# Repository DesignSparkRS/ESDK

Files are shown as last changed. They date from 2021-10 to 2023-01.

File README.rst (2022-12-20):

Environmental Sensor Development Kit (ESDK)
===========================================

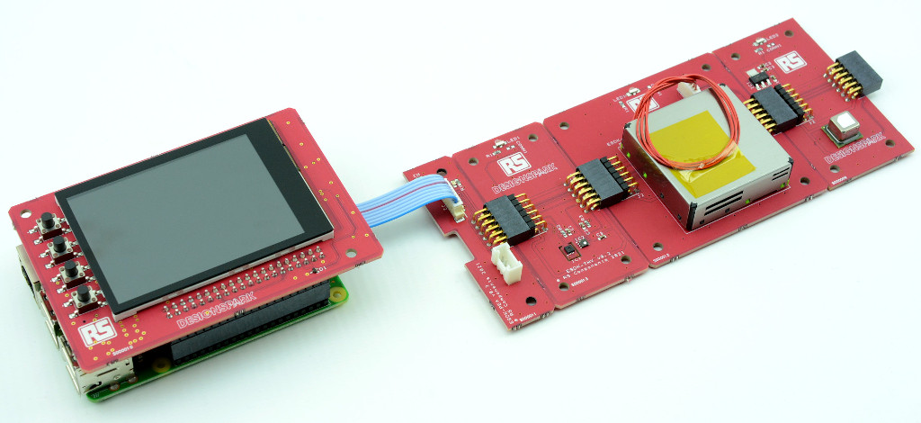
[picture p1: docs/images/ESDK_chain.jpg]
ESDK System


The Environmental Sensor Development Kit (ESDK) is an open source hardware
platform that is designed to make it as easy as possible to prototype custom
sensor solutions. It has been created to support the engineer activism Air
Quality project, but could easily be put to use in other sensing projects — and
for that matter, potentially a great many more IoT and wider applications that
have a need for a small Linux computer with integrated touchscreen and GPS etc.

Components
----------

The system is based upon a Raspberry Pi SBC fitted with the ESDK-Main board, which provides a touch screen, physical buttons, RTC, buzzer and sensor power supply. This is then connected to a sensor chain, with sensors interfaced via I2C and/or plain GPIO. 

Hardware Designs 
----------------

The ESDK hardware designs are entered using `DesignSpark PCB`_. 

The original design files and manufacturing outputs may be found in the GitHub repository:

https://github.com/DesignSparkRS/ESDK

Project Documentation
---------------------

Documentation is available on `docs.designspark.io`_.

Licensing
=========

Hardware
--------

Copyright 2021-2022 RS Components Ltd
SPDX-License-Identifier: Apache-2.0 WITH SHL-2.1

Licensed under the Solderpad Hardware License v 2.1 (the “License”); you may not
use this file except in compliance with the License, or, at your option, the
Apache License version 2.0. You may obtain a copy of the License at

https://solderpad.org/licenses/SHL-2.1/

Unless required by applicable law or agreed to in writing, any work distributed
under the License is distributed on an “AS IS” BASIS, WITHOUT WARRANTIES OR
CONDITIONS OF ANY KIND, either express or implied. See the License for the
specific language governing permissions and limitations under the License.

Software
--------

Copyright 2021 RS Components Ltd and provided under the MIT License.

Documentation
-------------

Copyright 2021-2022 RS Components Ltd and provide under the Creative Commons Attribution 4.0 International (CC BY 4.0) license.

.. _DesignSpark PCB: https://www.rs-online.com/designspark/pcb-software
.. _docs.designspark.io: https://docs.designspark.io/projects/esdk-hardware/en/latest/

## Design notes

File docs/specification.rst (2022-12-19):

ESDK Module Specification
=========================

The ESDK module specification is as follows.

Physical
--------

Two board sizes are currently in use within the ESDK ecosystem, comprising of a "1U" and "2U" variant. A 1U module is 35x70mm and a 2U module is double the width at 70x70mm.

Four corner mounting holes are to be provided, spaced 6mm from each edge. The hole should be 3.2mm diameter, which allows suitable clearance for M3 fastening hardware.

Each corner of the board should be chamfered at a 45° angle, such that the length parallel to the chamfer equates to 2.121mm.

A 3mm keep-out should be present around the edge of the board where no components should be placed — this allows room for the case to sandwich the PCBA. Tracks & vias can however be placed within this zone, being mindful of any PCB fabrication rules specified by a board house.

Connectors
----------

Each ESDK module typically features a male and female 12-pin header. Typically Samtec parts TSW-106-08-G-D-RA and SSW-106-02-G-D-RA are used which form a mating pair. These should be centred on the vertical edge of the PCB with the male header facing left and female facing right. The male header should be positioned such that the pins align with the board edge (but should not protrude over) and the mating face of the female header should protrude 5.53mm beyond the PCB edge.

Connector positioning is somewhat critical to ensure that a solid connection is made, but the parts do not bottom out completely within each other which would increase the risk of damage resulting from knocks and bumps

Power
-----

Two power rails are currently present on the ESDK ecosystem connector — 3.3Vdc and 5Vdc. The 3.3Vdc rail is provided by an LD1117S33 regulator located on ESDK-MAIN and is fused with a 200mA polyfuse. The 5Vdc rail is provided directly from the USB-C power input on ESDK-MAIN and is fused with a 750mA polyfuse. Each supply rail features a TVS diode for additional protection.

Current draw should be kept as low as possible on both 3.3V and 5V rails. Boards that require more current should utilise the 5V rail and add their own local regulation — an example of this is the ESDK-CO2 board that features another LD1117S33 regulator connected to the 5V supply.

A power indicator LED should be present and connected to the module primary supply rail through some form of removable link. Either a Kingbright KPA-3010CGCK right angle green SMD LED for the 3.3V rail, or a Kingbright KPA-3010YC right angle orange SMD LED for the 5V rail.

The power indicator should be positioned at the top of the board with a small gap from the 3mm component setback. The indicator should be horizontally centred on the board.

I/O
---

I/O is usually provided via the I2C bus present that connects to Raspberry Pi I2C1. This bus utilises the pull-ups located on the Raspberry Pi and features a small TVS diode for additional ESD protection.

Two GPIO lines are extended from the Raspberry Pi - GPIO 20 which becomes ESDK GPIO 1 and GPIO 21 which becomes ESDK GPIO 2. These lines are protected by another TVS diode but are otherwise unbuffered and completely at the mercy of software written by a user, so care should be taken when designing a module to provide an adequate interface.

An example of a board that can utilise one of the ESDK GPIO lines is the ESDK-NRD which features an event output connected via a 1K ohm resistor to GPIO 1. The resistor offers some level of protection should the Pi GPIO be configured as a current source and the module GPIO configured as a current sink.

Addressing
----------

All modules with I2C should use unique device addresses. See :doc:`modules/index` for details of those currently in use. If any modules are developed that have address conflicts consider the use of an I2C address translator such as the Analog Devices LTC4316.

.. note::
	I2C address translators have not been tested but should work. Test and verify before designing in!

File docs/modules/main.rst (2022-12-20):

Main Board (Main)
=================

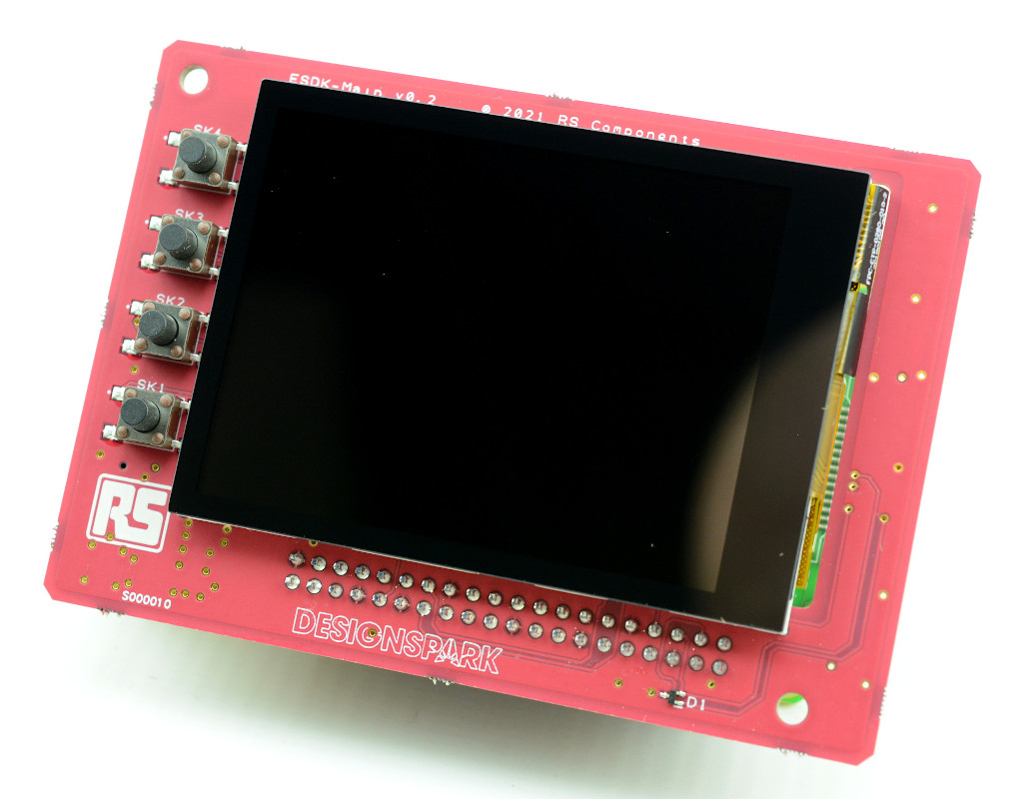
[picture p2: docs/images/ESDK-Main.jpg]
ESDK Main board


Introduction
------------

The Main board plugs into a Raspberry Pi SBC and provides:

* Touch screen
* Four physical buttons
* Battery backed real-time clock (RTC)
* Battery backed GPS
* Buzzer (from board v0.3 onwards)
* Sensor chain 3.3V and 5V power supply (from board v0.3 this is switched by MOSFETs under software control)
* Connector for cable to :doc:`pea`

Schematic diagram
-----------------

ESDK Main schematic diagram

Theory of operation
-------------------

The ESDK-MAIN board connects a number of peripherals to a Raspberry Pi P1 GPIO header including a 320x240 touchscreen over SPI and I2C, a battery-backed RTC connected over I2C, a GPS module connected over a UART (also supporting a 5V active antenna), four front panel buttons connected to GPIO lines, 3.3V and 5V sensor power rails switched by MOSFETs (from board v0.3 onwards), an on-board "HAT" EEPROM connected over I2C and USB-C for 5V power input.

The LCD, touchscreen, RTC and HAT EEPROM connect to I2C 0 on the Raspberry Pi, whereas the sensor string is connected to I2C 1 — this separation aims to avoid issues with the sensor string affecting operation of "system" devices. LCD backlight control is supported in software with further tweaks to the device tree overlay; GPIO 12 does support PWM to be able to adjust the brightness.

A 8-pin Molex PicoBlade connector is present for connection to the ESDK-PEA board that provides an external connector for the sensor modules.

For potential future use, a 5-pin Molex Pico-Lock connector can be used to enable battery expansion. This connector features the 5V rail inbound from the USB-C port, a 5V rail that heads out to the board plus a connection to I2C 0 for smart battery monitoring.

Board layout
------------

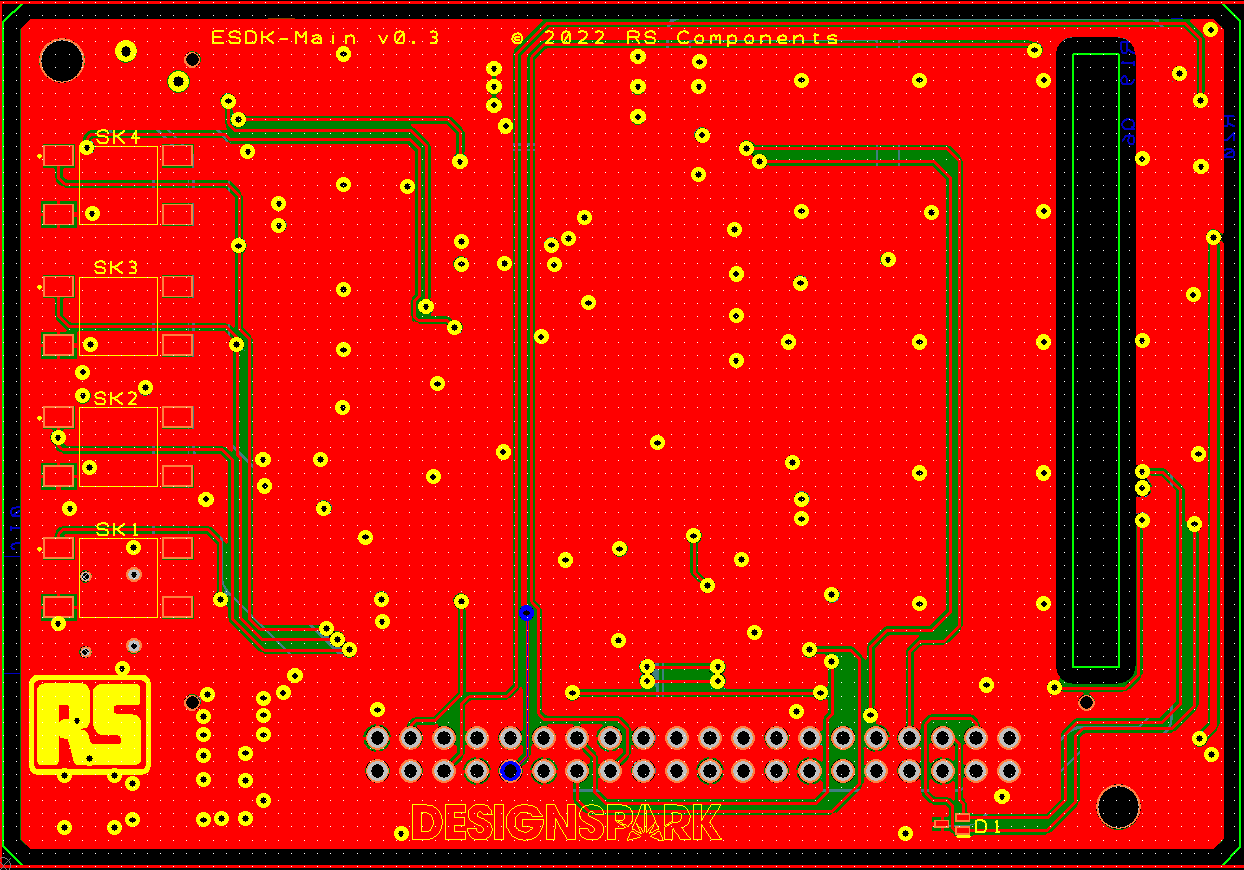
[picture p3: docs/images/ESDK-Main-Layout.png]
ESDK Main board layout


GPIO Assignments
----------------

+-------------------------------------------+-------------------+
| ESDK-MAIN Function                        | Raspberry Pi GPIO |
+===========================================+===================+
| TOUCH_RST                                 | 4                 |
+-------------------------------------------+-------------------+
| TOUCH_INT                                 | 17                |
+-------------------------------------------+-------------------+
| GPS_RESET                                 | 27                |
+-------------------------------------------+-------------------+
| GPS_STBY                                  | 22                |
+-------------------------------------------+-------------------+
| GPS_PPS                                   | 18                |
+-------------------------------------------+-------------------+
| BUTTON_1 (closest to board bottom)        | 5                 |
+-------------------------------------------+-------------------+
| BUTTON_2                                  | 6                 |
+-------------------------------------------+-------------------+
| BUTTON_3                                  | 13                |
+-------------------------------------------+-------------------+
| BUTTON_4 (closest to board top)           | 19                |
+-------------------------------------------+-------------------+
| LCD_RST                                   | 24                |
+-------------------------------------------+-------------------+
| LCD_DC                                    | 25                |
+-------------------------------------------+-------------------+
| LCD_BL                                    | 12                |
+-------------------------------------------+-------------------+
| GPIO_1                                    | 20                |
+-------------------------------------------+-------------------+
| GPIO_2                                    | 21                |
+-------------------------------------------+-------------------+
| SENSOR_3V3_EN (only used on later boards) | 7                 |
+-------------------------------------------+-------------------+
| SENSOR_5V_EN (only used on later boards)  | 16                |
+-------------------------------------------+-------------------+
| BUZZER (only used on later boards)        | 26                |
+-------------------------------------------+-------------------+

* The touchscreen I2C interface is connected to I2C 0
* The module I2C interface is connected to I2C 1
* The LCD is connected to SPI 0
* The GPS is connected to UART "serial0" which is the hardware UART on the Raspberry Pi

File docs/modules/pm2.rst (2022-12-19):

Particulate Matter Sensor (PM2)
===============================

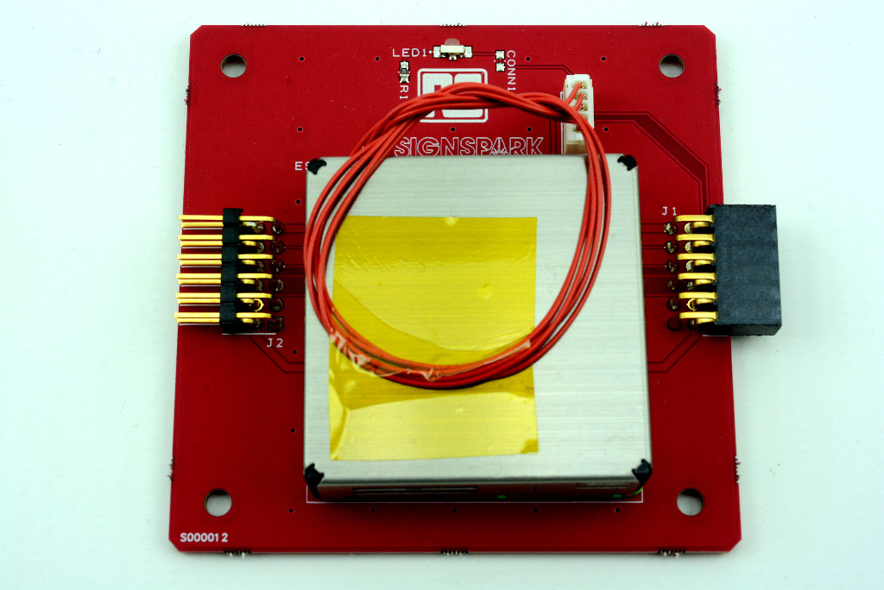
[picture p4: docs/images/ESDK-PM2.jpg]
ESDK PM2 board


Introduction
------------

The ESDK-PM2 features a Sensirion SPS30 particulate matter sensor that can count four different particulate sizes and reports these over an I2C interface.

Schematic diagram
-----------------

ESDK PM2 schematic diagram

Theory of operation
-------------------

The ESDK-PM2 board is primarily a passive board that only serves to convert the connector on the SPS30 sensor module into the ESDK ecosystem connector. The Sensirion SPS30 is capable of measuring PM1.0, PM2.5, PM4.0 and PM10 in densities ranging from 0-1000μg/m\ :sup:`3` with an accuracy up to ±10μg/m\ :sup:`3`.

This utilises a small fan to pull air and particulates through a measurement chamber that takes advantage of laser scattering to be able to count particles. The sensor can report both mass and number concentration, as well as the typical particle size over an I2C interface.

Board layout
------------

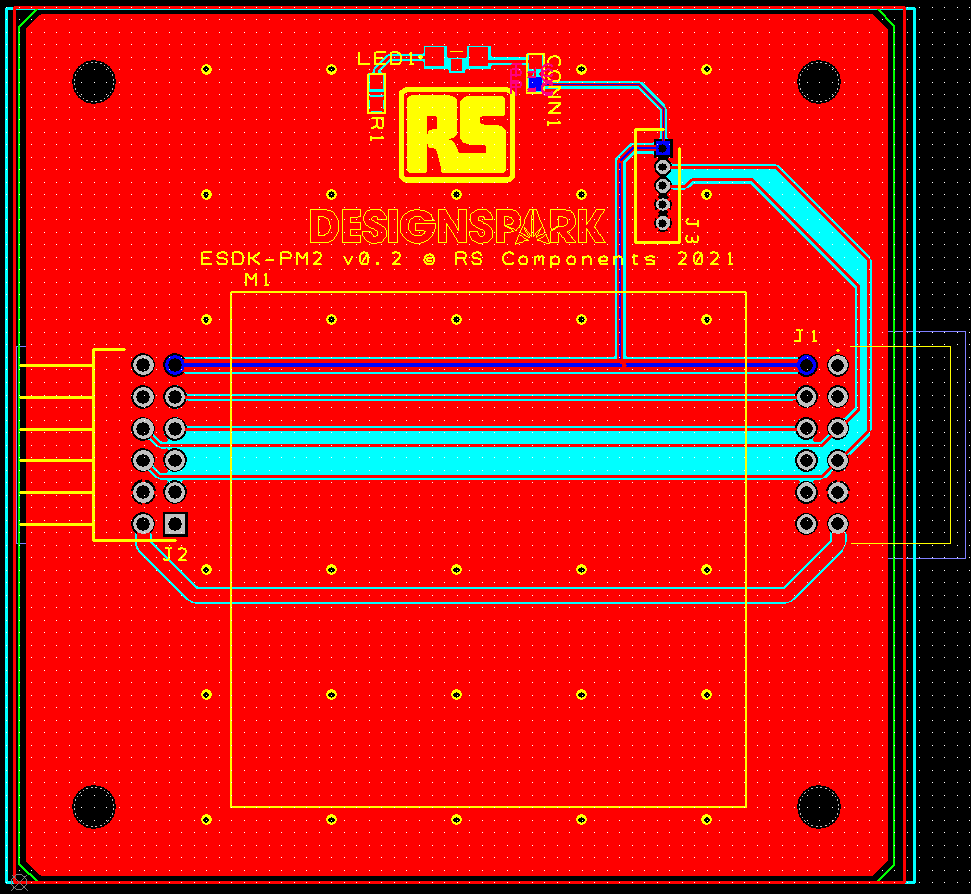
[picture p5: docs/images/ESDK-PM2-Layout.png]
ESDK PM2 board layout


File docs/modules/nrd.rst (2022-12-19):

Nuclear Radiation Detector (NRD)
================================

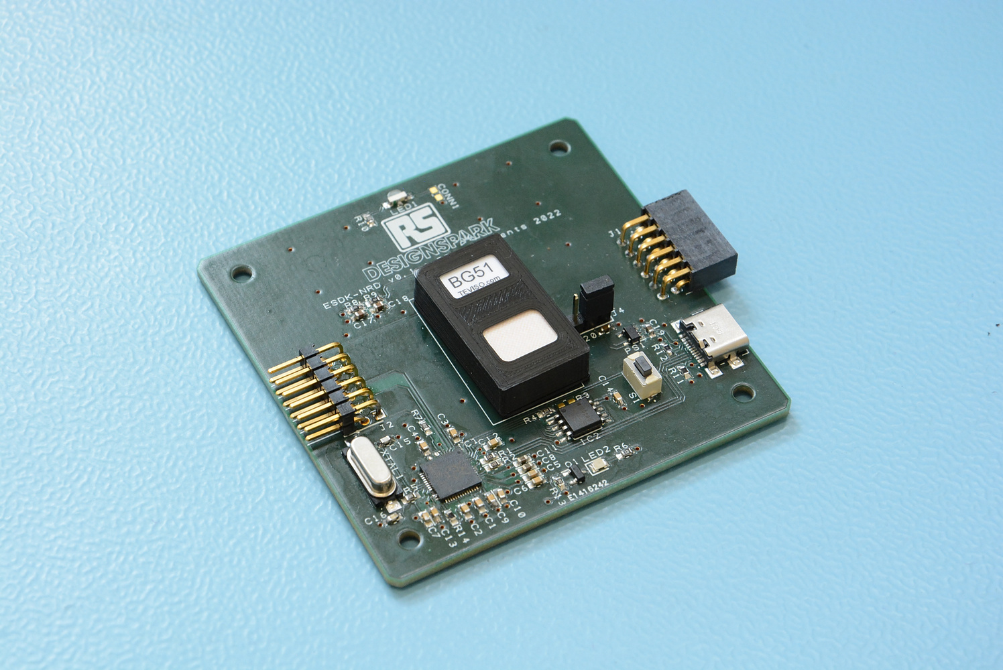
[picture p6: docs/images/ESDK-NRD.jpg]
ESDK NRD board


Introduction
------------

The ESDK-NRD board enables detection of nuclear radiation events, utilising a solid-state sensor that reduces the risk of using a sensing element that requires high voltage.

Schematic diagram
-----------------

ESDK NRD schematic diagram

Theory of operation
-------------------

The ESDK-NRD utilises a Teviso BG51 radiation sensor that is capable of detecting Beta and Gamma radiation. This sensor utilises an array of PIN photodiodes in a housing combined with circuitry to interface with the diodes to produce a TTL level pulse output. To bridge the gap between TTL pulse and I2C bus, a Raspberry Pi RP2040 microcontroller runs a MicroPython application that keeps track of accumulated pulses and exposes a number of registers containing counts per second, per minute and total counts.

A GPIO pin is connected from the RP2040 to an on-board LED that can be software enabled/disabled to provide an indication of a count event. An additional GPIO is connected through a 1K ohm resistor to the ESDK GPIO 1 line allowing for custom triggering to be set up should a user wish to modify the MicroPython application. A USB-C connector provides a USB connection to the RP2040 to allow for easy reprogramming, plus the ability to run the device standalone using a USB virtual com port. A four layer PCB is used to make routing easier and to achieve the required USB differential impedance of 90 ohms.

Board layout
------------

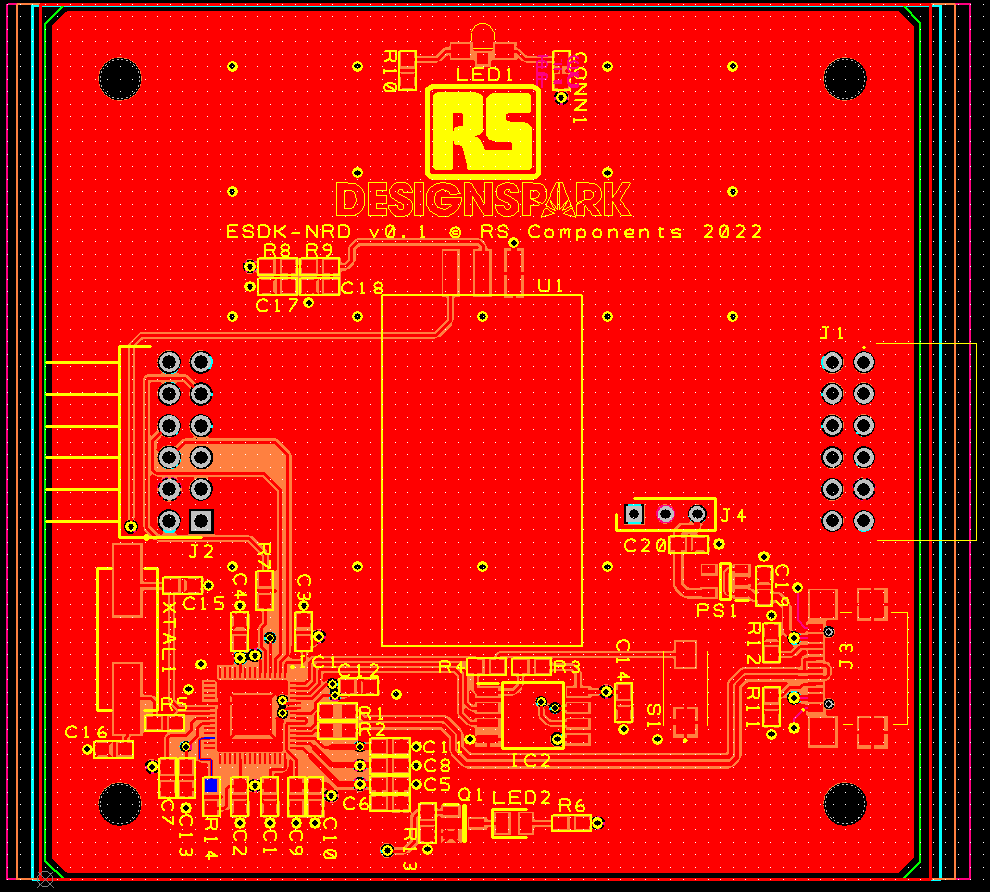
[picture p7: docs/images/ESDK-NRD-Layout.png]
ESDK NRD board layout


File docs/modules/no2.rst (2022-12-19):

Nitrogen Dioxide Sensor (NO2)
=============================

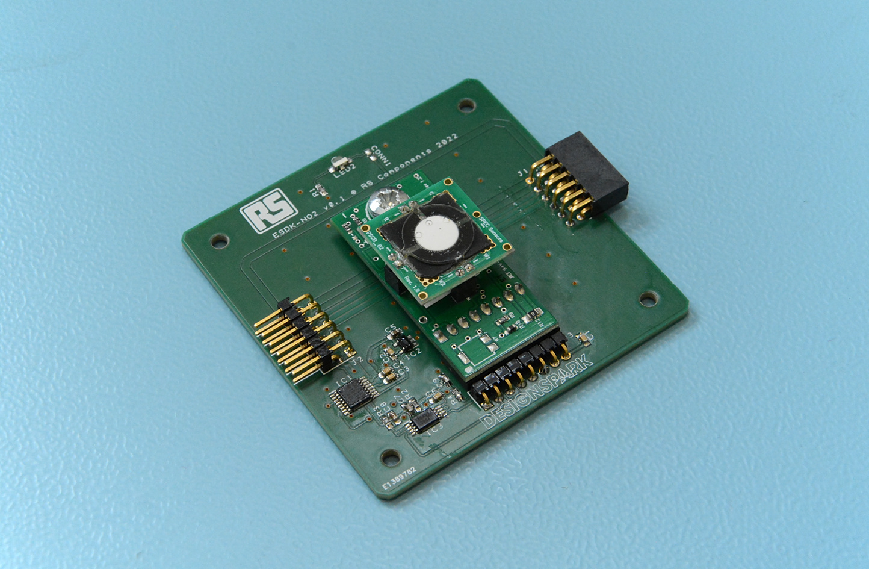
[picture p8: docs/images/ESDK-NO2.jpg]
ESDK NO2 board


Introduction
------------

The ESDK-NO2 board measures atmospheric nitrogen dioxide levels using an electrochemical cell that produces a current from a redox reaction.

Schematic diagram
-----------------

ESDK NO2 schematic diagram

Theory of operation
-------------------

A SPEC Sensors ULPSM-NO2 module provides an interface to the electrochemical cell that converts the current output into a linear voltage output. As this signal from the ULPSM module is high impedance, a unity-gain amplifier configuration buffers the signal before being fed into an ADS1119 16-bit, four channel ADC that is polled over the I2C bus.

Board layout
------------

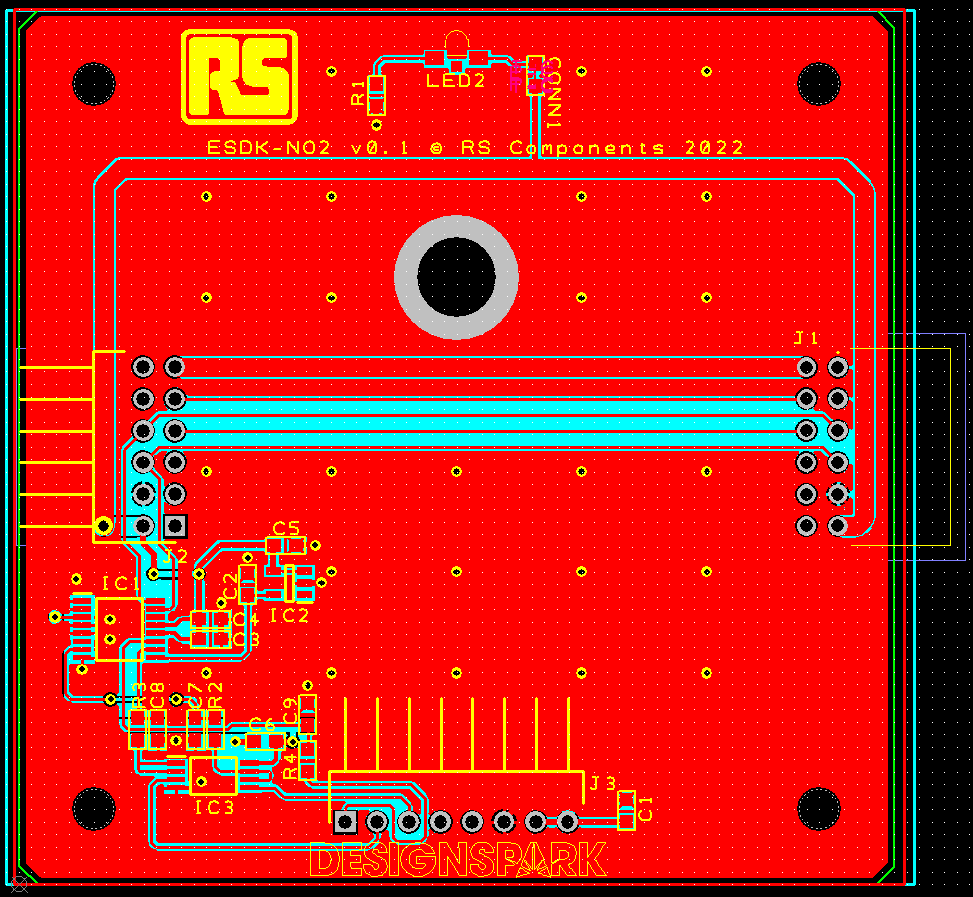
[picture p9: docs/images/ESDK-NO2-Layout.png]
ESDK NO2 board layout


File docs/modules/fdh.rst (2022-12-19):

Formaldehyde Sensor (FDH)
=========================

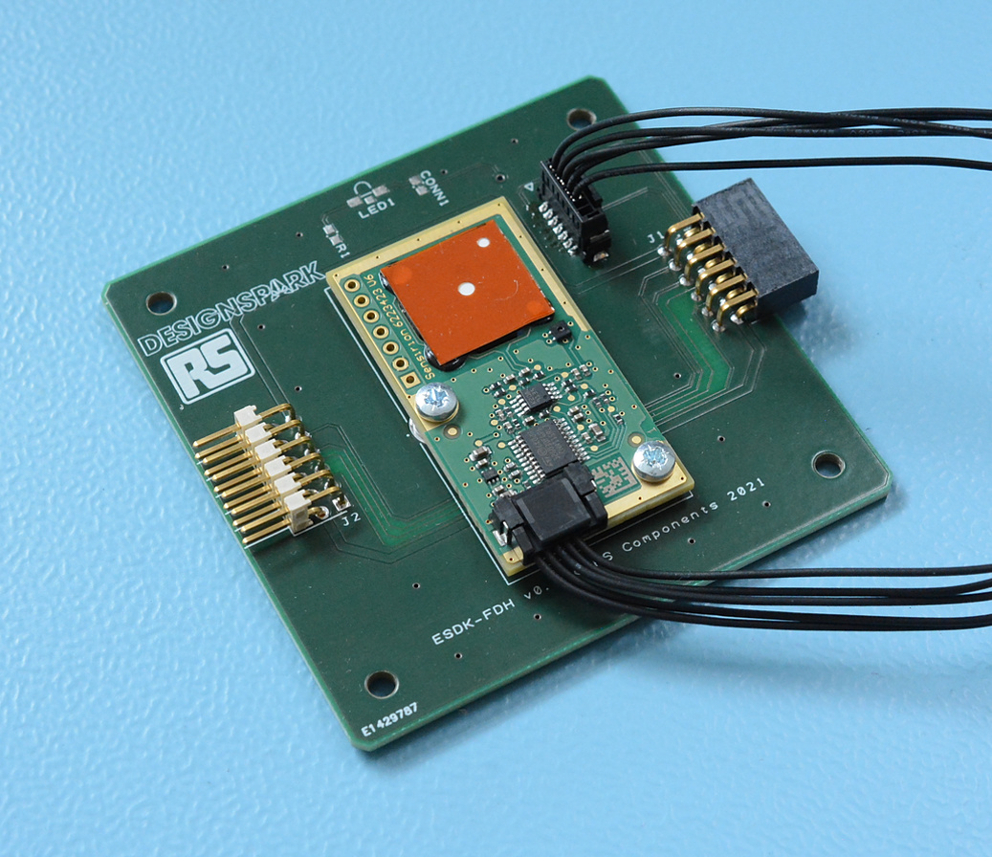
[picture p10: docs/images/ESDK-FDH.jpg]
ESDK FDH board


Introduction
------------

The ESDK-FDH board utilises a Sensirion SFA30 formaldehyde detection module that makes use of an electrochemical sensing cell.

Schematic diagram
-----------------

ESDK FDH schematic diagram

Theory of operation
-------------------

The ESDK-FDH board is primarily an interface board between the connector on the SFA30 module and the ESDK ecosystem connector. The Sensirion SFA30 module is capable of measuring formaldehyde concentrations from 0-1000ppb with a stated accuracy of ±20 ppb or ±20% m.v., whichever is larger. A temperature and relative humidity sensor is also provided on the module (mainly for use by the module microcontroller) but these are also exposed over the I2C bus.

The sensing element features a quoted lifespan of greater than six years provided the conditions are kept at standard conditions of 50 ±5% RH and 25 ±3°C.

Board layout
------------

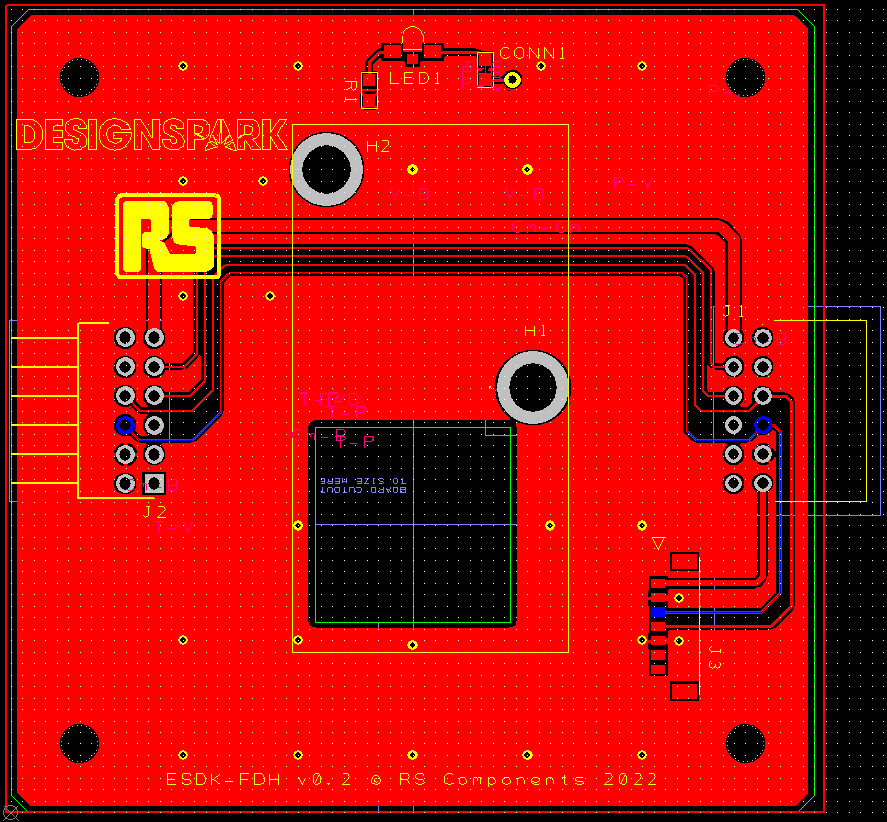
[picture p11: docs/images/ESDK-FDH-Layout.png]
ESDK FDH board layout


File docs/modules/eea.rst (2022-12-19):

ESDK Ecosystem Adapter (EEA)
============================

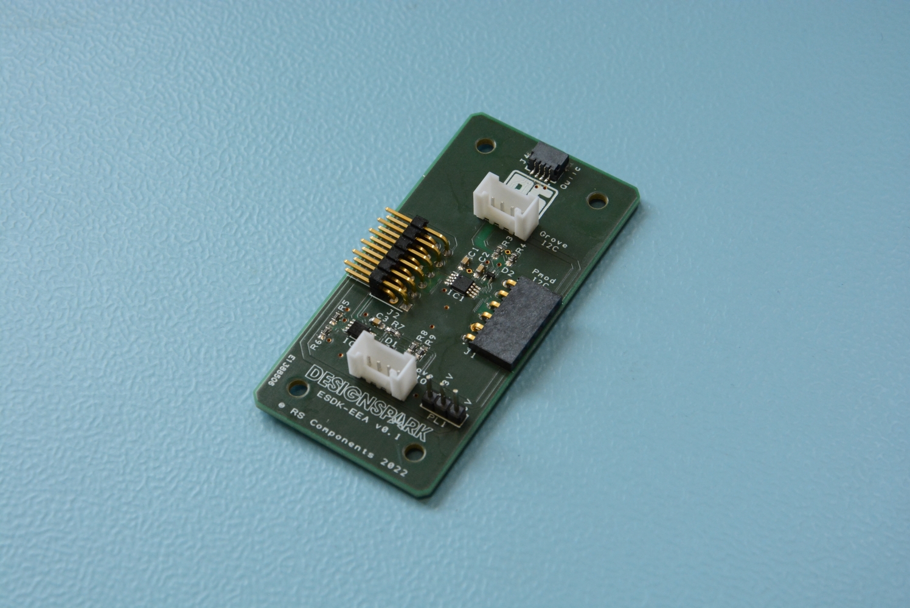
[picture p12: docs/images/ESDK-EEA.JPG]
ESDK EEA board


Introduction
------------

The ESDK-to-ecosystem adapter board is designed to be used at the end of a sensor chain and transitions from the ESDK system connector to:

* Pmod I2C
* Grove I2C
* Grove GPIO
* Qwiic (I2C)

As such it enables convenient interfacing of third party modules.

Schematic diagram
-----------------

ESDK EEA schematic diagram

Theory of operation
-------------------

The ESDK-EEA provides a buffered I2C interface that can support hot-plugging without corruption of the I2C bus. An NXP PCA9508DP is utilised to effect this, combined with a dual TVS diode for additional ESD protection. The two ESDK GPIO lines are also buffered by a bidirectional voltage translator that allows for both input and output with a selectable IO voltage of 3.3V or 5V. An additional TVS diode offers additional protection for the GPIO lines.

Board layout
------------

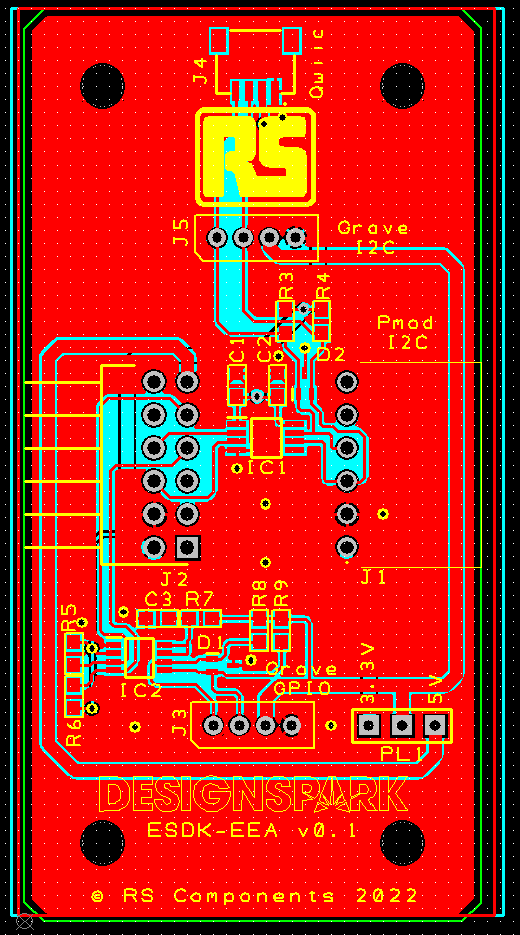
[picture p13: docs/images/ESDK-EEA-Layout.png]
ESDK EEA board layout


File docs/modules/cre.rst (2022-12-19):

Cabled Range Extender (CRE)
===========================

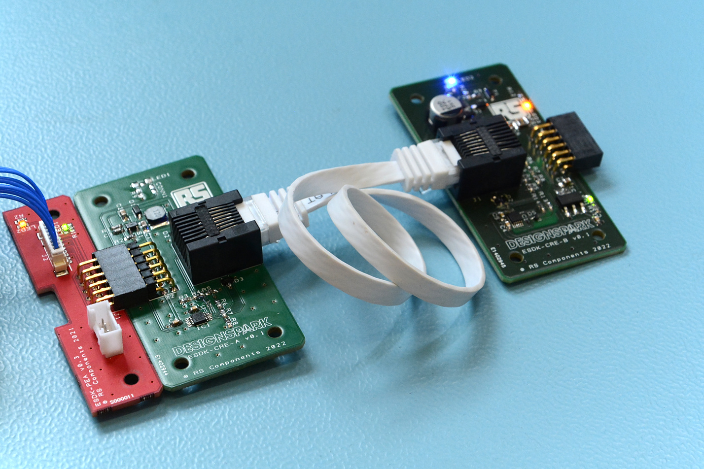
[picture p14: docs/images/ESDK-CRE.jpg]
ESDK CRE board set


Introduction
------------

The CRE board set is comprised of an *A* end plus a *B* end. The former is connected to the end of the local sensor chain and provides an RJ45 connector for extending the chain via twisted pair (CAT5/CAT6) cabling. 

The *B* board connects to the other end of the twisted pair cabling and enables sensor modules to be connected remotely.

The boards transition from single-ended I2C to differential signalling, and then back again. In addition to which the CRE-A boosts the power supply voltage so as to account for any cable losses, with the CRE-B board providing voltage regulation for the remotely connected sensors. 

.. warning:: 
   Sensors which use plain GPIO for interfacing may not be used at the remote end.

CRE-A schematic diagram
-----------------------

ESDK CRE-A schematic diagram

CRE-A theory of operation
-------------------------

The ESDK-CRE-A board converts the single-ended ESDK I2C bus into two differential signals for transmission down a CAT5e/CAT6 cable using an NXP PCA9615 driver plus bias network comprising of six resistors. TVS diodes are present on the differential side to help reduce the risk of ESD related damage. 

A DC-DC boost converter takes a 5V supply and produces 12V at up to 0.3A for transmission down the signal cable to help reduce losses. This utilises a Texas Instruments LMR62014 boost converter controller with integrated MOSFET switch, simplifying the design. A polyfuse is present on the 12V output to help reduce the risk should an inadvertent short circuit happen.

The right-hand facing female header is instead replaced with a standard RJ45 connector to enable the use of straight through network cables.

CRE-A board layout
------------------

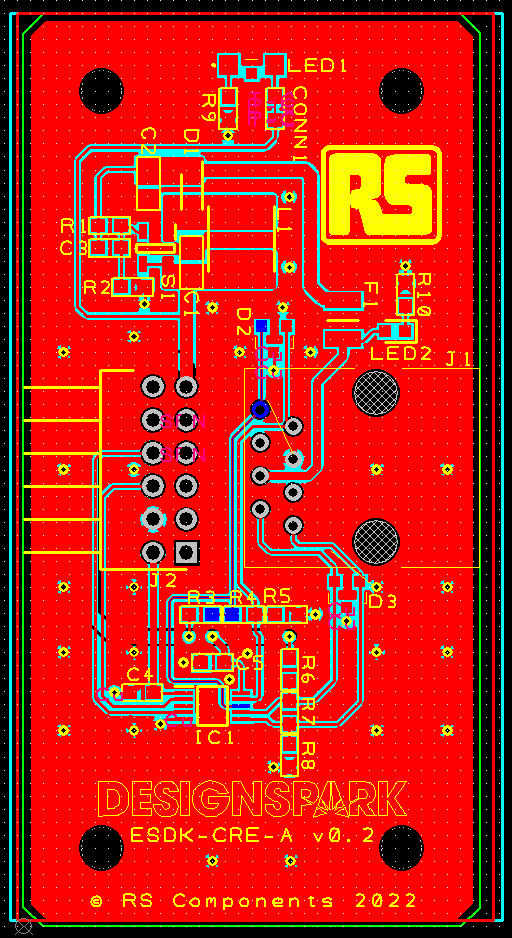
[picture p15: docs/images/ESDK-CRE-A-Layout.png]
ESDK CRE-A board layout


CRE-B schematic diagram
-----------------------

ESDK CRE-B schematic diagram

CRE-B theory of operation
-------------------------

The ESDK-CRE-B board performs the inverse function of the CRE-A board — it converts the incoming differential I2C bus back into a single ended bus whilst also producing 5V and 3.3V sensor power supply rails. A matching NXP PCA9615 driver plus bias netowrk is used to convert the bus, plus ESD diodes on both differential and single-ended sides of the bus to help reduce the risk of ESD damage. 

A Texas Instruments LMR12010 DC-DC buck converter with integrated switch first produces a steady 5V rail, which is then passed through a LD1117S33 linear regulator to produce 3.3V. A fuse is present on the 5V rail to reduce the risk of inadvertent short circuits.

CRE-B board layout
------------------

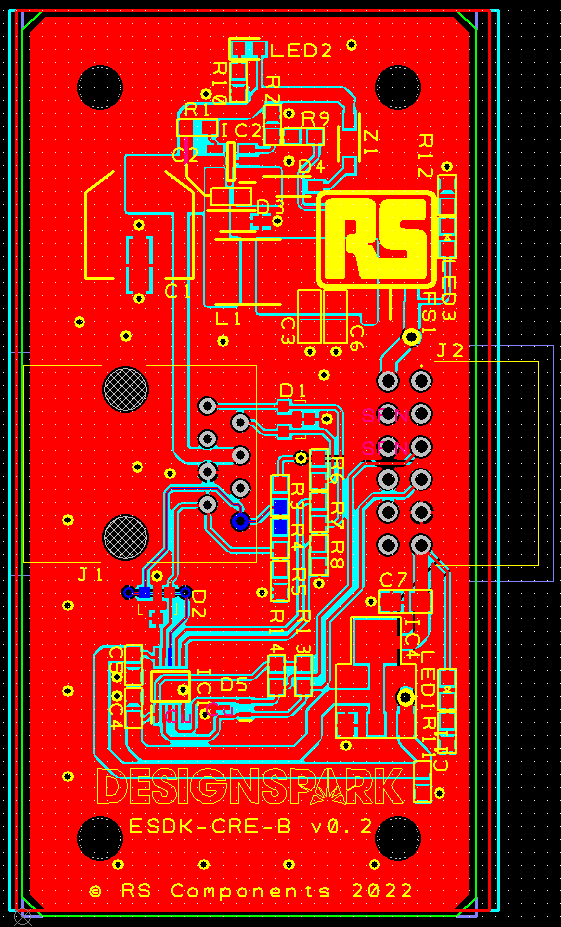
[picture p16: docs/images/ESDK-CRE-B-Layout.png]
ESDK CRE-B board layout


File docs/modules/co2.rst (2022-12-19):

Carbon Dioxide Sensor (CO2)
===========================

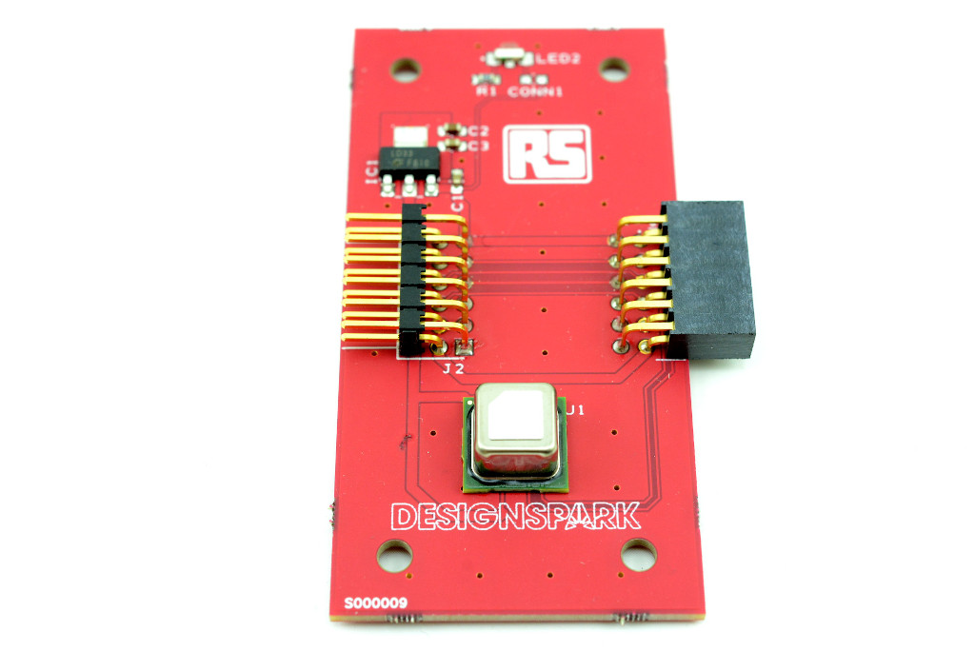
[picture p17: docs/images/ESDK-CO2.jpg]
ESDK CO2 board


Introduction
------------

The ESDK-CO2 board provides CO\ :sub:`2` measuring capability to the ESDK platform, utilising a Sensirion SCD41 sensor.

Schematic diagram
-----------------

ESDK CO2 schematic diagram

Theory of operation
-------------------

This board features a single sensor, the Sensirion SCD41, that utilises NDIR technology to measure atmospheric CO\ :sub:`2` levels with a specified range of 400-5000ppm and a quoted accuracy of ±40ppm + 5%. On the ESDK-CO2 board, an additional 3.3V regulator is present due to the high current peaks of up to 205mA that the sensor can require during measurements.

Board layout
------------

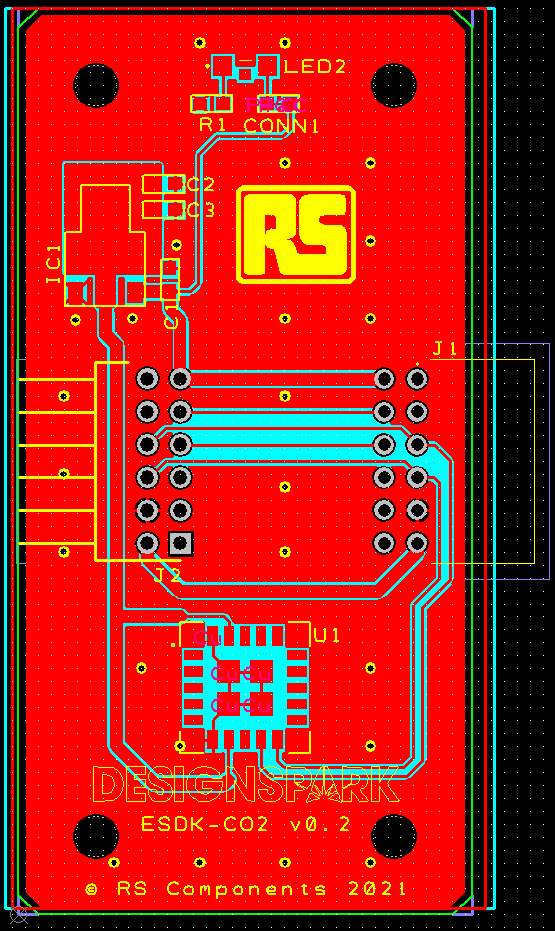
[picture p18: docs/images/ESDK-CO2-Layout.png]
ESDK CO2 board layout


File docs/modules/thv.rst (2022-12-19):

Temperature, humidity and VOCs Sensor (THV)
===========================================

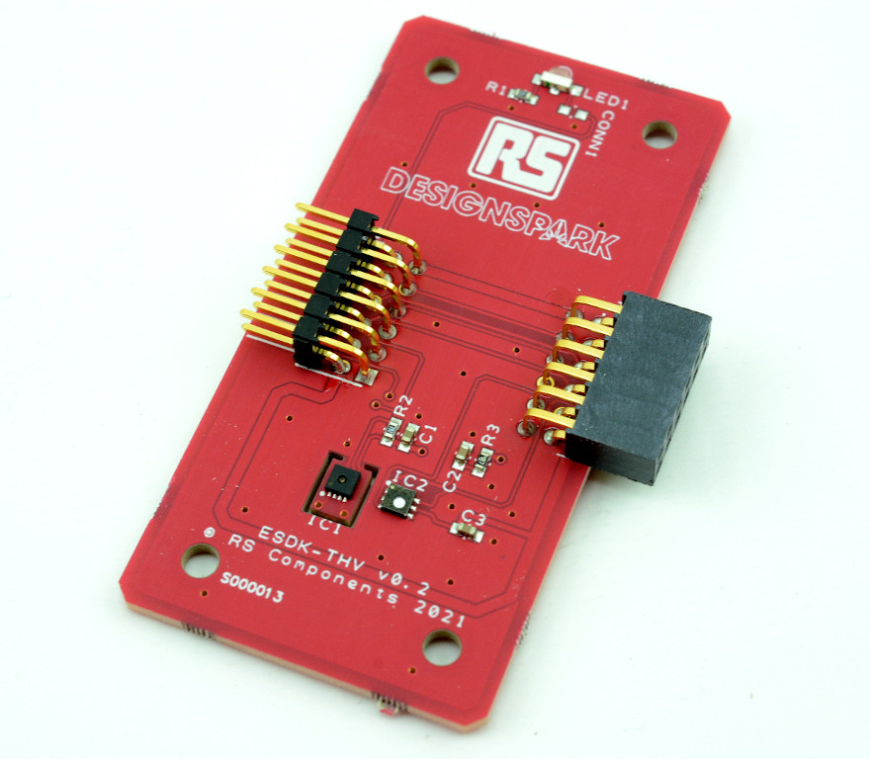
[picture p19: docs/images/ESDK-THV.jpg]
ESDK THV board


Introduction
------------

The ESDK-THV board provides two sensors that report a total of three metrics including

* Temperature
* Relative humidity
* Volatile Organic Compounds (VOCs)

Schematic diagram
-----------------

ESDK THV schematic diagram

Theory of operation
-------------------

The ESDK-THV utilises a Sensirion SHT31 to provide temperature and relative humidity measurements accurate to 2% RH and 0.2°C. A Sensirion SGP40 provides a processed sensor output with an "VOC Index" unit from 0-500, with an ethanol equivalent measuring range of 0-1000ppm. Further reading about the Sensirion "VOC Index" measurement can be found here_.

To help reduce thermal influence from the PCB, the SHT31 is mounted on a tab routed out of the board with only small traces connecting 3.3V/GND/I2C.

Both sensors appear on the I2C bus with separate addresses of 0x41 for the SHT31 and 0x59 for the SGP40.

Board layout
------------

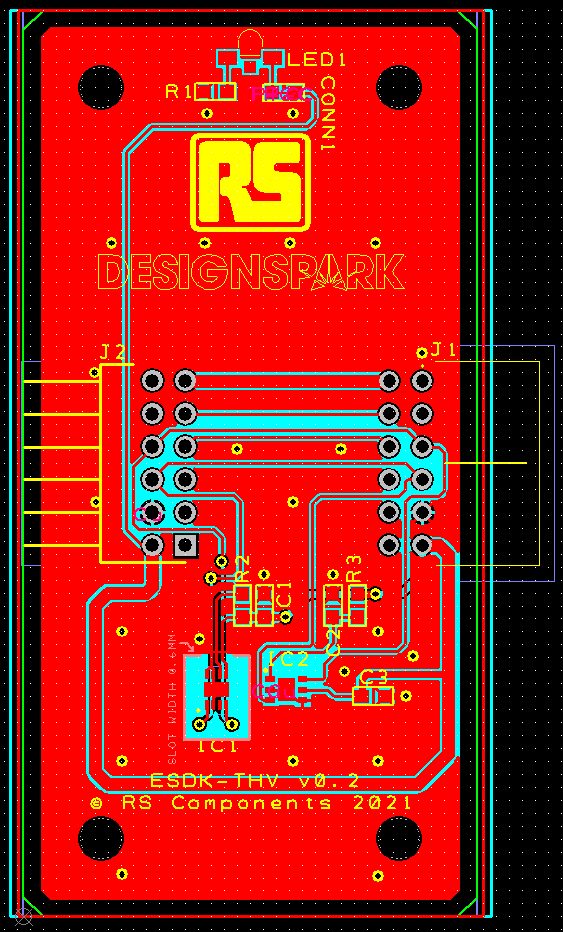
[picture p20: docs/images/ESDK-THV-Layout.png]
ESDK THV board layout


.. _here: https://sensirion.com/media/documents/02232963/6294E043/Info_Note_VOC_Index.pdf

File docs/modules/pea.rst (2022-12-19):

Sensor Chain Adapter (PEA)
==========================

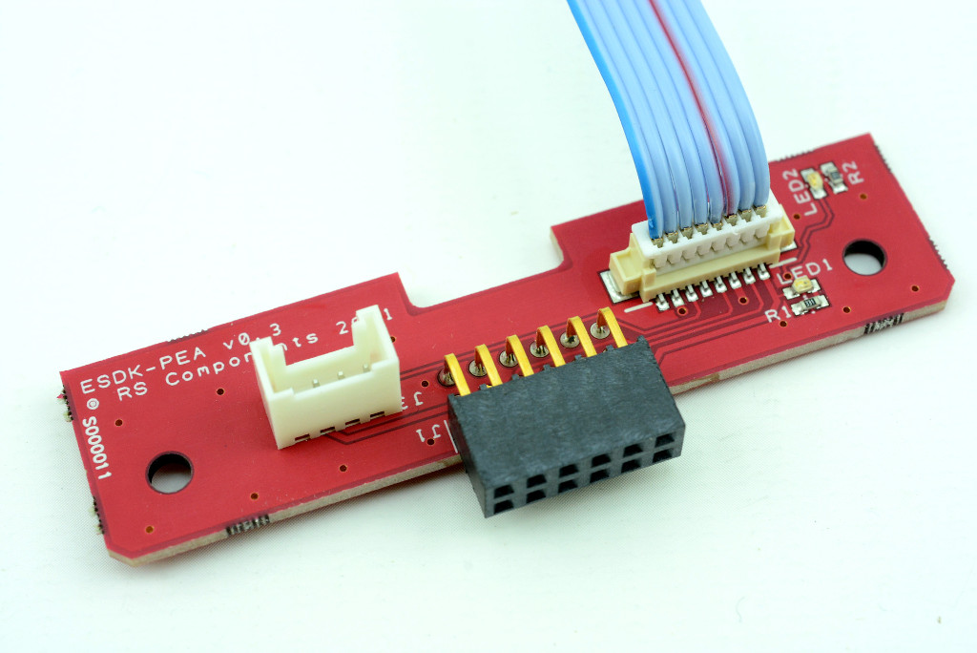
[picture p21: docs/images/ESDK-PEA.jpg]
ESDK PEA board


Introduction
------------

The PEA board is cabled to the :doc:`main` and provides the start of the sensor chain. It also features:

* LEDs for the 3.3V and 5V rails
* A Grove system GPIO connector 

Schematic diagram
-----------------

ESDK PEA schematic diagram

Theory of operation
-------------------

The ESDK-EEA acts as a simple pass-through board that connects the I2C bus coming from the ESDK-MAIN board to a Samtec SSW-106-02-G-D-RA 12-pin right-angle connector to interface with the sensor modules. 

Board layout
------------

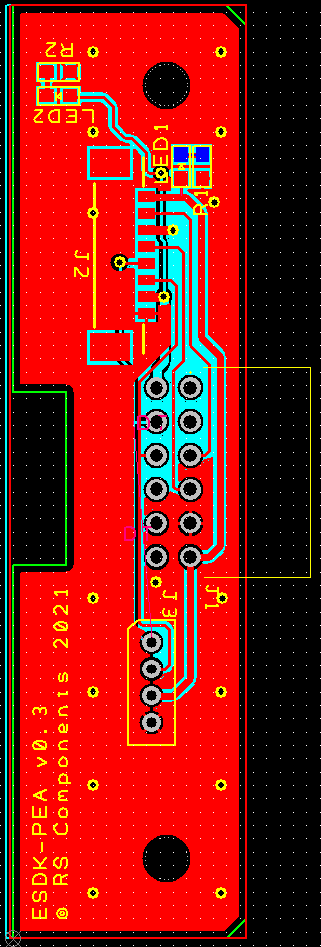
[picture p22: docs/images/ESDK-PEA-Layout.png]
ESDK PEA board layout


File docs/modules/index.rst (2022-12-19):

ESDK System
===========

The ESDK Main board plugs into the P1 header of a Raspberry Pi 3, 3+ or 4 Model B. However, it is not technically a 'HAT', since its proportions are such that it is too large to confirm to the official specification.

The sensor chain starts with the PEA board and this is cabled to the Main board. This board exists so as to permit the sensor chain to be positioned at the same Z-height as the Raspberry Pi SBC, rather than the ESDK-Main board.

The sensor chain may optionally be extended over longer distances using the Cabled Range Extender (CRE) board set.

Modules
-------

.. list-table:: ESDK Modules
   :header-rows: 1
   :widths: 5 30 10 10

   * - Name
     - Description
     - I2C
     - GPIO
   * - :doc:`Main <main>`
     - Main board
     - 0x38 for LCD touchscreen, 0x68 for RTC
     - Multiple, see documentation for main board
   * - :doc:`PEA <pea>`
     - Sensor chain start
     - N/A 
     - N/A 
   * - :doc:`THV <thv>`
     - Temperature, humidity and VOCs sensor
     - 0x41 for SHT31 temperature & humidity, 0x59 for SGP40 VOC
     - N/A
   * - :doc:`CO2 <co2>`
     - Carbon dioxide sensor
     - 0x62
     - N/A
   * - :doc:`PM2 <pm2>`
     - Particulate matter sensor
     - 0x69
     - N/A
   * - :doc:`NO2 <no2>`
     - Nitrogen dioxide sensor
     - 0x40
     - N/A
   * - :doc:`FDH <fdh>`
     - Formaldehyde sensor
     - 0x5D
     - N/A
   * - :doc:`NRD <nrd>`
     - Nuclear radiation detector
     - 0x60
     - ESDK GPIO 1 (Raspberry Pi GPIO 20) — optional, enabled and disabled through software
   * - :doc:`CRE <cre>`
     - Cabled range extenders
     - N/A 
     - N/A 
   * - :doc:`EEA <eea>`
     - Ecosystem adapter board
     - N/A 
     - N/A 

.. toctree::
   :hidden:

   main
   pea
   thv
   co2
   pm2
   no2
   fdh
   nrd
   cre
   eea

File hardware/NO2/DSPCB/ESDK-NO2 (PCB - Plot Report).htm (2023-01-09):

## Plot Report

Report Written: | Monday, January 09, 2023
Project Path: | C:\Users\Callum\Documents\GitHub\ESDK\hardware\NO2\DSPCB\ESDK-NO2.prj
Design Path: | C:\Users\Callum\Documents\GitHub\ESDK\hardware\NO2\DSPCB\ESDK-NO2.pcb
Design Title:
Created: | 05/08/2021 11:32:18
Last Saved: | 09/01/2023 15:45:30
Editing Time: | 8835 min
Units: | mm (precision 3)

## Device Settings

### Gerber Settings

Leading zero suppression.
G01 assumed throughout.
Line termination <*> .
3.5 format absolute inches.
Format commands defined in Gerber file.
Aperture table defined in Gerber file.
Hardware arcs allowed.

### Drill Settings

Excellon Format 2
Format 3.5 absolute in mm.
Zero suppression Leading

## Plots Output

Plot Job: "C:\Users\Callum\Documents\GitHub\ESDK\hardware\NO2\DSPCB\ESDK-NO2.mop"

### Gerber Output

C:\Users\Callum\Documents\GitHub\ESDK\hardware\NO2\DSPCB\Outputs\ESDK-NO2 - Top Silkscreen 09-01-2023.gbr

Layers:
Top Silkscreen

D-Code | Shape (thou)
D10 | Round 7.87
D22 | Round 5.00
D23 | Round 3.94
D24 | Round 1.00
D25 | Round 0.00

### Gerber Output

C:\Users\Callum\Documents\GitHub\ESDK\hardware\NO2\DSPCB\Outputs\ESDK-NO2 - Top Copper 09-01-2023.gbr

Layers:
Top Copper

D-Code | Shape (thou)
D10 | Round 7.87
D11 | Round 10.00
D12 | Round 35.43 Hole 19.69
D15 | Round 61.02 Hole 40.94
D22 | Round 5.00
D26 | Round 19.69
D27 | Round 11.81
D28 | Round 9.84
D29 | Round 59.06
D72 | Round 60.00 Hole 35.00
D73 | Square 64.96 Hole 43.31
D74 | Round 64.96 Hole 43.31
D75 | Rectangle 39.37 X 42.91
D76 | Rectangle 43.31 X 59.06 Rotation 90
D77 | Square 35.43
D78 | Rectangle 17.72 X 58.07 Rotation 90
D79 | Rectangle 23.62 X 47.24 Rotation 90
D80 | Rectangle 39.37 X 42.91 Rotation 90
D81 | Round 393.70 Hole 250.00

### Gerber Output

C:\Users\Callum\Documents\GitHub\ESDK\hardware\NO2\DSPCB\Outputs\ESDK-NO2 - Top Copper (Resist) 09-01-2023.gbr

Layers:
Top Copper

D-Code | Shape (thou)
D82 | Round 126.02
D83 | Round 61.06
D84 | Square 65.00
D85 | Round 65.00
D86 | Rectangle 39.41 X 42.95
D87 | Rectangle 43.35 X 59.09 Rotation 90
D88 | Square 35.47
D89 | Rectangle 17.76 X 58.11 Rotation 90
D90 | Rectangle 23.66 X 47.28 Rotation 90
D91 | Rectangle 39.41 X 42.95 Rotation 90
D92 | Round 393.74

### Gerber Output

C:\Users\Callum\Documents\GitHub\ESDK\hardware\NO2\DSPCB\Outputs\ESDK-NO2 - Top Paste 09-01-2023.gbr

Layers:
Top Paste

D-Code | Shape (thou)
D93 | Rectangle 35.43 X 38.98
D94 | Rectangle 38.98 X 54.72 Rotation 90
D95 | Square 31.89
D96 | Rectangle 15.94 X 56.30 Rotation 90
D97 | Rectangle 21.26 X 44.88 Rotation 90
D98 | Rectangle 35.43 X 38.98 Rotation 90

### Gerber Output

C:\Users\Callum\Documents\GitHub\ESDK\hardware\NO2\DSPCB\Outputs\ESDK-NO2 - Bottom Copper 09-01-2023.gbr

Layers:
Bottom Copper

D-Code | Shape (thou)
D10 | Round 7.87
D11 | Round 10.00
D12 | Round 35.43 Hole 19.69
D13 | Round 39.37
D15 | Round 61.02 Hole 40.94
D26 | Round 19.69
D28 | Round 9.84
D29 | Round 59.06
D72 | Round 60.00 Hole 35.00
D73 | Square 64.96 Hole 43.31
D74 | Round 64.96 Hole 43.31
D81 | Round 393.70 Hole 250.00

### Gerber Output

C:\Users\Callum\Documents\GitHub\ESDK\hardware\NO2\DSPCB\Outputs\ESDK-NO2 - Bottom Resist 09-01-2023.gbr

Layers:
Bottom Resist

D-Code | Shape (thou)
D17 | Round 41.43 Hole 19.69
D19 | Round 131.98 Hole 125.98
D70 | Round 67.02 Hole 40.94
D99 | Round 66.00 Hole 35.00
D100 | Square 70.96 Hole 43.31
D101 | Round 70.96 Hole 43.31
D102 | Round 399.70 Hole 250.00

### NC Drill Output

C:\Users\Callum\Documents\GitHub\ESDK\hardware\NO2\DSPCB\Outputs\ESDK-NO2 - NC Drill Data - [Through Hole] 09-01-2023.drl

Output:

Plated Round Drill Holes

Plated Slots

Tool | Size | Count | ID
T001 | 0.01969 inches | 44 | F
T002 | 0.03500 inches | 1 | R
T003 | 0.04094 inches | 12 | H
T004 | 0.04331 inches | 20 | C
Total | | 77

C:\Users\Callum\Documents\GitHub\ESDK\hardware\NO2\DSPCB\Outputs\ESDK-NO2 - NC Drill Data - [Through Hole] 09-01-2023 (Unplated).drl

Output:

Unplated Round Drill Holes

Unplated Slots

Tool | Size | Count | ID
T001 | 0.12598 inches | 4 | B
T002 | 0.25000 inches | 1 | X
Total | | 5

### Gerber Output

C:\Users\Callum\Documents\GitHub\ESDK\hardware\NO2\DSPCB\Outputs\ESDK-NO2 - Drill Ident Drawing - [Through Hole] 09-01-2023.gbr

Layers:
[Through Hole]

### Drill Ident Drawing

Drill | Plated | Size | Shape | ID
126 | | 100 | Round | B
43 | Y | 100 | Round | C
20 | Y | 100 | Round | F
41 | Y | 100 | Round | H
35 | Y | 100 | Round | R
250 | | 100 | Round | X

D-Code | Shape (thou)
D21 | Round 100.00
D22 | Round 5.00

### Gerber Output

C:\Users\Callum\Documents\GitHub\ESDK\hardware\NO2\DSPCB\Outputs\ESDK-NO2 - Outline 09-01-2023.gbr

Layers:
Board Outlines

D-Code | Shape (thou)
D22 | Round 5.00

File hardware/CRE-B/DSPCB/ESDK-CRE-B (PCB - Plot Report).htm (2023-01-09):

## Plot Report

Report Written: | Monday, January 09, 2023
Project Path: | C:\Users\Callum\Documents\GitHub\ESDK\hardware\CRE-B\DSPCB\ESDK-CRE-B.prj
Design Path: | C:\Users\Callum\Documents\GitHub\ESDK\hardware\CRE-B\DSPCB\ESDK-CRE-B.pcb
Design Title:
Created: | 05/08/2021 09:51:21
Last Saved: | 09/01/2023 15:59:36
Editing Time: | 13113 min
Units: | mm (precision 3)

## Device Settings

### Gerber Settings

Leading zero suppression.
G01 assumed throughout.
Line termination <*> .
3.5 format absolute inches.
Format commands defined in Gerber file.
Aperture table defined in Gerber file.
Hardware arcs allowed.

### Drill Settings

Excellon Format 2
Format 3.5 absolute in inches.
Zero suppression Leading

## Plots Output

### Gerber Output

C:\Users\Callum\Documents\GitHub\ESDK\hardware\CRE-B\DSPCB\Outputs\ESDK-CRE-B - Top Silkscreen 09-01-2023.gbr

Layers:
Top Silkscreen

D-Code | Shape (thou)
D10 | Round 7.87
D28 | Round 5.00
D29 | Round 3.94
D72 | Round 1.00
D126 | Round 1.97

### Gerber Output

C:\Users\Callum\Documents\GitHub\ESDK\hardware\CRE-B\DSPCB\Outputs\ESDK-CRE-B - Top Copper 09-01-2023.gbr

Layers:
Top Copper

D-Code | Shape (thou)
D10 | Round 7.87
D11 | Round 10.00
D12 | Round 35.43 Hole 19.69
D13 | Round 39.37
D18 | Round 61.02 Hole 40.94
D28 | Round 5.00
D75 | Round 23.62
D79 | Rectangle 55.00 X 60.00
D81 | Rectangle 31.50 X 45.28
D82 | Rectangle 39.37 X 42.91 Rotation 90
D85 | Rectangle 39.37 X 42.91
D89 | Square 33.46
D90 | Square 37.40
D127 | Round 15.75
D128 | Round 11.81
D129 | Round 29.53
D130 | Round 56.00 Hole 32.00
D131 | Round 31.50
D132 | Rectangle 11.81 X 55.12
D133 | Round 51.30 Hole 29.92
D134 | Rectangle 23.62 X 49.21 Rotation 90
D135 | Rectangle 62.99 X 157.48
D136 | Rectangle 31.50 X 45.28 Rotation 90
D137 | Rectangle 88.58 X 188.98
D138 | Rectangle 34.65 X 110.63
D139 | Rectangle 47.24 X 62.99
D140 | Rectangle 129.92 X 129.92
D141 | Rectangle 55.00 X 60.00 Rotation 90
D142 | Rectangle 15.75 X 35.43 Rotation 90

### Gerber Output

C:\Users\Callum\Documents\GitHub\ESDK\hardware\CRE-B\DSPCB\Outputs\ESDK-CRE-B - Top Copper (Resist) 09-01-2023.gbr

Layers:
Top Copper

D-Code | Shape (thou)
D143 | Round 126.02
D144 | Round 61.06
D145 | Rectangle 39.41 X 42.95 Rotation 90
D146 | Rectangle 11.85 X 55.16
D147 | Rectangle 39.41 X 42.95
D148 | Rectangle 55.04 X 60.04
D149 | Square 37.44
D152 | Round 51.34
D153 | Round 65.98
D154 | Square 33.50
D155 | Rectangle 23.66 X 49.25 Rotation 90
D156 | Rectangle 63.03 X 157.52
D157 | Rectangle 31.54 X 45.31 Rotation 90
D158 | Rectangle 88.62 X 189.02
D159 | Rectangle 31.54 X 45.31
D160 | Rectangle 34.69 X 110.67
D161 | Rectangle 47.28 X 63.03
D162 | Rectangle 129.96 X 129.96
D163 | Rectangle 55.04 X 60.04 Rotation 90
D164 | Rectangle 15.79 X 35.47 Rotation 90

### Gerber Output

C:\Users\Callum\Documents\GitHub\ESDK\hardware\CRE-B\DSPCB\Outputs\ESDK-CRE-B - Top Paste 09-01-2023.gbr

Layers:
Top Paste

D-Code | Shape (thou)
D28 | Round 5.00
D109 | Rectangle 49.50 X 54.50
D111 | Rectangle 28.35 X 42.13
D112 | Rectangle 35.43 X 38.98 Rotation 90
D114 | Rectangle 35.43 X 38.98
D118 | Square 30.12
D119 | Square 33.66
D148 | Rectangle 10.63 X 53.94
D149 | Rectangle 21.26 X 46.85 Rotation 90
D152 | Rectangle 56.69 X 151.18
D153 | Rectangle 28.35 X 42.13 Rotation 90
D154 | Rectangle 79.72 X 180.12
D155 | Rectangle 31.18 X 107.17
D156 | Rectangle 42.52 X 58.27
D157 | Rectangle 116.93 X 116.93
D158 | Rectangle 49.50 X 54.50 Rotation 90
D159 | Rectangle 14.17 X 33.86 Rotation 90

### Gerber Output

C:\Users\Callum\Documents\GitHub\ESDK\hardware\CRE-B\DSPCB\Outputs\ESDK-CRE-B - Bottom Copper 09-01-2023.gbr

Layers:
Bottom Copper

D-Code | Shape (thou)
D10 | Round 7.87
D11 | Round 10.00
D12 | Round 35.43 Hole 19.69
D13 | Round 39.37
D14 | Round 56.00 Hole 32.00
D15 | Round 61.02 Hole 40.94
D16 | Round 51.30 Hole 29.92

### Gerber Output

C:\Users\Callum\Documents\GitHub\ESDK\hardware\CRE-B\DSPCB\Outputs\ESDK-CRE-B - Bottom Resist 09-01-2023.gbr

Layers:
Bottom Resist

D-Code | Shape (thou)
D17 | Round 41.43 Hole 19.69
D18 | Round 62.00 Hole 32.00
D19 | Round 131.98 Hole 125.98
D70 | Round 67.02 Hole 40.94
D71 | Round 57.30 Hole 29.92
D20 | Round 71.94 Hole 131.89

### NC Drill Output

C:\Users\Callum\Documents\GitHub\ESDK\hardware\CRE-B\DSPCB\Outputs\ESDK-CRE-B - NC Drill Data - [Through Hole] 09-01-2023.drl

Output:

Plated Round Drill Holes

Plated Slots

Tool | Size | Count | ID
T001 | 0.01969 inches | 38 | F
T002 | 0.02992 inches | 8 | D
T003 | 0.03200 inches | 2 | G
T004 | 0.04094 inches | 12 | H
T005 | 0.13189 inches | 2 | E
Total | | 62

C:\Users\Callum\Documents\GitHub\ESDK\hardware\CRE-B\DSPCB\Outputs\ESDK-CRE-B - NC Drill Data - [Through Hole] 09-01-2023 (Unplated).drl

Output:

Unplated Round Drill Holes

Unplated Slots

Tool | Size | Count | ID
T001 | 0.12598 inches | 4 | B
Total | | 4

### Gerber Output

C:\Users\Callum\Documents\GitHub\ESDK\hardware\CRE-B\DSPCB\Outputs\ESDK-CRE-B - Drill Ident Drawing - [Through Hole] 09-01-2023.gbr

Layers:
[Through Hole]

### Drill Ident Drawing

Drill | Plated | Size | Shape | ID
126 | | 100 | Round | B
30 | Y | 100 | Round | D
132 | Y | 100 | Round | E
20 | Y | 100 | Round | F
32 | Y | 100 | Round | G
41 | Y | 100 | Round | H

D-Code | Shape (thou)
D21 | Round 100.00
D22 | Round 5.00

### Gerber Output

C:\Users\Callum\Documents\GitHub\ESDK\hardware\CRE-B\DSPCB\Outputs\ESDK-CRE-B - Outline 09-01-2023.gbr

Layers:
Board Outlines

D-Code | Shape (thou)
D22 | Round 5.00

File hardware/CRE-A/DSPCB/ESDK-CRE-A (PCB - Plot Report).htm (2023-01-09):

## Plot Report

Report Written: | Monday, January 09, 2023
Project Path: | C:\Users\Callum\Documents\GitHub\ESDK\hardware\CRE-A\DSPCB\ESDK-CRE-A.prj
Design Path: | C:\Users\Callum\Documents\GitHub\ESDK\hardware\CRE-A\DSPCB\ESDK-CRE-A.pcb
Design Title:
Created: | 05/08/2021 09:51:21
Last Saved: | 09/01/2023 15:53:40
Editing Time: | 7384 min
Units: | mm (precision 3)

## Device Settings

### Gerber Settings

Leading zero suppression.
G01 assumed throughout.
Line termination <*> .
3.5 format absolute inches.
Format commands defined in Gerber file.
Aperture table defined in Gerber file.
Hardware arcs allowed.

### Drill Settings

Excellon Format 2
Format 3.5 absolute in mm.
Zero suppression Leading

## Plots Output

Plot Job: "C:\Users\Callum\Documents\GitHub\ESDK\hardware\CRE-A\DSPCB\ESDK-CRE-A.mop"

### Gerber Output

C:\Users\Callum\Documents\GitHub\ESDK\hardware\CRE-A\DSPCB\Outputs\ESDK-CRE-A - Top Silkscreen 09-01-2023.gbr

Layers:
Top Silkscreen

D-Code | Shape (thou)
D10 | Round 7.87
D28 | Round 5.00
D29 | Round 3.94
D72 | Round 1.00

### Gerber Output

C:\Users\Callum\Documents\GitHub\ESDK\hardware\CRE-A\DSPCB\Outputs\ESDK-CRE-A - Top Copper 09-01-2023.gbr

Layers:
Top Copper

D-Code | Shape (thou)
D10 | Round 7.87
D13 | Round 39.37
D14 | Round 19.69
D28 | Round 5.00
D73 | Round 20.00
D74 | Round 32.00
D75 | Round 23.62
D76 | Square 64.96
D77 | Round 64.96
D78 | Rectangle 23.62 X 47.24
D79 | Rectangle 55.00 X 60.00
D80 | Rectangle 88.58 X 188.98 Rotation 90
D81 | Rectangle 31.50 X 45.28
D82 | Rectangle 39.37 X 42.91 Rotation 90
D83 | Round 51.30
D84 | Rectangle 11.81 X 55.12 Rotation 90
D85 | Rectangle 39.37 X 42.91
D86 | Square 59.06
D87 | Square 35.43
D88 | Rectangle 46.46 X 110.63 Rotation 90
D89 | Square 33.46
D90 | Square 37.40

### Gerber Output

C:\Users\Callum\Documents\GitHub\ESDK\hardware\CRE-A\DSPCB\Outputs\ESDK-CRE-A - Top Copper (Resist) 09-01-2023.gbr

Layers:
Top Copper

D-Code | Shape (thou)
D91 | Round 135.98
D92 | Square 74.96
D93 | Round 74.96
D94 | Rectangle 33.62 X 57.24
D95 | Rectangle 65.00 X 70.00
D96 | Rectangle 98.58 X 198.98 Rotation 90
D97 | Rectangle 41.50 X 55.28
D98 | Rectangle 49.37 X 52.91 Rotation 90
D99 | Round 61.30
D100 | Round 75.94
D101 | Rectangle 21.81 X 65.12 Rotation 90
D102 | Rectangle 49.37 X 52.91
D103 | Square 69.06
D104 | Square 45.43
D105 | Rectangle 56.46 X 120.63 Rotation 90
D106 | Square 43.46
D107 | Square 47.40

### Gerber Output

C:\Users\Callum\Documents\GitHub\ESDK\hardware\CRE-A\DSPCB\Outputs\ESDK-CRE-A - Top Paste 09-01-2023.gbr

Layers:
Top Paste

D-Code | Shape (thou)
D108 | Rectangle 21.26 X 44.88
D109 | Rectangle 49.50 X 54.50
D110 | Rectangle 79.72 X 180.12 Rotation 90
D111 | Rectangle 28.35 X 42.13
D112 | Rectangle 35.43 X 38.98 Rotation 90
D113 | Rectangle 10.63 X 53.94 Rotation 90
D114 | Rectangle 35.43 X 38.98
D115 | Square 53.15
D116 | Square 31.89
D117 | Rectangle 41.81 X 105.98 Rotation 90
D118 | Square 30.12
D119 | Square 33.66

### Gerber Output

C:\Users\Callum\Documents\GitHub\ESDK\hardware\CRE-A\DSPCB\Outputs\ESDK-CRE-A - Bottom Copper 09-01-2023.gbr

Layers:
Bottom Copper

D-Code | Shape (thou)
D10 | Round 7.87
D13 | Round 39.37
D74 | Round 32.00
D76 | Square 64.96
D77 | Round 64.96
D83 | Round 51.30

### Gerber Output

C:\Users\Callum\Documents\GitHub\ESDK\hardware\CRE-A\DSPCB\Outputs\ESDK-CRE-A - Bottom Resist 09-01-2023.gbr

Layers:
Bottom Resist

D-Code | Shape (thou)
D120 | Round 38.00
D121 | Round 131.98
D122 | Square 70.96
D123 | Round 70.96
D124 | Round 57.30
D125 | Round 71.94

### NC Drill Output

C:\Users\Callum\Documents\GitHub\ESDK\hardware\CRE-A\DSPCB\Outputs\ESDK-CRE-A - NC Drill Data - [Through Hole] 09-01-2023.drl

Output:

Plated Round Drill Holes

Plated Slots

Tool | Size | Count | ID
T001 | 0.01600 inches | 41 | A
T002 | 0.02992 inches | 8 | D
T003 | 0.04331 inches | 12 | C
T004 | 0.13189 inches | 2 | E
Total | | 63

C:\Users\Callum\Documents\GitHub\ESDK\hardware\CRE-A\DSPCB\Outputs\ESDK-CRE-A - NC Drill Data - [Through Hole] 09-01-2023 (Unplated).drl

Output:

Unplated Round Drill Holes

Unplated Slots

Tool | Size | Count | ID
T001 | 0.12598 inches | 4 | B
Total | | 4

### Gerber Output

C:\Users\Callum\Documents\GitHub\ESDK\hardware\CRE-A\DSPCB\Outputs\ESDK-CRE-A - Drill Ident Drawing - [Through Hole] 09-01-2023.gbr

Layers:
[Through Hole]

### Drill Ident Drawing

Drill | Plated | Size | Shape | ID
16 | Y | 100 | Round | A
126 | | 100 | Round | B
43 | Y | 100 | Round | C
30 | Y | 100 | Round | D
132 | Y | 100 | Round | E

D-Code | Shape (thou)
D27 | Round 100.00
D28 | Round 5.00

### Gerber Output

C:\Users\Callum\Documents\GitHub\ESDK\hardware\CRE-A\DSPCB\Outputs\ESDK-CRE-A - Outline 09-01-2023.gbr

Layers:
Board Outlines

D-Code | Shape (thou)
D28 | Round 5.00

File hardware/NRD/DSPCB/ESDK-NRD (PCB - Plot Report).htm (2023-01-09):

## Plot Report

Report Written: | Monday, January 09, 2023
Project Path: | C:\Users\Callum\Documents\GitHub\ESDK\hardware\NRD\DSPCB\ESDK-NRD.prj
Design Path: | C:\Users\Callum\Documents\GitHub\ESDK\hardware\NRD\DSPCB\ESDK-NRD.pcb
Design Title:
Created: | 05/08/2021 11:32:18
Last Saved: | 09/01/2023 15:36:32
Editing Time: | 7808 min
Units: | mm (precision 3)

## Device Settings

### Gerber Settings

Leading zero suppression.
G01 assumed throughout.
Line termination <*> .
3.5 format absolute inches.
Format commands defined in Gerber file.
Aperture table defined in Gerber file.
Hardware arcs allowed.

### Drill Settings

Excellon Format 2
Format 3.5 absolute in mm.
Zero suppression Leading

## Plots Output

Plot Job: "C:\Users\Callum\Documents\GitHub\ESDK\hardware\NRD\DSPCB\ESDK-NRD.mop"

### Gerber Output

C:\Users\Callum\Documents\GitHub\ESDK\hardware\NRD\DSPCB\Outputs\ESDK-NRD - Top Silkscreen 09-01-2023.gbr

Layers:
Top Silkscreen

D-Code | Shape (thou)
D18 | Round 5.00
D19 | Round 3.94
D70 | Round 7.87
D71 | Round 15.75
D20 | Round 1.00
D21 | Round 0.00

### Gerber Output

C:\Users\Callum\Documents\GitHub\ESDK\hardware\NRD\DSPCB\Outputs\ESDK-NRD - Top Copper 09-01-2023.gbr

Layers:
Top Copper

D-Code | Shape (thou)
D18 | Round 5.00
D70 | Round 7.87
D22 | Round 10.00
D23 | Round 9.84
D24 | Round 19.69
D25 | Round 35.43
D26 | Round 11.81
D27 | Round 27.56
D28 | Round 13.78
D29 | Round 61.02
D72 | Square 64.96
D73 | Round 64.96
D74 | Rectangle 39.37 X 42.91 Rotation 90
D75 | Rectangle 43.31 X 59.06 Rotation 90
D76 | Square 35.43
D77 | Rectangle 39.37 X 42.91
D78 | Rectangle 7.87 X 33.46
D79 | Rectangle 7.87 X 33.46 Rotation 90
D80 | Square 125.98
D81 | Rectangle 25.59 X 64.96 Rotation 90
D82 | Rectangle 59.06 X 78.74
D83 | Rectangle 82.68 X 220.47
D84 | Rectangle 37.40 X 61.02
D85 | Rectangle 43.31 X 137.80
D86 | Rectangle 25.59 X 47.24 Rotation 90
D87 | Rectangle 11.81 X 45.28 Rotation 90
D88 | Rectangle 78.74 X 85.83
D89 | Rectangle 23.62 X 41.34 Rotation 90
D90 | Square 50.20
D91 | Round 50.20

### Gerber Output

C:\Users\Callum\Documents\GitHub\ESDK\hardware\NRD\DSPCB\Outputs\ESDK-NRD - Top Copper (Resist) 09-01-2023.gbr

Layers:
Top Copper

D-Code | Shape (thou)
D92 | Round 135.98
D93 | Round 71.02
D94 | Square 74.96
D95 | Round 74.96
D96 | Rectangle 49.37 X 52.91 Rotation 90
D97 | Rectangle 53.31 X 69.06 Rotation 90
D98 | Square 45.43
D99 | Rectangle 49.37 X 52.91
D100 | Rectangle 17.87 X 43.46
D101 | Rectangle 17.87 X 43.46 Rotation 90
D102 | Square 135.98
D103 | Rectangle 35.59 X 74.96 Rotation 90
D104 | Rectangle 69.06 X 88.74
D105 | Rectangle 92.68 X 230.47
D106 | Rectangle 47.40 X 71.02
D107 | Rectangle 53.31 X 147.80
D108 | Rectangle 35.59 X 57.24 Rotation 90
D109 | Rectangle 21.81 X 55.28 Rotation 90
D110 | Round 22.80
D111 | Rectangle 88.74 X 95.83
D112 | Rectangle 33.62 X 51.34 Rotation 90
D113 | Square 60.20
D114 | Round 60.20

### Gerber Output

C:\Users\Callum\Documents\GitHub\ESDK\hardware\NRD\DSPCB\Outputs\ESDK-NRD - Top Paste 09-01-2023.gbr

Layers:
Top Paste

D-Code | Shape (thou)
D115 | Rectangle 35.43 X 38.98 Rotation 90
D116 | Rectangle 38.98 X 54.72 Rotation 90
D117 | Square 31.89
D118 | Rectangle 35.43 X 38.98
D119 | Rectangle 7.09 X 32.68
D120 | Rectangle 7.09 X 32.68 Rotation 90
D121 | Square 113.39
D122 | Rectangle 23.03 X 62.40 Rotation 90
D123 | Rectangle 53.15 X 72.83
D124 | Rectangle 74.41 X 212.20
D125 | Rectangle 33.66 X 57.28
D126 | Rectangle 38.98 X 133.46
D127 | Rectangle 23.03 X 44.69 Rotation 90
D128 | Rectangle 10.63 X 44.09 Rotation 90
D129 | Rectangle 70.87 X 77.95
D130 | Rectangle 21.26 X 38.98 Rotation 90

### Gerber Output

C:\Users\Callum\Documents\GitHub\ESDK\hardware\NRD\DSPCB\Outputs\ESDK-NRD - Inner 1 09-01-2023.gbr

Layers:
Inner 1

D-Code | Shape (thou)
D18 | Round 5.00
D22 | Round 10.00
D25 | Round 35.43
D27 | Round 27.56
D29 | Round 61.02
D72 | Square 64.96
D73 | Round 64.96
D90 | Square 50.20
D91 | Round 50.20

### Gerber Output

C:\Users\Callum\Documents\GitHub\ESDK\hardware\NRD\DSPCB\Outputs\ESDK-NRD - Inner 2 09-01-2023.gbr

Layers:
Inner 2

D-Code | Shape (thou)
D18 | Round 5.00
D70 | Round 7.87
D22 | Round 10.00
D24 | Round 19.69
D25 | Round 35.43
D27 | Round 27.56
D29 | Round 61.02
D72 | Square 64.96
D73 | Round 64.96
D90 | Square 50.20
D91 | Round 50.20

### Gerber Output

C:\Users\Callum\Documents\GitHub\ESDK\hardware\NRD\DSPCB\Outputs\ESDK-NRD - Bottom Copper 09-01-2023.gbr

Layers:
Bottom Copper

D-Code | Shape (thou)
D70 | Round 7.87
D22 | Round 10.00
D23 | Round 9.84
D24 | Round 19.69
D25 | Round 35.43
D27 | Round 27.56
D29 | Round 61.02
D72 | Square 64.96
D73 | Round 64.96
D90 | Square 50.20
D91 | Round 50.20
D131 | Round 39.37

### Gerber Output

C:\Users\Callum\Documents\GitHub\ESDK\hardware\NRD\DSPCB\Outputs\ESDK-NRD - Bottom Resist 09-01-2023.gbr

Layers:
Bottom Resist

D-Code | Shape (thou)
D10 | Round 41.43
D12 | Round 131.98
D13 | Round 67.02
D14 | Square 70.96
D15 | Round 70.96
D132 | Round 33.56
D133 | Round 18.80
D134 | Square 56.20
D135 | Round 56.20

### NC Drill Output

C:\Users\Callum\Documents\GitHub\ESDK\hardware\NRD\DSPCB\Outputs\ESDK-NRD - NC Drill Data - [Through Hole] 09-01-2023.drl

Output:

Plated Round Drill Holes

Plated Slots

Tool | Size | Count | ID
T001 | 0.01772 inches | 9 | I
T002 | 0.01969 inches | 62 | F
T003 | 0.03346 inches | 3 | K
T004 | 0.04094 inches | 12 | H
T005 | 0.04331 inches | 12 | C
Total | | 98

C:\Users\Callum\Documents\GitHub\ESDK\hardware\NRD\DSPCB\Outputs\ESDK-NRD - NC Drill Data - [Through Hole] 09-01-2023 (Unplated).drl

Output:

Unplated Round Drill Holes

Unplated Slots

Tool | Size | Count | ID
T001 | 0.02559 inches | 2 | L
T002 | 0.12598 inches | 4 | B
Total | | 6

### Gerber Output

C:\Users\Callum\Documents\GitHub\ESDK\hardware\NRD\DSPCB\Outputs\ESDK-NRD - Drill Ident Drawing - [Through Hole] 09-01-2023.gbr

Layers:
[Through Hole]

### Drill Ident Drawing

Drill | Plated | Size | Shape | ID
126 | | 100 | Round | B
43 | Y | 100 | Round | C
20 | Y | 100 | Round | F
41 | Y | 100 | Round | H
18 | Y | 100 | Round | I
33 | Y | 100 | Round | K
26 | | 100 | Round | L

D-Code | Shape (thou)
D17 | Round 100.00
D18 | Round 5.00

### Gerber Output

C:\Users\Callum\Documents\GitHub\ESDK\hardware\NRD\DSPCB\Outputs\ESDK-NRD - Outline 09-01-2023.gbr

Layers:
Board Outlines

D-Code | Shape (thou)
D18 | Round 5.00

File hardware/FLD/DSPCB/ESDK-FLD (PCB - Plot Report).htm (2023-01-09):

## Plot Report

Report Written: | Monday, January 09, 2023
Project Path: | C:\Users\Callum\Documents\GitHub\ESDK\hardware\FLD\DSPCB\ESDK-FLD.prj
Design Path: | C:\Users\Callum\Documents\GitHub\ESDK\hardware\FLD\DSPCB\ESDK-FLD.pcb
Design Title:
Created: | 05/08/2021 11:32:18
Last Saved: | 09/01/2023 15:03:14
Editing Time: | 10465 min
Units: | mm (precision 3)

## Device Settings

### Gerber Settings

Leading zero suppression.
G01 assumed throughout.
Line termination <*> .
3.5 format absolute inches.
Format commands defined in Gerber file.
Aperture table defined in Gerber file.
Hardware arcs allowed.

### Drill Settings

Excellon Format 2
Format 3.5 absolute in inches.
Zero suppression Leading

## Plots Output

Plot Job: "C:\Users\Callum\Documents\GitHub\ESDK\hardware\FLD\DSPCB\ESDK-FLD.mop"

### Gerber Output

C:\Users\Callum\Documents\GitHub\ESDK\hardware\FLD\DSPCB\Outputs\ESDK-FLD - Top Silkscreen 09-01-2023.gbr

Layers:
Top Silkscreen

D-Code | Shape (thou)
D18 | Round 7.87
D29 | Round 5.00
D72 | Round 3.94
D73 | Round 1.00
D74 | Round 0.00

### Gerber Output

C:\Users\Callum\Documents\GitHub\ESDK\hardware\FLD\DSPCB\Outputs\ESDK-FLD - Top Copper 09-01-2023.gbr

Layers:
Top Copper

D-Code | Shape (thou)
D18 | Round 7.87
D19 | Round 10.00
D70 | Round 35.43
D71 | Round 19.69
D20 | Round 61.02
D21 | Square 64.96
D22 | Round 64.96
D29 | Round 5.00
D75 | Round 9.84
D76 | Round 39.37
D80 | Rectangle 39.37 X 42.91
D85 | Square 35.43
D134 | Round 56.00
D135 | Rectangle 31.50 X 47.24 Rotation 90
D136 | Rectangle 51.18 X 84.65 Rotation 90
D137 | Round 249.21
D138 | Rectangle 43.31 X 59.06 Rotation 90

### Gerber Output

C:\Users\Callum\Documents\GitHub\ESDK\hardware\FLD\DSPCB\Outputs\ESDK-FLD - Top Copper (Resist) 09-01-2023.gbr

Layers:
Top Copper

D-Code | Shape (thou)
D86 | Round 135.98
D87 | Round 71.02
D91 | Rectangle 49.37 X 52.91
D139 | Rectangle 41.50 X 57.24 Rotation 90
D140 | Rectangle 61.18 X 94.65 Rotation 90
D141 | Round 259.21
D150 | Square 74.96
D151 | Round 74.96
D152 | Rectangle 53.31 X 69.06 Rotation 90
D153 | Square 45.43

### Gerber Output

C:\Users\Callum\Documents\GitHub\ESDK\hardware\FLD\DSPCB\Outputs\ESDK-FLD - Top Paste 09-01-2023.gbr

Layers:
Top Paste

D-Code | Shape (thou)
D11 | Rectangle 38.98 X 54.72 Rotation 90
D12 | Square 31.89
D15 | Rectangle 35.43 X 38.98
D142 | Rectangle 28.35 X 44.09 Rotation 90
D143 | Rectangle 46.06 X 79.53 Rotation 90

### Gerber Output

C:\Users\Callum\Documents\GitHub\ESDK\hardware\FLD\DSPCB\Outputs\ESDK-FLD - Bottom Copper 09-01-2023.gbr

Layers:
Bottom Copper

D-Code | Shape (thou)
D18 | Round 7.87
D19 | Round 10.00
D70 | Round 35.43
D20 | Round 61.02
D21 | Square 64.96
D22 | Round 64.96
D75 | Round 9.84
D76 | Round 39.37
D134 | Round 56.00
D137 | Round 249.21

### Gerber Output

C:\Users\Callum\Documents\GitHub\ESDK\hardware\FLD\DSPCB\Outputs\ESDK-FLD - Bottom Resist 09-01-2023.gbr

Layers:
Bottom Resist

D-Code | Shape (thou)
D10 | Round 41.43
D11 | Round 62.00
D12 | Round 131.98
D13 | Round 67.02
D14 | Square 70.96
D15 | Round 70.96
D16 | Round 255.21

### NC Drill Output

C:\Users\Callum\Documents\GitHub\ESDK\hardware\FLD\DSPCB\Outputs\ESDK-FLD - NC Drill Data - [Through Hole] 09-01-2023.drl

Output:

Plated Round Drill Holes

Plated Slots

Tool | Size | Count | ID
T001 | 0.01969 inches | 24 | F
T002 | 0.03200 inches | 1 | G
T003 | 0.04094 inches | 12 | H
T004 | 0.04331 inches | 12 | C
T005 | 0.16614 inches | 2 | M
Total | | 51

C:\Users\Callum\Documents\GitHub\ESDK\hardware\FLD\DSPCB\Outputs\ESDK-FLD - NC Drill Data - [Through Hole] 09-01-2023 (Unplated).drl

Output:

Unplated Round Drill Holes

Unplated Slots

Tool | Size | Count | ID
T001 | 0.12598 inches | 4 | B
Total | | 4

### Gerber Output

C:\Users\Callum\Documents\GitHub\ESDK\hardware\FLD\DSPCB\Outputs\ESDK-FLD - Drill Ident Drawing - [Through Hole] 09-01-2023.gbr

Layers:
[Through Hole]

### Drill Ident Drawing

Drill | Plated | Size | Shape | ID
126 | | 100 | Round | B
43 | Y | 100 | Round | C
20 | Y | 100 | Round | F
32 | Y | 100 | Round | G
41 | Y | 100 | Round | H
166 | Y | 100 | Round | M

D-Code | Shape (thou)
D17 | Round 100.00
D18 | Round 5.00

### Gerber Output

C:\Users\Callum\Documents\GitHub\ESDK\hardware\FLD\DSPCB\Outputs\ESDK-FLD - Outline 09-01-2023.gbr

Layers:
Board Outlines

D-Code | Shape (thou)
D18 | Round 5.00

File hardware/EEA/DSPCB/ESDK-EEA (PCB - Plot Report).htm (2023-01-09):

## Plot Report

Report Written: | Monday, January 09, 2023
Project Path: | C:\Users\Callum\Documents\GitHub\ESDK\hardware\EEA\DSPCB\ESDK-EEA.prj
Design Path: | C:\Users\Callum\Documents\GitHub\ESDK\hardware\EEA\DSPCB\ESDK-EEA.pcb
Design Title:
Created: | 05/08/2021 09:51:21
Last Saved: | 09/01/2023 14:58:04
Editing Time: | 7206 min
Units: | mm (precision 3)

## Device Settings

### Gerber Settings

Leading zero suppression.
G01 assumed throughout.
Line termination <*> .
3.5 format absolute inches.
Format commands defined in Gerber file.
Aperture table defined in Gerber file.
Hardware arcs allowed.

### Drill Settings

Excellon Format 2
Format 3.5 absolute in mm.
Zero suppression Leading

## Plots Output

Plot Job: "C:\Users\Callum\Documents\GitHub\ESDK\hardware\EEA\DSPCB\ESDK-EEA.mop"

### Gerber Output

C:\Users\Callum\Documents\GitHub\ESDK\hardware\EEA\DSPCB\Outputs\ESDK-EEA - Top Silkscreen 09-01-2023.gbr

Layers:
Top Silkscreen

D-Code | Shape (thou)
D18 | Round 7.87
D19 | Round 10.00
D29 | Round 5.00
D72 | Round 3.94
D73 | Round 1.00
D74 | Round 0.00

### Gerber Output

C:\Users\Callum\Documents\GitHub\ESDK\hardware\EEA\DSPCB\Outputs\ESDK-EEA - Top Copper 09-01-2023.gbr

Layers:
Top Copper

D-Code | Shape (thou)
D18 | Round 7.87
D19 | Round 10.00
D70 | Round 35.43
D71 | Round 19.69
D20 | Round 61.02
D21 | Square 64.96
D22 | Round 64.96
D75 | Round 9.84
D76 | Round 39.37
D77 | Rectangle 39.37 X 42.91 Rotation 90
D80 | Rectangle 39.37 X 42.91
D108 | Round 23.62
D109 | Rectangle 17.72 X 56.10 Rotation 90
D110 | Round 55.12
D111 | Rectangle 15.75 X 35.43 Rotation 90
D112 | Rectangle 23.62 X 61.02
D113 | Rectangle 47.24 X 70.87
D114 | Square 60.00
D115 | Rectangle 15.75 X 35.43
D116 | Rectangle 17.72 X 43.31 Rotation 90

### Gerber Output

C:\Users\Callum\Documents\GitHub\ESDK\hardware\EEA\DSPCB\Outputs\ESDK-EEA - Top Copper (Resist) 09-01-2023.gbr

Layers:
Top Copper

D-Code | Shape (thou)
D86 | Round 135.98
D87 | Round 71.02
D88 | Rectangle 49.37 X 52.91 Rotation 90
D91 | Rectangle 49.37 X 52.91
D117 | Round 45.43
D118 | Rectangle 27.72 X 66.10 Rotation 90
D119 | Round 65.12
D120 | Rectangle 25.75 X 45.43 Rotation 90
D121 | Rectangle 33.62 X 71.02
D122 | Rectangle 57.24 X 80.87
D123 | Square 70.00
D124 | Rectangle 25.75 X 45.43
D125 | Rectangle 27.72 X 53.31 Rotation 90
D150 | Square 74.96
D151 | Round 74.96

### Gerber Output

C:\Users\Callum\Documents\GitHub\ESDK\hardware\EEA\DSPCB\Outputs\ESDK-EEA - Top Paste 09-01-2023.gbr

Layers:
Top Paste

D-Code | Shape (thou)
D10 | Rectangle 35.43 X 38.98 Rotation 90
D15 | Rectangle 35.43 X 38.98
D126 | Rectangle 15.94 X 54.33 Rotation 90
D127 | Rectangle 14.17 X 33.86 Rotation 90
D128 | Rectangle 21.26 X 58.66
D129 | Rectangle 42.52 X 66.14
D130 | Rectangle 14.17 X 33.86
D131 | Rectangle 15.94 X 41.54 Rotation 90

### Gerber Output

C:\Users\Callum\Documents\GitHub\ESDK\hardware\EEA\DSPCB\Outputs\ESDK-EEA - Bottom Copper 09-01-2023.gbr

Layers:
Bottom Copper

D-Code | Shape (thou)
D18 | Round 7.87
D19 | Round 10.00
D70 | Round 35.43
D20 | Round 61.02
D21 | Square 64.96
D22 | Round 64.96
D75 | Round 9.84
D76 | Round 39.37
D110 | Round 55.12
D114 | Square 60.00

### Gerber Output

C:\Users\Callum\Documents\GitHub\ESDK\hardware\EEA\DSPCB\Outputs\ESDK-EEA - Bottom Resist 09-01-2023.gbr

Layers:
Bottom Resist

D-Code | Shape (thou)
D23 | Round 41.43
D24 | Round 131.98
D25 | Round 67.02
D26 | Square 70.96
D27 | Round 70.96
D132 | Round 61.12
D133 | Square 66.00

### NC Drill Output

C:\Users\Callum\Documents\GitHub\ESDK\hardware\EEA\DSPCB\Outputs\ESDK-EEA - NC Drill Data - [Through Hole] 09-01-2023.drl

Output:

Plated Round Drill Holes

Plated Slots

Tool | Size | Count | ID
T001 | 0.01969 inches | 17 | F
T002 | 0.03150 inches | 8 | V
T003 | 0.03500 inches | 3 | R
T004 | 0.04094 inches | 6 | H
T005 | 0.04331 inches | 12 | C
Total | | 46

C:\Users\Callum\Documents\GitHub\ESDK\hardware\EEA\DSPCB\Outputs\ESDK-EEA - NC Drill Data - [Through Hole] 09-01-2023 (Unplated).drl

Output:

Unplated Round Drill Holes

Unplated Slots

Tool | Size | Count | ID
T001 | 0.12598 inches | 4 | B
Total | | 4

### Gerber Output

C:\Users\Callum\Documents\GitHub\ESDK\hardware\EEA\DSPCB\Outputs\ESDK-EEA - Drill Ident Drawing - [Through Hole] 09-01-2023.gbr

Layers:
[Through Hole]

### Drill Ident Drawing

Drill | Plated | Size | Shape | ID
126 | | 100 | Round | B
43 | Y | 100 | Round | C
20 | Y | 100 | Round | F
41 | Y | 100 | Round | H
35 | Y | 100 | Round | R
31 | Y | 100 | Round | V

D-Code | Shape (thou)
D28 | Round 100.00
D29 | Round 5.00

### Gerber Output

C:\Users\Callum\Documents\GitHub\ESDK\hardware\EEA\DSPCB\Outputs\ESDK-EEA - Outline 09-01-2023.gbr

Layers:
Board Outlines

D-Code | Shape (thou)
D29 | Round 5.00

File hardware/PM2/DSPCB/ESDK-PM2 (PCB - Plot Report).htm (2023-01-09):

## Plot Report

Report Written: | Monday, January 09, 2023
Project Path: | C:\Users\Callum\Documents\GitHub\ESDK\hardware\PM2\DSPCB\ESDK-PM2.prj
Design Path: | C:\Users\Callum\Documents\GitHub\ESDK\hardware\PM2\DSPCB\ESDK-PM2.pcb
Design Title:
Created: | 05/08/2021 11:32:18
Last Saved: | 09/01/2023 14:55:36
Editing Time: | 5905 min
Units: | mm (precision 3)

## Device Settings

### Gerber Settings

Leading zero suppression.
G01 assumed throughout.
Line termination <*> .
3.5 format absolute inches.
Format commands defined in Gerber file.
Aperture table defined in Gerber file.
Hardware arcs allowed.

### Drill Settings

Excellon Format 2
Format 3.5 absolute in mm.
Zero suppression Leading

## Plots Output

Plot Job: "C:\Users\Callum\Documents\GitHub\ESDK\hardware\PM2\DSPCB\ESDK-PM2.mop"

### Gerber Output

C:\Users\Callum\Documents\GitHub\ESDK\hardware\PM2\DSPCB\Outputs\ESDK-PM2 - Top Silkscreen 09-01-2023.gbr

Layers:
Top Silkscreen

D-Code | Shape (thou)
D18 | Round 7.87
D29 | Round 5.00
D72 | Round 3.94
D73 | Round 1.00
D74 | Round 0.00

### Gerber Output

C:\Users\Callum\Documents\GitHub\ESDK\hardware\PM2\DSPCB\Outputs\ESDK-PM2 - Top Copper 09-01-2023.gbr

Layers:
Top Copper

D-Code | Shape (thou)
D18 | Round 7.87
D19 | Round 10.00
D70 | Round 35.43
D71 | Round 19.69
D20 | Round 61.02
D21 | Square 64.96
D22 | Round 64.96
D29 | Round 5.00
D75 | Round 9.84
D76 | Round 39.37
D80 | Rectangle 39.37 X 42.91
D84 | Square 59.06
D85 | Square 35.43
D102 | Square 43.31
D103 | Round 43.31

### Gerber Output

C:\Users\Callum\Documents\GitHub\ESDK\hardware\PM2\DSPCB\Outputs\ESDK-PM2 - Top Copper (Resist) 09-01-2023.gbr

Layers:
Top Copper

D-Code | Shape (thou)
D86 | Round 135.98
D87 | Round 71.02
D91 | Rectangle 49.37 X 52.91
D95 | Square 69.06
D104 | Square 53.31
D105 | Round 53.31
D150 | Square 74.96
D151 | Round 74.96
D153 | Square 45.43

### Gerber Output

C:\Users\Callum\Documents\GitHub\ESDK\hardware\PM2\DSPCB\Outputs\ESDK-PM2 - Bottom Copper 09-01-2023.gbr

Layers:
Bottom Copper

D-Code | Shape (thou)
D18 | Round 7.87
D19 | Round 10.00
D70 | Round 35.43
D20 | Round 61.02
D21 | Square 64.96
D22 | Round 64.96
D102 | Square 43.31
D103 | Round 43.31

### Gerber Output

C:\Users\Callum\Documents\GitHub\ESDK\hardware\PM2\DSPCB\Outputs\ESDK-PM2 - Bottom Resist 09-01-2023.gbr

Layers:
Bottom Resist

D-Code | Shape (thou)
D23 | Round 41.43
D24 | Round 131.98
D25 | Round 67.02
D26 | Square 70.96
D27 | Round 70.96
D106 | Square 49.31
D107 | Round 49.31

### NC Drill Output

C:\Users\Callum\Documents\GitHub\ESDK\hardware\PM2\DSPCB\Outputs\ESDK-PM2 - NC Drill Data - [Through Hole] 09-01-2023.drl

Output:

Plated Round Drill Holes

Plated Slots

Tool | Size | Count | ID
T001 | 0.01969 inches | 29 | F
T002 | 0.02756 inches | 5 | W
T003 | 0.04094 inches | 12 | H
T004 | 0.04331 inches | 12 | C
Total | | 58

C:\Users\Callum\Documents\GitHub\ESDK\hardware\PM2\DSPCB\Outputs\ESDK-PM2 - NC Drill Data - [Through Hole] 09-01-2023 (Unplated).drl

Output:

Unplated Round Drill Holes

Unplated Slots

Tool | Size | Count | ID
T001 | 0.12598 inches | 4 | B
Total | | 4

### Gerber Output

C:\Users\Callum\Documents\GitHub\ESDK\hardware\PM2\DSPCB\Outputs\ESDK-PM2 - Drill Ident Drawing - [Through Hole] 09-01-2023.gbr

Layers:
[Through Hole]

### Drill Ident Drawing

Drill | Plated | Size | Shape | ID
126 | | 100 | Round | B
43 | Y | 100 | Round | C
20 | Y | 100 | Round | F
41 | Y | 100 | Round | H
28 | Y | 100 | Round | W

D-Code | Shape (thou)
D28 | Round 100.00
D29 | Round 5.00

### Gerber Output

C:\Users\Callum\Documents\GitHub\ESDK\hardware\PM2\DSPCB\Outputs\ESDK-PM2 - Outline 09-01-2023.gbr

Layers:
Board Outlines

D-Code | Shape (thou)
D29 | Round 5.00

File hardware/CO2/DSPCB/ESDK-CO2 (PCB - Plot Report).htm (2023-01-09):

## Plot Report

Report Written: | Monday, January 09, 2023
Project Path: | C:\Users\Callum\Documents\GitHub\ESDK\hardware\CO2\DSPCB\ESDK-CO2.prj
Design Path: | C:\Users\Callum\Documents\GitHub\ESDK\hardware\CO2\DSPCB\ESDK-CO2.pcb
Design Title:
Created: | 05/08/2021 09:51:21
Last Saved: | 09/01/2023 14:43:16
Editing Time: | 6837 min
Units: | mm (precision 3)

## Device Settings

### Gerber Settings

Leading zero suppression.
G01 assumed throughout.
Line termination <*> .
3.5 format absolute inches.
Format commands defined in Gerber file.
Aperture table defined in Gerber file.
Hardware arcs allowed.

### Drill Settings

Excellon Format 2
Format 3.5 absolute in mm.
Zero suppression Leading

## Plots Output

Plot Job: "C:\Users\Callum\Documents\GitHub\ESDK\hardware\CO2\DSPCB\ESDK-CO2.mop"

### Gerber Output

C:\Users\Callum\Documents\GitHub\ESDK\hardware\CO2\DSPCB\Outputs\ESDK-CO2 - Top Silkscreen 09-01-2023.gbr

Layers:
Top Silkscreen

D-Code | Shape (thou)
D18 | Round 7.87
D29 | Round 5.00
D72 | Round 3.94
D73 | Round 1.00
D74 | Round 0.00

### Gerber Output

C:\Users\Callum\Documents\GitHub\ESDK\hardware\CO2\DSPCB\Outputs\ESDK-CO2 - Top Copper 09-01-2023.gbr

Layers:
Top Copper

D-Code | Shape (thou)
D18 | Round 7.87
D19 | Round 10.00
D70 | Round 35.43
D20 | Round 61.02
D21 | Square 64.96
D22 | Round 64.96
D29 | Round 5.00
D75 | Round 9.84
D76 | Round 39.37
D77 | Rectangle 39.37 X 42.91 Rotation 90
D78 | Rectangle 47.24 X 62.99
D79 | Rectangle 129.92 X 129.92
D80 | Rectangle 39.37 X 42.91
D81 | Rectangle 31.50 X 59.06
D82 | Rectangle 31.50 X 59.06 Rotation 90
D83 | Square 70.87
D84 | Square 59.06
D85 | Square 35.43

### Gerber Output

C:\Users\Callum\Documents\GitHub\ESDK\hardware\CO2\DSPCB\Outputs\ESDK-CO2 - Top Copper (Resist) 09-01-2023.gbr

Layers:
Top Copper

D-Code | Shape (thou)
D86 | Round 135.98
D87 | Round 71.02
D88 | Rectangle 49.37 X 52.91 Rotation 90
D89 | Rectangle 57.24 X 72.99
D90 | Rectangle 139.92 X 139.92
D91 | Rectangle 49.37 X 52.91
D92 | Rectangle 41.50 X 69.06
D93 | Rectangle 41.50 X 69.06 Rotation 90
D94 | Square 80.87
D95 | Square 69.06
D150 | Square 74.96
D151 | Round 74.96
D153 | Square 45.43

### Gerber Output

C:\Users\Callum\Documents\GitHub\ESDK\hardware\CO2\DSPCB\Outputs\ESDK-CO2 - Top Paste 09-01-2023.gbr

Layers:
Top Paste

D-Code | Shape (thou)
D10 | Rectangle 35.43 X 38.98 Rotation 90
D12 | Square 31.89
D15 | Rectangle 35.43 X 38.98
D96 | Rectangle 42.52 X 58.27
D97 | Rectangle 116.93 X 116.93
D98 | Rectangle 28.35 X 55.91
D99 | Rectangle 28.35 X 55.91 Rotation 90
D100 | Square 63.78
D101 | Square 53.15

### Gerber Output

C:\Users\Callum\Documents\GitHub\ESDK\hardware\CO2\DSPCB\Outputs\ESDK-CO2 - Bottom Copper 09-01-2023.gbr

Layers:
Bottom Copper

D-Code | Shape (thou)
D18 | Round 7.87
D19 | Round 10.00
D70 | Round 35.43
D20 | Round 61.02
D21 | Square 64.96
D22 | Round 64.96

### Gerber Output

C:\Users\Callum\Documents\GitHub\ESDK\hardware\CO2\DSPCB\Outputs\ESDK-CO2 - Bottom Resist 09-01-2023.gbr

Layers:
Bottom Resist

D-Code | Shape (thou)
D23 | Round 41.43
D24 | Round 131.98
D25 | Round 67.02
D26 | Square 70.96
D27 | Round 70.96

### NC Drill Output

C:\Users\Callum\Documents\GitHub\ESDK\hardware\CO2\DSPCB\Outputs\ESDK-CO2 - NC Drill Data - [Through Hole] 09-01-2023.drl

Output:

Plated Round Drill Holes

Plated Slots

Tool | Size | Count | ID
T001 | 0.01969 inches | 24 | F
T002 | 0.04094 inches | 12 | H
T003 | 0.04331 inches | 12 | C
Total | | 48

C:\Users\Callum\Documents\GitHub\ESDK\hardware\CO2\DSPCB\Outputs\ESDK-CO2 - NC Drill Data - [Through Hole] 09-01-2023 (Unplated).drl

Output:

Unplated Round Drill Holes

Unplated Slots

Tool | Size | Count | ID
T001 | 0.12598 inches | 4 | B
Total | | 4

### Gerber Output

C:\Users\Callum\Documents\GitHub\ESDK\hardware\CO2\DSPCB\Outputs\ESDK-CO2 - Drill Ident Drawing - [Through Hole] 09-01-2023.gbr

Layers:
[Through Hole]

### Drill Ident Drawing

Drill | Plated | Size | Shape | ID
126 | | 100 | Round | B
43 | Y | 100 | Round | C
20 | Y | 100 | Round | F
41 | Y | 100 | Round | H

D-Code | Shape (thou)
D28 | Round 100.00
D29 | Round 5.00

### Gerber Output

C:\Users\Callum\Documents\GitHub\ESDK\hardware\CO2\DSPCB\Outputs\ESDK-CO2 - Outline 09-01-2023.gbr

Layers:
Board Outlines

D-Code | Shape (thou)
D29 | Round 5.00

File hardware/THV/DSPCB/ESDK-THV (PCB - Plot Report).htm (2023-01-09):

## Plot Report

Report Written: | Monday, January 09, 2023
Project Path: | C:\Users\Callum\Documents\GitHub\ESDK\hardware\THV\DSPCB\ESDK-THV.prj
Design Path: | C:\Users\Callum\Documents\GitHub\ESDK\hardware\THV\DSPCB\ESDK-THV.pcb
Design Title:
Created: | 05/08/2021 09:51:21
Last Saved: | 09/01/2023 14:35:58
Editing Time: | 6554 min
Units: | mm (precision 3)

## Device Settings

### Gerber Settings

Leading zero suppression.
G01 assumed throughout.
Line termination <*> .
3.5 format absolute inches.
Format commands defined in Gerber file.
Aperture table defined in Gerber file.
Hardware arcs allowed.

### Drill Settings

Excellon Format 2
Format 3.5 absolute in inches.
Zero suppression Leading

## Plots Output

Plot Job: "C:\Users\Callum\Documents\GitHub\ESDK\hardware\THV\DSPCB\ESDK-THV.mop"

### Gerber Output

C:\Users\Callum\Documents\GitHub\ESDK\hardware\THV\DSPCB\Outputs\ESDK-THV - Mechanical 09-01-2023.gbr

Layers:
Mechanical

D-Code | Shape (thou)
D119 | Round 5.00
D121 | Round 7.87
D139 | Round 1.97

### Gerber Output

C:\Users\Callum\Documents\GitHub\ESDK\hardware\THV\DSPCB\Outputs\ESDK-THV - Top Silkscreen 09-01-2023.gbr

Layers:
Top Silkscreen

D-Code | Shape (thou)
D119 | Round 5.00
D120 | Round 3.94
D121 | Round 7.87
D124 | Round 9.84
D140 | Round 1.00
D141 | Round 0.00

### Gerber Output

C:\Users\Callum\Documents\GitHub\ESDK\hardware\THV\DSPCB\Outputs\ESDK-THV - Top Copper 09-01-2023.gbr

Layers:
Top Copper

D-Code | Shape (thou)
D119 | Round 5.00
D121 | Round 7.87
D122 | Round 10.00
D124 | Round 9.84
D125 | Round 35.43
D126 | Round 19.69
D128 | Round 61.02
D132 | Rectangle 39.37 X 42.91
D133 | Rectangle 39.37 X 42.91 Rotation 90
D142 | Round 39.37
D143 | Square 64.96
D144 | Round 64.96
D145 | Rectangle 43.31 X 59.06 Rotation 90
D146 | Square 35.43
D147 | Rectangle 11.81 X 31.50
D148 | Rectangle 47.24 X 74.80 Rotation 90
D149 | Rectangle 17.72 X 29.53 Rotation 90
D150 | Rectangle 53.15 X 68.50

### Gerber Output

C:\Users\Callum\Documents\GitHub\ESDK\hardware\THV\DSPCB\Outputs\ESDK-THV - Top Copper (Resist) 09-01-2023.gbr

Layers:
Top Copper

D-Code | Shape (thou)
D13 | Round 135.98
D14 | Round 71.02
D18 | Rectangle 49.37 X 52.91 Rotation 90
D19 | Rectangle 49.37 X 52.91
D150 | Square 74.96
D151 | Round 74.96
D152 | Rectangle 53.31 X 69.06 Rotation 90
D153 | Square 45.43
D154 | Rectangle 21.81 X 41.50
D155 | Rectangle 57.24 X 84.80 Rotation 90
D156 | Rectangle 27.72 X 39.53 Rotation 90
D157 | Rectangle 63.15 X 78.50

### Gerber Output

C:\Users\Callum\Documents\GitHub\ESDK\hardware\THV\DSPCB\Outputs\ESDK-THV - Top Paste 09-01-2023.gbr

Layers:
Top Paste

D-Code | Shape (thou)
D10 | Rectangle 35.43 X 38.98 Rotation 90
D11 | Rectangle 38.98 X 54.72 Rotation 90
D12 | Square 31.89
D13 | Rectangle 10.63 X 30.31
D14 | Rectangle 42.52 X 70.08 Rotation 90
D15 | Rectangle 35.43 X 38.98
D16 | Rectangle 15.94 X 27.76 Rotation 90
D17 | Rectangle 47.83 X 63.19

### Gerber Output

C:\Users\Callum\Documents\GitHub\ESDK\hardware\THV\DSPCB\Outputs\ESDK-THV - Bottom Copper 09-01-2023.gbr

Layers:
Bottom Copper

D-Code | Shape (thou)
D18 | Round 7.87
D19 | Round 10.00
D70 | Round 35.43
D71 | Round 19.69
D20 | Round 61.02
D21 | Square 64.96
D22 | Round 64.96

### Gerber Output

C:\Users\Callum\Documents\GitHub\ESDK\hardware\THV\DSPCB\Outputs\ESDK-THV - Bottom Resist 09-01-2023.gbr

Layers:
Bottom Resist

D-Code | Shape (thou)
D23 | Round 41.43
D24 | Round 131.98
D25 | Round 67.02
D26 | Square 70.96
D27 | Round 70.96

### NC Drill Output

C:\Users\Callum\Documents\GitHub\ESDK\hardware\THV\DSPCB\Outputs\ESDK-THV - NC Drill Data - [Through Hole] 09-01-2023.drl

Output:

Plated Round Drill Holes

Plated Slots

Tool | Size | Count | ID
T001 | 0.01969 inches | 31 | F
T002 | 0.04094 inches | 12 | H
T003 | 0.04331 inches | 12 | C
Total | | 55

C:\Users\Callum\Documents\GitHub\ESDK\hardware\THV\DSPCB\Outputs\ESDK-THV - NC Drill Data - [Through Hole] 09-01-2023 (Unplated).drl

Output:

Unplated Round Drill Holes

Unplated Slots

Tool | Size | Count | ID
T001 | 0.12598 inches | 4 | B
Total | | 4

### Gerber Output

C:\Users\Callum\Documents\GitHub\ESDK\hardware\THV\DSPCB\Outputs\ESDK-THV - Drill Ident Drawing - [Through Hole] 09-01-2023.gbr

Layers:
[Through Hole]

### Drill Ident Drawing

Drill | Plated | Size | Shape | ID
126 | | 100 | Round | B
43 | Y | 100 | Round | C
20 | Y | 100 | Round | F
41 | Y | 100 | Round | H

D-Code | Shape (thou)
D28 | Round 100.00
D29 | Round 5.00

### Gerber Output

C:\Users\Callum\Documents\GitHub\ESDK\hardware\THV\DSPCB\Outputs\ESDK-THV - Outline 09-01-2023.gbr

Layers:
Board Outlines

D-Code | Shape (thou)
D29 | Round 5.00

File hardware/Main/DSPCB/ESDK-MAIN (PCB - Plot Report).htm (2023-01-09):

## Plot Report

Report Written: | Monday, January 09, 2023
Project Path: | C:\Users\Callum\Documents\GitHub\ESDK\hardware\Main\DSPCB\ESDK-MAIN.prj
Design Path: | C:\Users\Callum\Documents\GitHub\ESDK\hardware\Main\DSPCB\ESDK-MAIN.pcb
Design Title:
Created: | 26/08/2021 12:01:11
Last Saved: | 09/01/2023 14:23:31
Editing Time: | 14322 min
Units: | mm (precision 3)

## Device Settings

### Gerber Settings

Leading zero suppression.
G01 assumed throughout.
Line termination <*> .
3.5 format absolute inches.
Format commands defined in Gerber file.
Aperture table defined in Gerber file.
Hardware arcs allowed.

### Drill Settings

Excellon Format 2
Format 3.5 absolute in mm.
Zero suppression Leading

## Plots Output

Plot Job: "C:\Users\Callum\Documents\GitHub\ESDK\hardware\Main\DSPCB\ESDK-MAIN.mop"

### Gerber Output

C:\Users\Callum\Documents\GitHub\ESDK\hardware\Main\DSPCB\Outputs\ESDK-MAIN - Top Silkscreen 09-01-2023.gbr

Layers:
Top Silkscreen

D-Code | Shape (thou)
D10 | Round 5.00
D80 | Round 7.87
D105 | Round 3.94
D106 | Round 1.00
D107 | Round 0.00

### Gerber Output

C:\Users\Callum\Documents\GitHub\ESDK\hardware\Main\DSPCB\Outputs\ESDK-MAIN - Top Copper 09-01-2023.gbr

Layers:
Top Copper

D-Code | Shape (thou)
D13 | Round 56.00
D14 | Round 15.00
D80 | Round 7.87
D108 | Round 9.84
D109 | Round 35.43
D110 | Round 21.65
D111 | Round 61.02
D112 | Rectangle 55.12 X 82.68 Rotation 90
D113 | Rectangle 15.75 X 35.43 Rotation 90

### Gerber Output

C:\Users\Callum\Documents\GitHub\ESDK\hardware\Main\DSPCB\Outputs\ESDK-MAIN - Top Paste 09-01-2023.gbr

Layers:
Top Paste

D-Code | Shape (thou)
D114 | Rectangle 49.61 X 77.17 Rotation 90
D115 | Rectangle 14.17 X 33.86 Rotation 90

### Gerber Output

C:\Users\Callum\Documents\GitHub\ESDK\hardware\Main\DSPCB\Outputs\ESDK-MAIN - Top Resist 09-01-2023.gbr

Layers:
Top Resist

D-Code | Shape (thou)
D116 | Round 45.43
D117 | Round 66.00
D118 | Round 49.37
D119 | Round 135.98
D120 | Round 71.02
D121 | Rectangle 65.12 X 92.68 Rotation 90
D122 | Rectangle 25.75 X 45.43 Rotation 90
D123 | Round 22.80

### Gerber Output

C:\Users\Callum\Documents\GitHub\ESDK\hardware\Main\DSPCB\Outputs\ESDK-MAIN - Inner1 09-01-2023.gbr

Layers:
Inner1

D-Code | Shape (thou)
D10 | Round 5.00
D13 | Round 56.00
D83 | Round 39.37
D108 | Round 9.84
D109 | Round 35.43
D111 | Round 61.02
D124 | Round 59.06
D125 | Round 98.43
D126 | Round 51.18

### Gerber Output

C:\Users\Callum\Documents\GitHub\ESDK\hardware\Main\DSPCB\Outputs\ESDK-MAIN - Inner2 09-01-2023.gbr

Layers:
Inner2

D-Code | Shape (thou)
D10 | Round 5.00
D13 | Round 56.00
D108 | Round 9.84
D109 | Round 35.43
D111 | Round 61.02

### Gerber Output

C:\Users\Callum\Documents\GitHub\ESDK\hardware\Main\DSPCB\Outputs\ESDK-MAIN - Bottom Copper 09-01-2023.gbr

Layers:
Bottom Copper

D-Code | Shape (thou)
D10 | Round 5.00
D13 | Round 56.00
D14 | Round 15.00
D80 | Round 7.87
D82 | Round 31.50
D84 | Rectangle 25.59 X 47.24 Rotation 90
D85 | Rectangle 39.37 X 42.91
D86 | Rectangle 39.37 X 42.91 Rotation 90
D87 | Rectangle 25.59 X 47.24
D97 | Rectangle 55.00 X 60.00
D108 | Round 9.84
D109 | Round 35.43
D110 | Round 21.65
D111 | Round 61.02
D124 | Round 59.06
D126 | Round 51.18
D127 | Round 23.62
D128 | Round 11.81
D129 | Round 15.75
D130 | Rectangle 31.50 X 70.87
D131 | Round 47.24
D132 | Rectangle 41.34 X 86.61 Rotation 90
D133 | Rectangle 39.37 X 41.34 Rotation 90
D134 | Rectangle 23.62 X 51.18 Rotation 90
D135 | Rectangle 70.87 X 86.61 Rotation 90
D136 | Rectangle 11.81 X 51.18 Rotation 90
D137 | Rectangle 63.00 X 102.00
D138 | Rectangle 25.59 X 60.04
D139 | Rectangle 43.31 X 74.80
D140 | Rectangle 31.50 X 51.18 Rotation 90
D141 | Rectangle 82.68 X 118.11 Rotation 90
D142 | Rectangle 25.59 X 60.04 Rotation 90
D143 | Rectangle 11.81 X 45.28 Rotation 90
D144 | Rectangle 78.74 X 85.83
D145 | Rectangle 47.24 X 62.99 Rotation 90
D146 | Rectangle 129.92 X 129.92 Rotation 90
D147 | Rectangle 34.65 X 110.63 Rotation 90
D148 | Square 31.50
D149 | Rectangle 19.69 X 42.32
D169 | Rectangle 137.80 X 141.73 Rotation 90
D170 | Square 157.48
D171 | Rectangle 70.87 X 173.23
D172 | Rectangle 23.62 X 45.28
D173 | Rectangle 23.62 X 39.37 Rotation 90
D174 | Rectangle 49.21 X 70.87 Rotation 90

### Gerber Output

C:\Users\Callum\Documents\GitHub\ESDK\hardware\Main\DSPCB\Outputs\ESDK-MAIN - Bottom Silkscreen 09-01-2023.gbr

Layers:
Bottom Silkscreen

D-Code | Shape (thou)
D10 | Round 5.00
D11 | Round 10.00
D80 | Round 7.87
D105 | Round 3.94

### Gerber Output

C:\Users\Callum\Documents\GitHub\ESDK\hardware\Main\DSPCB\Outputs\ESDK-MAIN - Bottom Resist 09-01-2023.gbr

Layers:
Bottom Resist

D-Code | Shape (thou)
D10 | Round 45.43
D11 | Round 66.00
D12 | Round 49.37
D13 | Round 135.98
D14 | Round 71.02
D15 | Rectangle 41.50 X 80.87
D16 | Round 57.24
D17 | Rectangle 35.59 X 57.24
D18 | Rectangle 49.37 X 52.91 Rotation 90
D19 | Rectangle 49.37 X 52.91
D70 | Rectangle 51.34 X 96.61 Rotation 90
D71 | Rectangle 49.37 X 51.34 Rotation 90
D20 | Rectangle 33.62 X 61.18 Rotation 90
D21 | Rectangle 80.87 X 96.61 Rotation 90
D22 | Rectangle 21.81 X 61.18 Rotation 90
D23 | Rectangle 73.00 X 112.00
D24 | Rectangle 35.59 X 57.24 Rotation 90
D25 | Rectangle 35.59 X 70.04
D26 | Rectangle 53.31 X 84.80
D27 | Rectangle 41.50 X 61.18 Rotation 90
D28 | Rectangle 92.68 X 128.11 Rotation 90
D29 | Rectangle 35.59 X 70.04 Rotation 90
D72 | Rectangle 21.81 X 55.28 Rotation 90
D73 | Round 22.80
D74 | Rectangle 88.74 X 95.83
D75 | Rectangle 57.24 X 72.99 Rotation 90
D76 | Rectangle 139.92 X 139.92 Rotation 90
D77 | Rectangle 44.65 X 120.63 Rotation 90
D78 | Square 41.50
D79 | Rectangle 29.69 X 52.32
D80 | Rectangle 147.80 X 151.73 Rotation 90
D81 | Square 167.48
D82 | Rectangle 80.87 X 183.23
D83 | Rectangle 33.62 X 55.28
D84 | Rectangle 33.62 X 49.37 Rotation 90
D85 | Rectangle 59.21 X 80.87 Rotation 90
D86 | Rectangle 65.00 X 70.00

### Gerber Output

C:\Users\Callum\Documents\GitHub\ESDK\hardware\Main\DSPCB\Outputs\ESDK-MAIN - Bottom Paste 09-01-2023.gbr

Layers:
Bottom Paste

D-Code | Shape (thou)
D87 | Rectangle 28.35 X 67.72
D88 | Round 42.52
D89 | Rectangle 23.03 X 44.69
D90 | Rectangle 35.43 X 38.98 Rotation 90
D91 | Rectangle 35.43 X 38.98
D92 | Rectangle 37.20 X 82.48 Rotation 90
D93 | Rectangle 35.43 X 37.40 Rotation 90
D94 | Rectangle 21.26 X 48.82 Rotation 90
D95 | Rectangle 63.78 X 79.53 Rotation 90
D96 | Rectangle 10.63 X 50.00 Rotation 90
D97 | Rectangle 56.70 X 95.70
D98 | Rectangle 23.03 X 44.69 Rotation 90
D99 | Rectangle 23.03 X 57.48
D100 | Rectangle 38.98 X 70.47
D101 | Rectangle 28.35 X 48.03 Rotation 90
D102 | Rectangle 74.41 X 109.84 Rotation 90
D103 | Rectangle 23.03 X 57.48 Rotation 90
D104 | Rectangle 10.63 X 44.09 Rotation 90
D105 | Rectangle 70.87 X 77.95
D106 | Rectangle 42.52 X 58.27 Rotation 90
D107 | Rectangle 116.93 X 116.93 Rotation 90
D108 | Rectangle 31.18 X 107.17 Rotation 90
D109 | Square 28.35
D110 | Rectangle 17.72 X 40.35
D111 | Rectangle 124.02 X 127.95 Rotation 90
D112 | Square 141.73
D113 | Rectangle 63.78 X 166.14
D114 | Rectangle 21.26 X 42.91
D115 | Rectangle 21.26 X 37.01 Rotation 90
D116 | Rectangle 44.29 X 65.94 Rotation 90
D117 | Rectangle 49.50 X 54.50

### NC Drill Output

C:\Users\Callum\Documents\GitHub\ESDK\hardware\Main\DSPCB\Outputs\ESDK-MAIN - NC Drill Data - [Through Hole] 09-01-2023.drl

Output:

Plated Round Drill Holes

Plated Slots

Tool | Size | Count | ID
T001 | 0.01969 inches | 156 | F
T002 | 0.03200 inches | 2 | G
T003 | 0.04016 inches | 40 | O
Total | | 198

C:\Users\Callum\Documents\GitHub\ESDK\hardware\Main\DSPCB\Outputs\ESDK-MAIN - NC Drill Data - [Through Hole] 09-01-2023 (Unplated).drl

Output:

Unplated Round Drill Holes

Unplated Slots

Tool | Size | Count | ID
T001 | 0.02559 inches | 2 | L
T002 | 0.03937 inches | 3 | N
T003 | 0.12598 inches | 2 | B
Total | | 7

### Gerber Output

C:\Users\Callum\Documents\GitHub\ESDK\hardware\Main\DSPCB\Outputs\ESDK-MAIN - Drill Ident Drawing - [Through Hole] 09-01-2023.gbr

Layers:
[Through Hole]

### Drill Ident Drawing

Drill | Plated | Size | Shape | ID
126 | | 100 | Round | B
20 | Y | 100 | Round | F
32 | Y | 100 | Round | G
26 | | 100 | Round | L
39 | | 100 | Round | N
40 | Y | 100 | Round | O

D-Code | Shape (thou)
D118 | Round 100.00
D119 | Round 5.00

### Gerber Output

C:\Users\Callum\Documents\GitHub\ESDK\hardware\Main\DSPCB\Outputs\ESDK-MAIN - Outline 09-01-2023.gbr

Layers:
Board Outlines

D-Code | Shape (thou)
D119 | Round 5.00

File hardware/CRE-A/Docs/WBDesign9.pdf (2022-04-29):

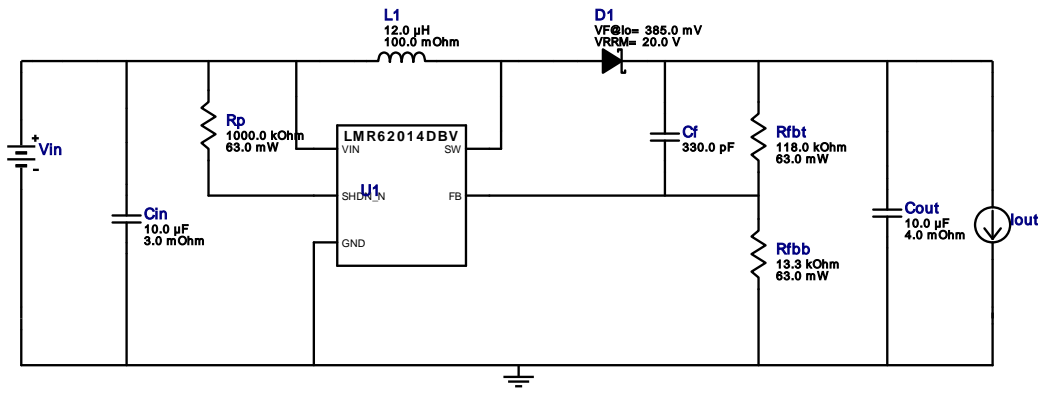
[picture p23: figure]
Rfbb 13.3 kOhm 63.0 m W; Cout 10.0 µF 4.0 m Ohm; L1 12.0 µH 100.0 m Ohm; Rp 1000.0 kOhm 63.0 m W; Rfbt 118.0 kOhm 63.0 m W; LM R6 2 0 1 4 DBV VIN; SHDN_N; GND; Cin 10.0 µF 3.0 m Ohm; D1 VF@Io= 385.0 m V VRRM= 20.0 V; Iout; Vin

Copyright © 2022, Texas Instruments Incorporated | 1 | ti.com/webench

WEBENCH®
Design Report LMR62014XMF/NOPB : LMR62014XMF/NOPB 5V-5V to 12.00V @ 0.3A April 4, 2022 03:39:43 GMT-05:00

## WEBENCH ® Design Report

Design : 9 LMR62014XMF/NOPB
LMR62014XMF/NOPB 5V-5V to 12.00V @ 0.3A

VinMin = 5.0V
VinMax = 5.0V
Vout = 12.0V
Iout = 0.3A

Device = LMR62014XMF/NOPB
Topology = Boost
Created = 2022-04-01 04:38:23.325 BOM Cost = $0.62
BOM Count = 9
Total Pd = 0.51W

## Electrical BOM

Name | Manufacturer | Part Number | Properties | Qty Price | Footprint
Cf | Samsung Electro- Mechanics | CL21C331JBANNNC (http://www.samsungsem.com/servlet/FileDownload?type%3Dspec%26file%3DCL21C331JBANNNC.pdf) Series= C0G/NP0 | Cap= 330.0 pF VDC= 50.0 V IRMS= 0.0 A
1 | $0.01
| | | | | 0805 7 mm²
Cin | Kemet | C0805C106K8PACTU (http://capacitoredge.kemet.com/capedge2/DataSheet/Datasheet%2DC0805C106K8PACTU.pdf?pn%3DC0805C106K8PACTU) Series= X5R | Cap= 10.0 uF ESR= 3.0 mOhm VDC= 10.0 V IRMS= 11.43 A
1 | $0.03
| | | | | 0805 7 mm²
Cout | MuRata | GRM21BR61E106MA73L Series= X5R

Cap= 10.0 uF
ESR= 4.0 mOhm
VDC= 25.0 V
IRMS= 2.8 A

1 $0.05
0805 7 mm²
D1 | ON Semiconductor | MBR0520LT1G (http://www.onsemi.com/pub%5Flink/Collateral/MBR0520LT1%2DD.PDF) | VF@Io= 385.0 mV VRRM= 20.0 V | 1 | $0.05
SOD-123 13 mm²
L1 | NIC Components | NPI54C120MTRF (http://www.niccomp.com/pn/NPI54C120MTRF) | L= 12.0 µH 100.0 mOhm | 1 | $0.12

IND_NPI54C 61 mm²
Rfbb | Vishay-Dale | CRCW040213K3FKED (http://www.vishay.com/docs/20035/dcrcwe3.pdf) Series= CRCW..e3 | Res= 13.3 kOhm Power= 63.0 mW Tolerance= 1.0% | 1 | $0.01
0402 3 mm²
Rfbt | Vishay-Dale | CRCW0402118KFKED (http://www.vishay.com/docs/20035/dcrcwe3.pdf) Series= CRCW..e3 | Res= 118.0 kOhm Power= 63.0 mW Tolerance= 1.0% | 1 | $0.01
0402 3 mm²
Rp | Vishay-Dale | CRCW04021M00FKED (http://www.vishay.com/docs/20035/dcrcwe3.pdf) Series= CRCW..e3 | Res= 1000.0 kOhm Power= 63.0 mW Tolerance= 1.0% | 1 | $0.01
0402 3 mm²
U1 | Texas Instruments | LMR62014XMF/NOPB (http://www.ti.com/product/LMR62014) | Switcher | 1 | $0.33

DBV0005A 15 mm²

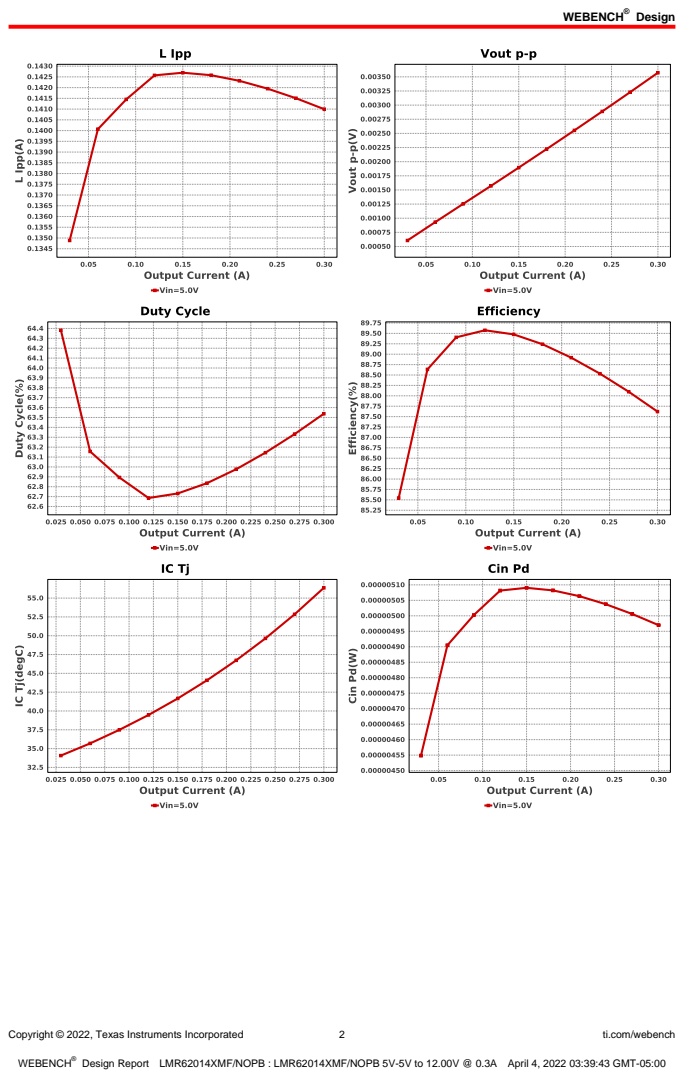
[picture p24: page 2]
Design; Copyright © 2022, Texas Instruments Incorporated; ti.com/webench

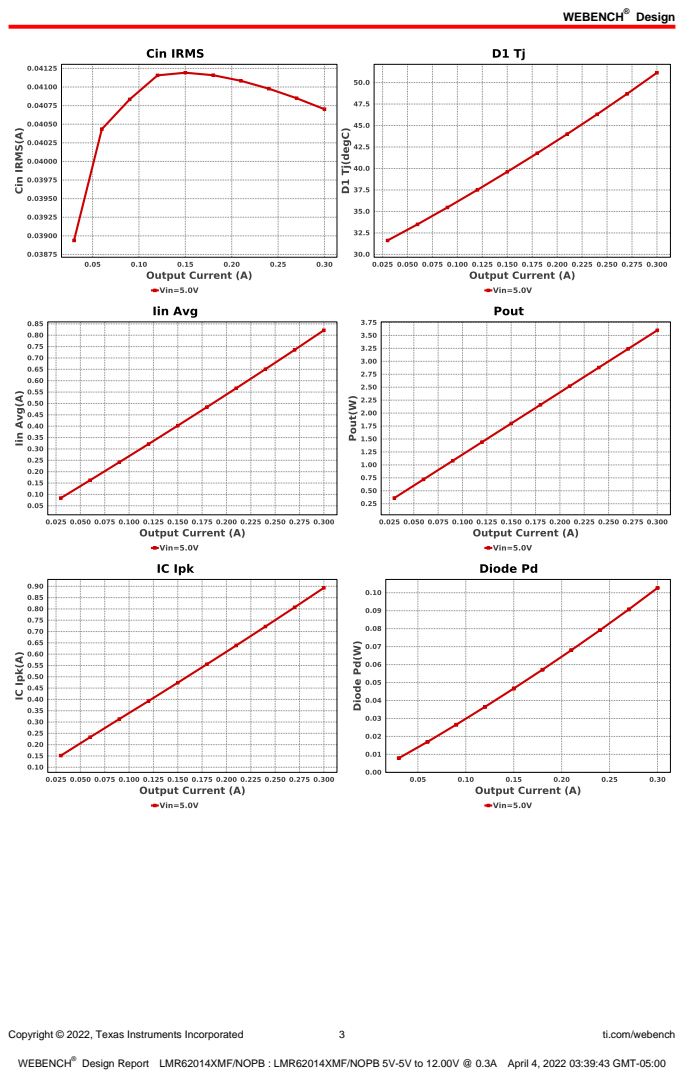
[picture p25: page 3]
Copyright © 2022, Texas Instruments Incorporated; ti.com/webench

Copyright © 2022, Texas Instruments Incorporated; ti.com/webench; Operating Values; Name; Value; Category; Description; 1. Cin IRMS; Capacitor; Input capacitor RMS ripple current; 2. Cin Pd; Input capacitor power dissipation; 3. Cout IRMS; Output capacitor RMS ripple current; 4. Cout Pd; Output capacitor power dissipation; 51.146 degC; Diode; D1 junction temperature; 6. Diode Pd; Diode power dissipation; 7. IC Ipk; Peak switch current in IC; IC power dissipation; 56.365 degC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

Copyright © 2022, Texas Instruments Incorporated | 5 | ti.com/webench
# | Name | Value | Category | Description

12. L Pd | 74.647 mW | Inductor | Inductor power dissipation
13. Cin Pd | 4.97 µW | Power | Input capacitor power dissipation
14. Cout Pd | 629.74 µW | Power | Output capacitor power dissipation
15. Diode Pd | 102.65 mW | Power | Diode power dissipation
16. IC Pd | 329.56 mW | Power | IC power dissipation
17. L Pd | 74.647 mW | Power | Inductor power dissipation
18. Total Pd | 508.604 mW | Power | Total Power Dissipation
19. BOM Count | 9 | System
| | | Information | Total Design BOM count
20. Duty Cycle | 63.538 % | System
| | | Information | Duty cycle
21. Efficiency | 87.621 % | System
| | | Information | Steady state efficiency
22. FootPrint | 118.0 mm² | System
| | | Information | Total Foot Print Area of BOM components
23. Frequency | 1.6 MHz | System
| | | Information | Switching frequency
24. Iout | 300.0 mA | System
| | | Information | Iout operating point
25. Mode | CCM | System
| | | Information | Conduction Mode
26. Pout | 3.6 W | System
| | | Information | Total output power
27. Total BOM | $0.62 | System
| | | Information | Total BOM Cost
28. Vin | 5.0 V | System
| | | Information | Vin operating point
29. Vout Actual | 12.143 V | System
| | | Information | Vout Actual calculated based on selected voltage divider resistors
30. Vout Tolerance | 3.885 % | System
| | | Information | Vout Tolerance based on IC Tolerance (no load) and voltage divider resistors if applicable
31. Vout p-p | 3.573 mV | System
| | | Information | Peak-to-peak output ripple voltage

## Design Inputs

Name | Value | Description
| Iout | | 300.0 m | Maximum Output Current
VinMax | 5.0 | Maximum input voltage
VinMin | 5.0 | Minimum input voltage
Vout | 12.0 | Output Voltage
| base_pn | | LMR62014X | Base Product Number
source | DC | Input Source Type
Ta | 30.0 | Ambient temperature


Copyright © 2022, Texas Instruments Incorporated | 6 | ti.com/webench

## Assembly

## Component Testing

Some published data on components in datasheets such as Capacitor ESR and Inductor DC resistance is based on conservative values that will guarantee that the components always exceed the specification. For design purposes it is usually better to work with typical values. Since this data is not always available it is a good practice to measure the Capacitance and ESR values of Cin and Cout, and the inductance and DC resistance of L1 before assembly of the board. Any large discrepancies in values should be electrically simulated in WEBENCH to check for instabilities and thermally simulated in WebTHERM to make sure critical temperatures are not exceeded.

## Soldering Component to Board

If board assembly is done in house it is best to tack down one terminal of a component on the board then solder the other terminal. For surface mount parts with large tabs, such as the DPAK, the tab on the back of the package should be pre-tinned with solder, then tacked into place by one of the pins. To solder the tab town to the board place the iron down on the board while resting against the tab, heating both surfaces simultaneously. Apply light pressure to the top of the plastic case until the solder flows around the part and the part is flush with the PCB. If the solder is not flowing around the board you may need a higher wattage iron (generally 25W to 30W is enough).

## Initial Startup of Circuit

It is best to initially power up the board by setting the input supply voltage to the lowest operating input voltage 5.0V and set the input supply's current limit to zero. With the input supply off connect up the input supply to Vin and GND. Connect a digital volt meter and a load if needed to set the minimum Iout of the design from Vout and GND. Turn on the input supply and slowly turn up the current limit on the input supply. If the voltage starts to rise on the input supply continue increasing the input supply current limit while watching the output voltage. If the current increases on the input supply, but the voltage remains near zero, then there may be a short or a component misplaced on the board. Power down the board and visually inspect for solder bridges and recheck the diode and capacitor polarities. Once the power supply circuit is operational then more extensive testing may include full load testing, transient load and line tests to compare with simulation results.

## Load Testing

The setup is the same as the initial startup, except that an additional digital voltmeter is connected between Vin and GND, a load is connected between Vout and GND and a current meter is connected in series between Vout and the load. The load must be able to handle at least rated output power + 50% ( 7.5 watts for this design). Ideally the load is supplied in the form of a variable load test unit. It can also be done in the form of suitably large power resistors. When using an oscilloscope to measure waveforms on the prototype board, the ground leads of the oscilloscope probes should be as short as possible and the area of the loop formed by the ground lead should be kept to a minimum. This will help reduce ground lead inductance and eliminate EMI noise that is not actually present in the circuit.

## Design Assistance

1. Master key : E4B9CFD1C57BC38D[v1]
2. LMR62014X Product Folder : http://www.ti.com/product/LMR62014 : contains the data sheet and other resources.

Copyright © 2022, Texas Instruments Incorporated | 7 | ti.com/webench

Important Notice and Disclaimer

TI provides technical and reliability data (including datasheets), design resources (including reference designs), application or other design advice, web tools, safety information, and other resources AS IS and with all faults, and disclaims all warranties. These resources are intended for skilled developers designing with TI products. You are solely responsible for (1) selecting the appropriate TI products for your application, (2) designing, validating and testing your application, and (3) ensuring your application meets applicable standards, and any other safety, security, or other requirements.

These resources are subject to change without notice. TI grants you permission to use these resources only for development of an application that uses the TI products described in the resource. Other reproduction and display of these resources is prohibited. No license is granted to any other TI intellectual property right or to any third party intellectual property right. TI disclaims responsibility for, and you will fully indemnify TI and its representatives against, any claims, damages, costs, losses, and liabilities arising out of your use of these resources.

Providing these resources does not expand or otherwise alter TI's applicable Terms of Sale or other applicable terms available either on ti.com or provided in conjunction with TI products.

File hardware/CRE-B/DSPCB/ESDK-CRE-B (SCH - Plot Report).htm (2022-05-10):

## Plot Report

Report Written: | Tuesday, May 10, 2022
Project Path: | C:\Users\Callum\Documents\GitHub\ESDK\hardware\CRE-B\DSPCB\ESDK-CRE-B.prj
Design Path: | C:\Users\Callum\Documents\GitHub\ESDK\hardware\CRE-B\DSPCB\ESDK-CRE-B.sch
Design Title:
Created:
Last Saved: | 10/05/2022 14:05:37
Editing Time: | 811 min
Units: | thou (precision 2)

## Device Settings

### PDF Settings

Combine Plots Yes
Use Bookmarks Yes
Component Details Yes
Symbol Details Yes
Link Net Names Yes
View PDF Yes
All Colours Black No
Embed Fonts Yes

## Plots Output

### PDF Output

Layer

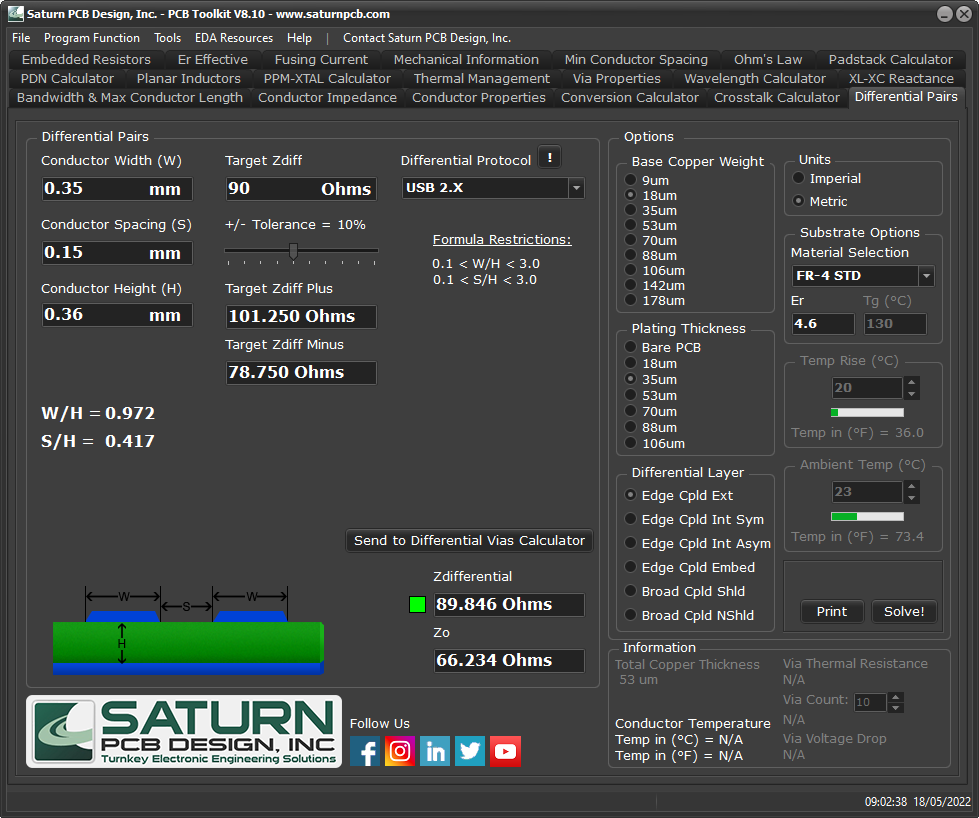
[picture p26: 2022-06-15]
hardware/NRD/Docs/usb_impedance_calc.png

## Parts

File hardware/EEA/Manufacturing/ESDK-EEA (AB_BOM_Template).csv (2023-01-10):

Names | Value | Quantity | Manufacturer | Manufacturer Part Number | RS PN | Component
C1-3 | 100nF | 3 | AVX | 06035C104K4T2A |  | Capacitor
D1-2 |  | 2 | SEMTECH | RCLAMP0582BQTCT |  | RCLAMP0582BQTCT
IC1 |  | 1 | NXP | PCA9508DP,118 |  | PCA9508DP,118
IC2 |  | 1 | Texas Instruments | LSF0102DCTR |  | LSF0102DCTR
J1 |  | 1 | SAMTEC | SSW-106-02-G-S-RA | 7655676P | SSW-106-02-G-S-RA
J2 |  | 1 | SAMTEC | TSW-106-08-G-D-RA | 1803394 | TSW-106-08-G-D-RA
J3, J5 |  | 2 | Seeedstudio | 110990030 | 179-3735 | Grove_Universal_4_Pin_connector
J4 |  | 1 | JST (JAPAN SOLDERLESS TERMINALS) | SM04B-SRSS-TB(LF)(SN) |  | SM04B-SRSS-TB_LF__SN_
PL1 |  | 1 | Harwin | M20-9990345 |  | CONN_SIL_3
R3-4 | 3K9 | 2 | KOA | RK73B1JTTD392J |  | Resistor
R5-9 | 200K | 5 | Vishay | CRCW0603200KFKEA |  | Resistor
Sub-total: |  | 20

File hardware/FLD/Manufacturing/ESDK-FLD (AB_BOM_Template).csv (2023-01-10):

Names | Value | Quantity | Manufacturer | Manufacturer Part Number | RS PN | Component
CONN1 |  | 1 |  |  |  | SolderBridge_0603_NC
H1-2 |  | 2 | PEM | SMTSO-M25-2ET |  | SMTSO-M25-2ET
J1 |  | 1 | SAMTEC | SSW-106-02-G-D-RA | 7655679P | SSW-106-02-G-D-RA
J2 |  | 1 | SAMTEC | TSW-106-08-G-D-RA | 1803394 | TSW-106-08-G-D-RA
J3 |  | 1 | Molex | 5055680771 |  | 5055680771
LED1 |  | 1 | Kingbright | KPA-3010CGCK | 8624691P | KPA-3010CGCK
M1 |  | 1 | Sensirion | SFA30-D-T |  | SFA30-D-T
R1 | 330R | 1 | TE Connectivity | CRG0603F330R | 213-2200 | Resistor
Sub-total: |  | 9

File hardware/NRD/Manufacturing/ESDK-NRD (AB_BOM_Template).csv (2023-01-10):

Names | Value | Quantity | Manufacturer | Manufacturer Part Number | RS PN | Component
C1-7, C9-10, C12-14 | 100nF | 12 | AVX | 06035C104K4T2A | 6983251 | Capacitor
C8, C11, C19-20 | 1uF | 4 | Taiyo Yuden | EMK107BJ105KA-T | 172-1530 | Capacitor
C15-16 | 27p | 2 | AVX | 06031A270JAT2A |  | Capacitor
C17-18 | 4.7uF | 2 | Wurth Elektronik | 885012106005 |  | Capacitor
CONN1 |  | 1 |  |  |  | SolderBridge_0603_NC
IC1 |  | 1 | RASPBERRY-PI | RP2040 | 2211611 | RP2040
IC2 |  | 1 | Winbond | W25Q128JVSIM TR |  | W25Q128JVSIM_TR
J1 |  | 1 | SAMTEC | SSW-106-02-G-D-RA | 7655679P | SSW-106-02-G-D-RA
J2 |  | 1 | SAMTEC | TSW-106-08-G-D-RA | 1803394 | TSW-106-08-G-D-RA
J3 |  | 1 | GCT (GLOBAL CONNECTOR TECHNOLOGY) | USB4110-GF-A |  | USB4110-GF-A
J4 |  | 1 | Harwin | M20-9990345 | 6812975P | M20-9990345
LED1 |  | 1 | Kingbright | KPA-3010CGCK | 8624691P | KPA-3010CGCK
LED2 |  | 1 | Avago Technologies | HSMH-C170 | 4860468P | HSMH-C170
PS1 |  | 1 | Microchip | MIC5317-3.3YM5-TR | 2097702 | MIC5317-3.3YM5-TR
Q1 |  | 1 | Diodes Inc. | 2N7002E-7-F | 8228641P | 2N7002E-7-F
R1-2 | 27R4 | 2 | TE Connectivity | CPF0603B27R4E1 |  | Resistor
R3 | DNP | 1 |  |  |  | Resistor
R4-5, R7 | 1K | 3 | TE Connectivity | CRG0603F1K0 |  | Resistor
R6, R10 | 330R | 2 | Yageo | RC0603FR-07330RL |  | Resistor
R8-9 | 1K8 | 2 | Vishay | CRCW06031K80FKEA |  | Resistor
R11-12, R14 | 5K1 | 3 | Yageo | RC0603FR-075K1L |  | Resistor
R13 | 3K9 | 1 | Yageo | RC0603FR-073K9L |  | Resistor
S1 |  | 1 | Wurth Elektronik | 434123050816 | 7856431 | 434123050816
U1 |  | 1 |  |  |  | Teviso BG51
XTAL1 |  | 1 | ABRACON | ABLS-12.000MHZ-B4-T | 1710501P | ABLS-12.000MHZ-B4-T
Sub-total: |  | 48

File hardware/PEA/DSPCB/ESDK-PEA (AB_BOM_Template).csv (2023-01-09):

Names | Value | Quantity | Manufacturer | Manufacturer Part Number | RS PN | Component
J1 |  | 1 | SAMTEC | SSW-106-02-G-D-RA | 7655679P | SSW-106-02-G-D-RA
J2 |  | 1 | Molex | 53398-0871 | 6563030P | 53398-0871
J3 |  | 1 | Seeedstudio | 110990030 | 179-3735 | Grove_Universal_4_Pin_connector
LED1 |  | 1 | OSRAM | LG Q396 | 915-4709 | LED
LED2 |  | 1 | OSRAM | LY Q396 | 915-4709 | LED
R1-2 | 330R | 2 | TE Connectivity | CRG0603F330R | 213-2200 | Resistor
Sub-total: |  | 7

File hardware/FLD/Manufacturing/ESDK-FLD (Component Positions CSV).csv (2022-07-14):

Name | Component | Side | Place X | Place Y | Rotation
J3 | 5055680771 | Top | 522.913 | 481.335 | 270.00
LOGO2 | Designspark_Logo | Top | 478.200 | 524.100 | 0.00
LED1 | KPA-3010CGCK | Top | 499.877 | 531.851 | 0.00
R1 | Resistor | Top | 496.200 | 527.900 | 180.00
LOGO1 | RS_Logo | Top | 478.805 | 514.431 | 0.00
M1 | SFA30-D-T | Top | 501.500 | 502.000 | 180.00
H1 | SMTSO-M25-2ET | Top | 510.500 | 502.000 | 0.00
H2 | SMTSO-M25-2ET | Top | 492.500 | 521.000 | 0.00
CONN1 | SolderBridge_0603_NC | Top | 506.300 | 529.700 | 180.00
J1 | SSW-106-02-G-D-RA | Top | 527.960 | 500.000 | 90.00
J2 | TSW-106-08-G-D-RA | Top | 477.500 | 500.000 | 90.00

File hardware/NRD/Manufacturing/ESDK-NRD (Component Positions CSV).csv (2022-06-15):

Name | Component | Side | Place X | Place Y | Rotation
Q1 | 2N7002E-7-F | Top | 498.500 | 469.500 | 0.00
S1 | 434123050816 | Top | 516.200 | 480.300 | 90.00
XTAL1 | ABLS-12.000MHZ-B4-T | Top | 471.600 | 484.640 | 270.00
C1 | Capacitor | Top | 483.000 | 471.600 | 0.00
C2 | Capacitor | Top | 480.600 | 471.600 | 0.00
C3 | Capacitor | Top | 485.700 | 484.800 | 180.00
C4 | Capacitor | Top | 480.600 | 484.800 | 180.00
C5 | Capacitor | Top | 492.600 | 472.600 | 90.00
C6 | Capacitor | Top | 492.600 | 471.100 | 90.00
C7 | Capacitor | Top | 474.800 | 473.100 | 0.00
C8 | Capacitor | Top | 492.600 | 474.100 | 90.00
C9 | Capacitor | Top | 485.100 | 471.600 | 0.00
C10 | Capacitor | Top | 486.600 | 471.600 | 0.00
C11 | Capacitor | Top | 492.600 | 475.600 | 90.00
C12 | Capacitor | Top | 490.100 | 480.400 | 90.00
C13 | Capacitor | Top | 476.300 | 473.100 | 0.00
C14 | Capacitor | Top | 511.300 | 479.100 | 0.00
C15 | Capacitor | Top | 476.000 | 488.500 | 90.00
C16 | Capacitor | Top | 470.500 | 475.400 | 270.00
C17 | Capacitor | Top | 483.600 | 512.400 | 270.00
C18 | Capacitor | Top | 487.000 | 512.400 | 270.00
C19 | Capacitor | Top | 522.500 | 488.450 | 180.00
C20 | Capacitor | Top | 516.500 | 491.800 | 90.00
LOGO2 | Designspark_Logo | Top | 500.000 | 519.400 | 0.00
LED2 | HSMH-C170 | Top | 502.500 | 469.500 | 0.00
LED1 | KPA-3010CGCK | Top | 499.877 | 531.851 | 0.00
J4 | M20-9990345 | Top | 514.640 | 494.200 | 0.00
PS1 | MIC5317-3.3YM5-TR | Top | 519.400 | 488.850 | 180.00
R1 | Resistor | Top | 488.400 | 478.400 | 270.00
R2 | Resistor | Top | 488.400 | 476.900 | 270.00
R3 | Resistor | Top | 503.900 | 482.000 | 270.00
R4 | Resistor | Top | 500.300 | 482.000 | 90.00
R5 | Resistor | Top | 474.600 | 477.500 | 270.00
R6 | Resistor | Top | 507.100 | 469.500 | 90.00
R7 | Resistor | Top | 482.600 | 488.100 | 0.00
R8 | Resistor | Top | 483.600 | 514.000 | 270.00
R9 | Resistor | Top | 487.000 | 514.000 | 270.00
R10 | Resistor | Top | 494.000 | 529.700 | 180.00
R11 | Resistor | Top | 523.100 | 478.800 | 0.00
R12 | Resistor | Top | 523.100 | 483.900 | 0.00
R13 | Resistor | Top | 495.600 | 469.500 | 0.00
R14 | Resistor | Top | 478.300 | 471.600 | 180.00
IC1 | RP2040 | Top | 481.600 | 478.100 | 270.00
LOGO1 | RS_Logo | Top | 500.105 | 524.030 | 0.00
CONN1 | SolderBridge_0603_NC | Top | 506.300 | 529.700 | 180.00
J1 | SSW-106-02-G-D-RA | Top | 527.960 | 500.000 | 90.00
U1 | Teviso BG51 | Top | 499.960 | 499.433 | 0.00
J2 | TSW-106-08-G-D-RA | Top | 477.500 | 500.000 | 90.00
J3 | USB4110-GF-A | Top | 529.764 | 481.900 | 90.00
IC2 | W25Q128JVSIM_TR | Top | 504.000 | 478.100 | 0.00

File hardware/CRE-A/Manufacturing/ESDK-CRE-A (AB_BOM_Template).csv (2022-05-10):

Names | Value | Quantity | Manufacturer | Manufacturer Part Number | Component
C1-2 | 10uF | 2 | Murata | GRM21BR61E106KA73L | Capacitor
C3 | 330pF | 1 | Yageo | CC0603JRNPO9BN331 | Capacitor
C4-5 | 100nF | 2 | AVX | 06035C104K4T2A | Capacitor
CONN1 |  | 1 |  |  | SolderBridge_0603_NC
D1 |  | 1 | ON Semiconductor | MBR0530T3G | MBR0530T3G
D2-3 |  | 2 | Bourns | CDSOT23-0502B | CDSOT23-0502B
F1 |  | 1 | LITTELFUSE | 1210L020WR | 1210L020WR
IC1 |  | 1 | Nexperia | PCA9615DP | PCA9615DP
J1 |  | 1 | Amphenol | 54601-908WPLF | 54601-908WPLF
J2 |  | 1 | SAMTEC | TSW-106-08-G-D-RA | TSW-106-08-G-D-RA
L1 |  | 1 | Bourns | SRN5020TA-120M | SRN5020TA-120M
LED1 |  | 1 | Kingbright | KPA-3010YC | KPA-3010YC
LED2 |  | 1 | Wurth Elektronik | 150060BS75000 | 150060BS75000
R1 | 118K | 1 | Yageo | RC0603FR-07118KL | Resistor
R2 | 13K3 | 1 | Yageo | AC0603FR-1313K3L | Resistor
R3, R5-6, R8 | 390R | 4 | TE Connectivity | CRGCQ0603F390R | Resistor
R4, R7 | 100R | 2 | TE Connectivity | CRGCQ0603J100R | Resistor
R9 | 330R | 1 | TE Connectivity | CRG0603F330R | Resistor
R10 | 3K3 | 1 | Yageo | RC0603FR-073K3L | Resistor
S1 |  | 1 | Texas Instruments | LMR62014XMF/NOPB | LMR62014XMF_NOPB
Sub-total: |  | 27

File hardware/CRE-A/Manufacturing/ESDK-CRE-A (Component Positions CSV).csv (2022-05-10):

Name | Component | Side | Place X | Place Y | Rotation
F1 | 1210L020WR | Top | 507.000 | 511.500 | 270.00
J1 | 54601-908WPLF | Top | 508.430 | 500.145 | 90.00
LED2 | 150060BS75000 | Top | 511.000 | 510.600 | 180.00
C1 | Capacitor | Top | 495.400 | 515.900 | 0.00
C2 | Capacitor | Top | 492.100 | 521.900 | 180.00
C3 | Capacitor | Top | 489.100 | 517.000 | 90.00
C4 | Capacitor | Top | 491.600 | 482.895 | 270.00
C5 | Capacitor | Top | 497.000 | 485.200 | 270.00
D2 | CDSOT23-0502B | Top | 501.700 | 510.000 | 180.00
D3 | CDSOT23-0502B | Top | 507.300 | 490.400 | 180.00
LOGO2 | Designspark_Logo | Top | 500.000 | 474.800 | 0.00
LED1 | KPA-3010YC | Top | 500.000 | 531.200 | 0.00
S1 | LMR62014XMF_NOPB | Top | 492.600 | 517.000 | 270.00
D1 | MBR0530T3G | Top | 495.400 | 521.300 | 270.00
IC1 | PCA9615DP | Top | 496.981 | 481.895 | 0.00
R1 | Resistor | Top | 489.100 | 518.700 | 90.00
R2 | Resistor | Top | 490.900 | 514.000 | 90.00
R3 | Resistor | Top | 496.100 | 488.900 | 90.00
R4 | Resistor | Top | 499.400 | 488.900 | 90.00
R5 | Resistor | Top | 502.700 | 488.900 | 90.00
R6 | Resistor | Top | 502.900 | 484.695 | 0.00
R7 | Resistor | Top | 502.900 | 481.395 | 0.00
R8 | Resistor | Top | 502.900 | 478.095 | 0.00
R9 | Resistor | Top | 498.200 | 527.700 | 0.00
R10 | Resistor | Top | 511.800 | 513.400 | 180.00
LOGO1 | RS_Logo | Top | 510.005 | 520.331 | 0.00
CONN1 | SolderBridge_0603_NC | Top | 501.800 | 527.700 | 180.00
L1 | SRN5020TA-120M | Top | 499.200 | 517.700 | 90.00
J2 | TSW-106-08-G-D-RA | Top | 495.000 | 500.000 | 90.00

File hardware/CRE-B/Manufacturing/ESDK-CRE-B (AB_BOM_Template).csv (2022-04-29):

Names | Value | Quantity | Manufacturer | Manufacturer Part Number | Component
C1 |  | 1 | Panasonic | EEEFC1V330P | EEEFC1V330P
C2 | 10nF | 1 | TDK | CGA3E2C0G1H103J080AA | Capacitor
C3, C6-7 | 10uF | 3 | Murata | GRM21BR61E106KA73L | Capacitor
C4-5, C11 | 100nF | 3 | AVX | 06035C104K4T2A | Capacitor
D1-2 |  | 2 | Bourns | CDSOT23-0502B | CDSOT23-0502B
D3-4 |  | 2 | ON Semiconductor | MBR0530T3G | MBR0530T3G
D5 |  | 1 | SEMTECH | RCLAMP0582BQTCT | RCLAMP0582BQTCT
FS1 |  | 1 | Bourns | MF-USMF035-2 | MF-USMF035-2
IC1 |  | 1 | Nexperia | PCA9615DP | PCA9615DP
IC2 |  | 1 | Texas Instruments | LMR12010XMK/NOPB | LMR12010XMK_NOPB
IC4 |  | 1 | ST Microelectronics | LD1117S33TR | LD1117S33TR
J1 |  | 1 | Amphenol | 54601-908WPLF | 54601-908WPLF
J2 |  | 1 | SAMTEC | SSW-106-02-G-D-RA | SSW-106-02-G-D-RA
L1 |  | 1 | Bourns | SRN5020TA-120M | SRN5020TA-120M
LED1 |  | 1 | OSRAM | LG Q396 | LED
LED2 |  | 1 | Wurth Elektronik | 150060BS75000 | 150060BS75000
LED3 |  | 1 | OSRAM | LY Q396 | LED
R1-2 | 10K | 2 | TE Connectivity | CRG0603F10K/10 | Resistor
R3, R5-6, R8 | 390R | 4 | TE Connectivity | CRGCQ0603F390R | Resistor
R4, R7 | 100R | 2 | TE Connectivity | CRGCQ0603J100R | Resistor
R9 | 52K3 | 1 | Panasonic | ERJ3EKF5232V | Resistor
R10 | 3K3 | 1 | Yageo | RC0603FR-073K3L | Resistor
R11-12 | 330R | 2 | TE Connectivity | CRG0603F330R | Resistor
R13-14 | 3K9 | 2 | KOA | RK73B1JTTD392J | Resistor
Z1 |  | 1 | ON Semiconductor | MMSZ5236BT1G | MMSZ5236BT1G
Sub-total: |  | 38

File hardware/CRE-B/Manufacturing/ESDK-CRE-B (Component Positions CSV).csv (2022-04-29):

Name | Component | Side | Place X | Place Y | Rotation
J1 | 54601-908WPLF | Top | 491.570 | 499.955 | 270.00
LED2 | 150060BS75000 | Top | 500.000 | 532.000 | 0.00
C2 | Capacitor | Top | 498.600 | 520.600 | 90.00
C3 | Capacitor | Top | 504.700 | 511.300 | 180.00
C4 | Capacitor | Top | 491.100 | 481.100 | 180.00
C5 | Capacitor | Top | 491.100 | 484.400 | 0.00
C6 | Capacitor | Top | 506.700 | 511.300 | 180.00
C7 | Capacitor | Top | 512.100 | 489.300 | 90.00
C11 | Capacitor | Top | 513.400 | 475.400 | 0.00
D1 | CDSOT23-0502B | Top | 503.700 | 503.400 | 270.00
D2 | CDSOT23-0502B | Top | 492.900 | 489.000 | 180.00
LOGO2 | Designspark_Logo | Top | 500.000 | 475.100 | 0.00
C1 | EEEFC1V330P | Top | 491.500 | 518.750 | 270.00
IC4 | LD1117S33TR | Top | 509.800 | 483.450 | 0.00
LED1 | LED | Top | 515.300 | 482.500 | 180.00
LED3 | LED | Top | 515.300 | 517.400 | 0.00
IC2 | LMR12010XMK_NOPB | Top | 498.600 | 523.300 | 180.00
D3 | MBR0530T3G | Top | 499.100 | 518.700 | 0.00
D4 | MBR0530T3G | Top | 503.400 | 521.400 | 0.00
FS1 | MF-USMF035-2 | Top | 510.900 | 512.300 | 0.00
Z1 | MMSZ5236BT1G | Top | 507.700 | 524.700 | 270.00
IC1 | PCA9615DP | Top | 493.900 | 482.800 | 90.00
D5 | RCLAMP0582BQTCT | Top | 498.900 | 481.100 | 180.00
R1 | Resistor | Top | 496.000 | 525.900 | 90.00
R2 | Resistor | Top | 501.800 | 526.100 | 0.00
R3 | Resistor | Top | 502.400 | 497.500 | 0.00
R4 | Resistor | Top | 502.400 | 494.200 | 0.00
R5 | Resistor | Top | 502.400 | 490.900 | 0.00
R6 | Resistor | Top | 505.400 | 499.500 | 0.00
R7 | Resistor | Top | 505.400 | 496.200 | 0.00
R8 | Resistor | Top | 505.400 | 492.900 | 0.00
R9 | Resistor | Top | 504.200 | 525.200 | 270.00
R10 | Resistor | Top | 499.200 | 529.400 | 0.00
R11 | Resistor | Top | 515.300 | 479.200 | 180.00
R12 | Resistor | Top | 515.300 | 520.700 | 0.00
R13 | Resistor | Top | 504.200 | 483.600 | 0.00
R14 | Resistor | Top | 502.100 | 483.600 | 0.00
LOGO1 | RS_Logo | Top | 509.905 | 516.530 | 0.00
L1 | SRN5020TA-120M | Top | 499.900 | 514.800 | 180.00
J2 | SSW-106-02-G-D-RA | Top | 510.760 | 500.000 | 90.00

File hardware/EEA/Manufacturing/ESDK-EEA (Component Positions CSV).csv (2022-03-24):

Name | Component | Side | Place X | Place Y | Rotation
C1 | Capacitor | Top | 498.800 | 506.100 | 180.00
C2 | Capacitor | Top | 501.900 | 506.100 | 180.00
C3 | Capacitor | Top | 492.700 | 488.200 | 270.00
PL1 | CONN_SIL_3 | Top | 511.440 | 480.000 | 90.00
LOGO2 | Designspark_Logo | Top | 500.000 | 474.800 | 0.00
J3 | Grove_Universal_4_Pin_connector | Top | 500.000 | 480.000 | 0.00
J5 | Grove_Universal_4_Pin_connector | Top | 500.300 | 517.400 | 0.00
IC2 | LSF0102DCTR | Top | 491.300 | 485.200 | 0.00
IC1 | PCA9508DP,118 | Top | 501.000 | 502.100 | 0.00
D1 | RCLAMP0582BQTCT | Top | 497.700 | 484.600 | 0.00
D2 | RCLAMP0582BQTCT | Top | 504.000 | 506.200 | 90.00
R3 | Resistor | Top | 502.500 | 511.000 | 0.00
R4 | Resistor | Top | 505.300 | 511.000 | 0.00
R5 | Resistor | Top | 486.300 | 485.500 | 0.00
R6 | Resistor | Top | 486.300 | 482.200 | 180.00
R7 | Resistor | Top | 496.000 | 488.200 | 270.00
R8 | Resistor | Top | 500.500 | 487.300 | 0.00
R9 | Resistor | Top | 502.200 | 487.300 | 0.00
LOGO1 | RS_Logo | Top | 500.305 | 522.831 | 0.00
J4 | SM04B-SRSS-TB_LF__SN_ | Top | 500.200 | 530.449 | 180.00
J1 | SSW-106-02-G-S-RA | Top | 512.090 | 500.000 | 90.00
J2 | TSW-106-08-G-D-RA | Top | 495.000 | 500.000 | 90.00

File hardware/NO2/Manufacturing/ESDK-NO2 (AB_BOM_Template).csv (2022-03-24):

Names | Value | Quantity | Manufacturer | Manufacturer Part Number | Component
C1-4, C6 | 100nF | 5 | AVX | 06035C104K4T2A | Capacitor
C5, C7-9 | 1uF | 4 | Yageo | CC0603KRX7R6BB105 | Capacitor
CONN1 |  | 1 |  |  | SolderBridge_0603_NC
IC1 |  | 1 | Texas Instruments | ADS1119IPWR | ADS1119IPWR
IC2 |  | 1 | Texas Instruments | REF4132A30DBVRQ1 | REF4132A30DBVRQ1
IC3 |  | 1 | Texas Instruments | LM2904LVIPWR | LM2904LVIPWR
J1 |  | 1 | SAMTEC | SSW-106-02-G-D-RA | SSW-106-02-G-D-RA
J2 |  | 1 | SAMTEC | TSW-106-08-G-D-RA | TSW-106-08-G-D-RA
J3 |  | 1 | SAMTEC | TSW-108-08-G-S-RA | TSW-108-08-G-S-RA
LED2 |  | 1 | Kingbright | KPA-3010CGCK | KPA-3010CGCK
M1 |  | 1 | PEM | SMTSO-M4-2ET | SMTSO-M4-2ET
R1 | 330R | 1 | TE Connectivity | CRG0603F330R | Resistor
R2-4 | 3K9 | 3 | KOA | RK73B1JTTD392J | Resistor
Sub-total: |  | 22

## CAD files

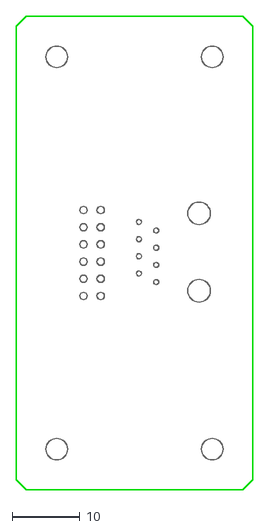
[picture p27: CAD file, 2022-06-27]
hardware/CRE-A/DSPCB/ESDK-CRE-A.dxf
35.0 x 70.0

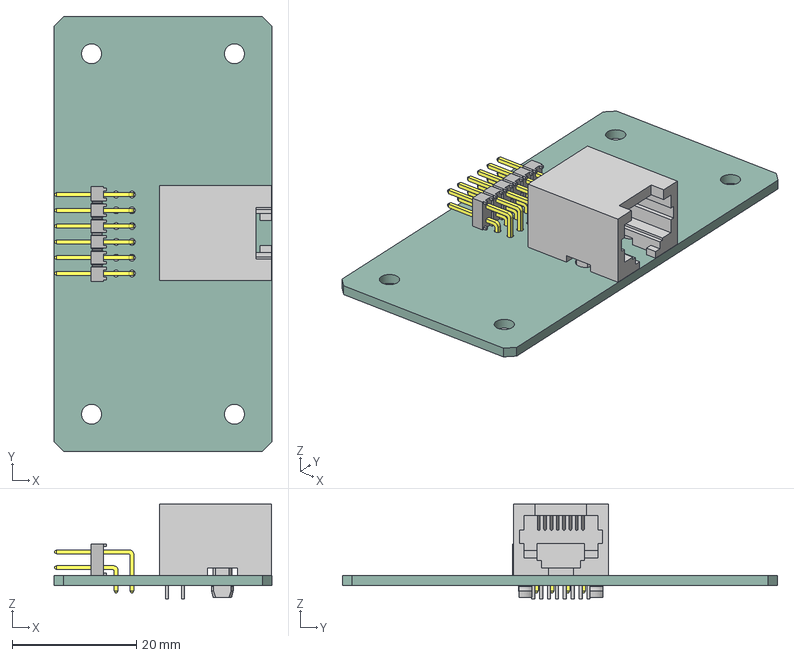
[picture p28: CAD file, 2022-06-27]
hardware/CRE-A/Mechanical/CRE-A.step
35.0 x 70.0 x 15.3 mm
_TSW-106-08-G-D-NA_body
_T-1S6-08-TSW-1-08-6-NA-D
s54601-908wplf

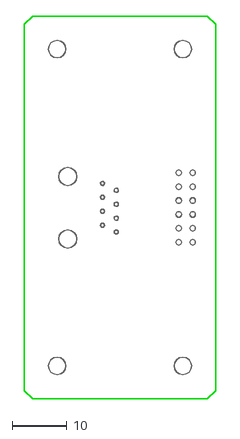
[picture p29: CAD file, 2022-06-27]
hardware/CRE-B/DSPCB/ESDK-CRE-B.dxf
35.0 x 70.0

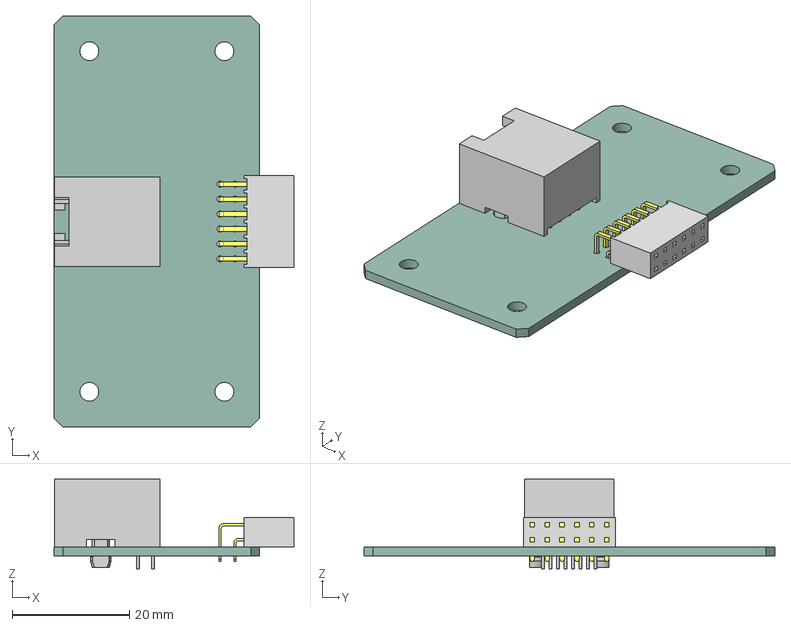
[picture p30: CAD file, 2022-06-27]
hardware/CRE-B/Mechanical/ESDK-CRE-B.step
40.8 x 70.0 x 15.3 mm
_T1SSW-106-02-G-D-RA
_P2SSW-106-02-G-D-RA
s54601-908wplf

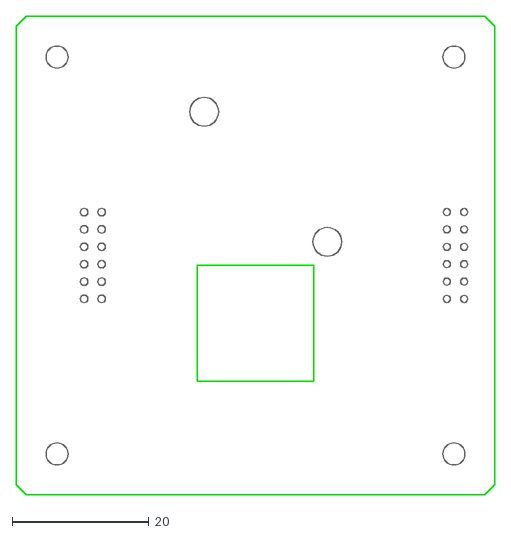
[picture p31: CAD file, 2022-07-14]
hardware/FLD/DSPCB/ESDK-FLD.dxf
70.0 x 70.0

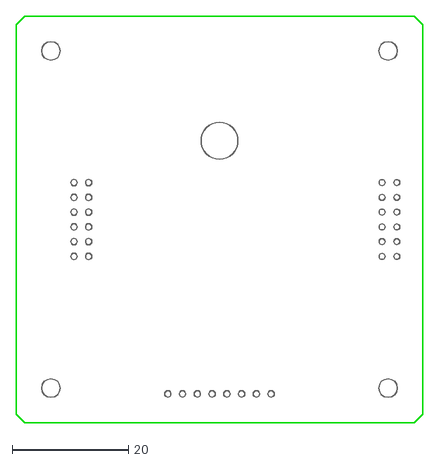
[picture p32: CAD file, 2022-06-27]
hardware/NO2/DSPCB/ESDK-NO2.dxf
70.0 x 70.0

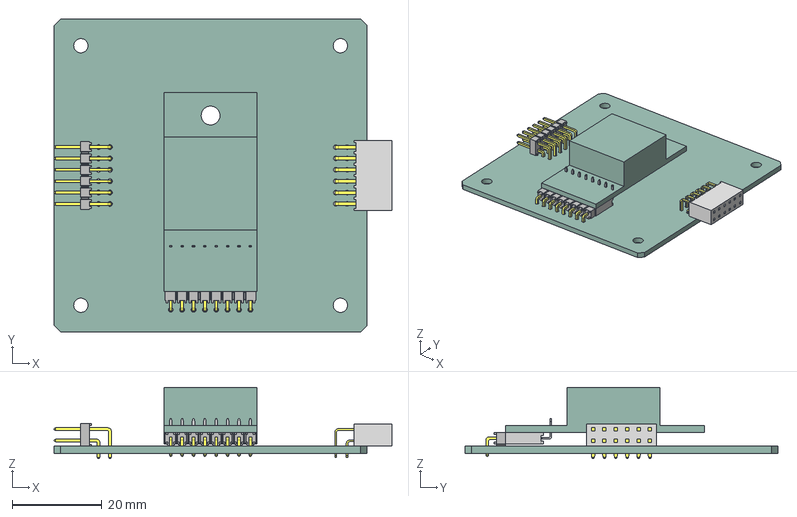
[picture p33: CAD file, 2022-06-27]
hardware/NO2/Mechanical/ESDK-NO2.step
75.5 x 70.0 x 15.9 mm
T-1S6-08-TSW-1-08-8-RA-S
TSW-108-08-G-S-RA_body
_ _ _C081LGBN-RC
_TSW-106-08-G-D-NA_body
_T-1S6-08-TSW-1-08-6-NA-D
_T1SSW-106-02-G-D-RA
_P2SSW-106-02-G-D-RA

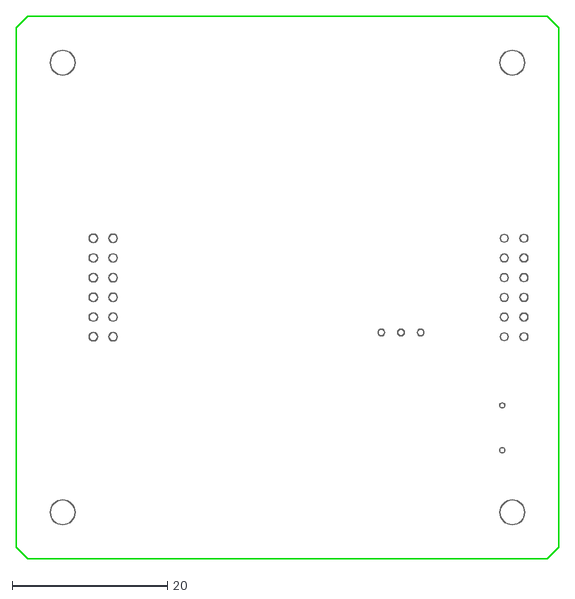
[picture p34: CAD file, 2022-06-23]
hardware/NRD/DSPCB/ESDK-NRD.dxf
70.0 x 70.0

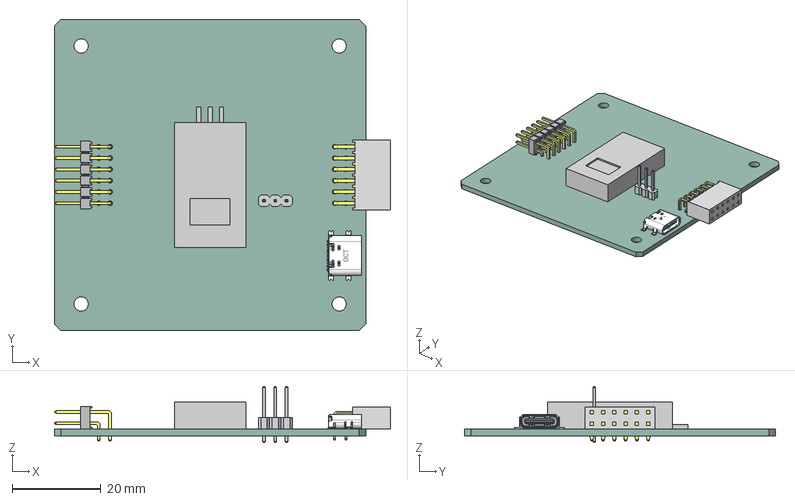
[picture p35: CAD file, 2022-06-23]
hardware/NRD/Mechanical/ESDK-NRD.step
75.5 x 70.0 x 12.6 mm
_TSW-106-08-G-D-NA_body
_T-1S6-08-TSW-1-08-6-NA-D
_T1SSW-106-02-G-D-RA
_P2SSW-106-02-G-D-RA
ÇÐ³ý-ÀÉì12
BG51
M20-SIL-MOULD
M20-972PIN x 3

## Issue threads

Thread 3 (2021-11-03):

Investigate power switches on module power rails

callumsnowden, 2021-11-03:
Rail power switching would provide a way to reset all the sensor modules should something go awry that cannot be recovered from (experienced with the CO2 sensor and a re-plug was necessary). This would also enable the module string to be powered off once the Pi shuts down, which does not happen currently.

Closed 2022-03-24.

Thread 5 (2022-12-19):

Update Sphinx docs.

9600, 2022-12-19:
- [ ] modules/index
- [ ] modules/* (all module pages)
- [ ] ESDK module specification

Main modules page needs updating to add I2C and GPIO details. Where a module uses I2C enter the address. With GPIO enter details of pin(s) used.

All ESDK module pages need updating to add theory of operation, schematic and board plots. Some also need the main header image.

Also need to add details to the module specification page, e.g. dimensions for single and double width, with any design notes such as keep-out areas. Connector, I/O and power spec etc.

9600, 2022-12-20:
Missing a few images:

- [ ] ESDK-EEA.jpg
- [ ] ESDK-Main-schematic.svg
- [ ] ESDK-Main-layout.png

callumsnowden, 2022-12-20:
ESDK-EEA images were commited in 283dcffce1134c1a4ee2bbb267659c488f7a19fe

callumsnowden, 2022-12-20:
Fixed typo in ESDK-MAIN image file paths in 84f20922fadb81cb8c316137419193869d56aeaa

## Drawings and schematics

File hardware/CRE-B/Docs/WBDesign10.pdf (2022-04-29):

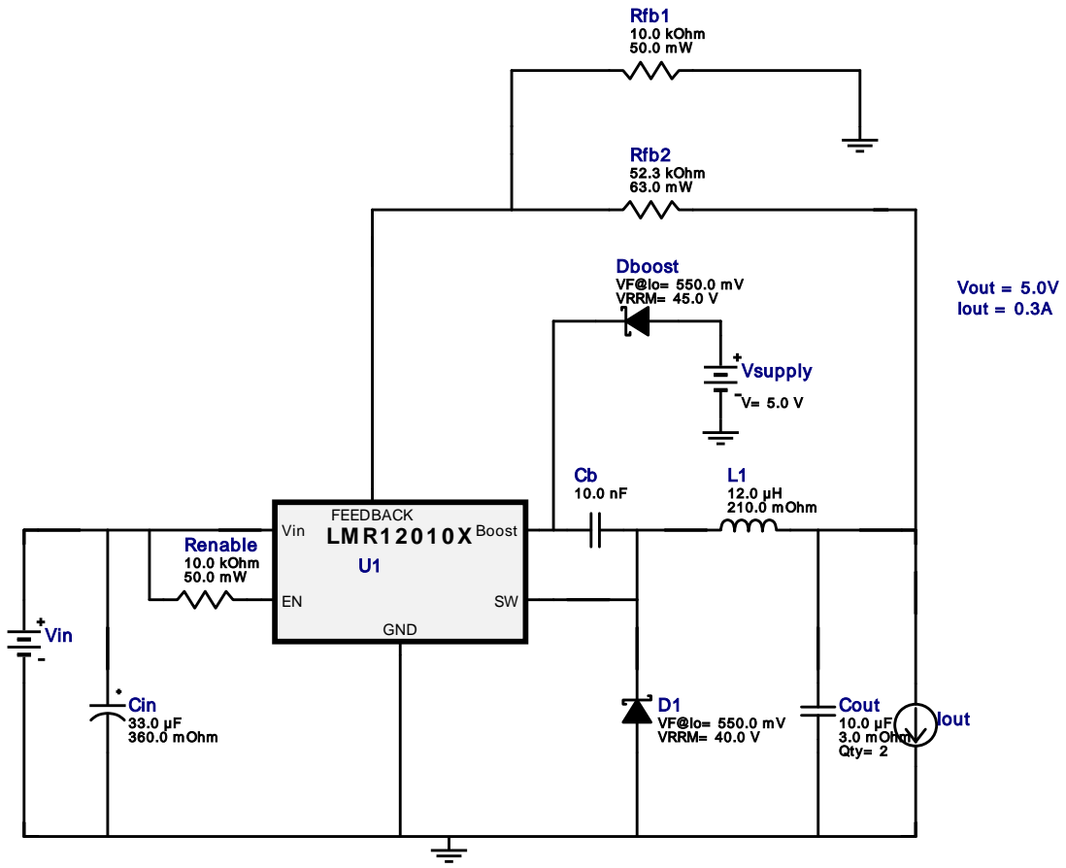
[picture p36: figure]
Cin 33.0 µF 360.0 m Ohm; Cout 10.0 µF 3.0 m Ohm Qty= 2; D1 VF@Io= 550.0 m V VRRM= 40.0 V; Dboost VF@Io= 550.0 m V VRRM= 45.0 V; L1 12.0 µH 210.0 m Ohm; Renable 10.0 kOhm 50.0 m W; FEEDBACK; Vin; Boost; GND; Vout = 5.0V Iout = 0.3A; Vsupply; Rfb1 10.0 kOhm 50.0 m W; Rfb2 52.3 kOhm 63.0 m W; Iout

Copyright © 2022, Texas Instruments Incorporated | 1 | ti.com/webench

WEBENCH®
Design Report LMR12010XMK/NOPB : LMR12010XMK/NOPB 12V-12V to 5.00V @ 0.3A April 4, 2022 03:38:35 GMT-05:00

## WEBENCH ® Design Report

Design : 10 LMR12010XMK/NOPB
LMR12010XMK/NOPB 12V-12V to 5.00V @ 0.3A

VinMin = 12.0V
VinMax = 12.0V
Vout = 5.0V
Iout = 0.3A

Device = LMR12010XMK/NOPB
Topology = Buck
Created = 2022-04-03 06:25:31.662 BOM Cost = $1.41
BOM Count = 11
Total Pd = 0.2W
1. The Boost pin voltage must be supplied from a source of less than 5.5V. Recommended methods are described in the LM2734 datasheet Application Information.

## Electrical BOM

Name | Manufacturer | Part Number | Properties | Qty Price | Footprint
Cb | TDK | CGA4C2C0G1H103J060AA (https://product.tdk.com/en/search/capacitor/ceramic/mlcc/info?part%5Fno%3DCGA4C2C0G1H103J060AA) Series= C0G/NP0 | Cap= 10.0 nF VDC= 50.0 V IRMS= 0.0 A
1 | $0.06
| | | | | 0805 7 mm²
Cin | Panasonic | EEE-FK1E330P (http://www.panasonic.com/industrial/components/pdf/smt%5Faec%5F050505.pdf) Series= FK | Cap= 33.0 uF ESR= 360.0 mOhm VDC= 25.0 V IRMS= 240.0 mA
1 | $0.11
| | | | | SM_RADIAL_D 84 mm²
Cout | Kemet | C0805C106K8PACTU (http://capacitoredge.kemet.com/capedge2/DataSheet/Datasheet%2DC0805C106K8PACTU.pdf?pn%3DC0805C106K8PACTU) Series= X5R | Cap= 10.0 uF ESR= 3.0 mOhm VDC= 10.0 V IRMS= 11.43 A
2 | $0.03
| | | | | 0805 7 mm²
D1 | Fairchild Semiconductor SS14FL | VF@Io= 550.0 mV
VRRM= 40.0 V

1 $0.04
SOD-123F 12 mm²
Dboost | Bourns | CD0603-B0240 (http://www.bourns.com/pdfs/SBCD0603%5F1005.pdf) | VF@Io= 550.0 mV VRRM= 45.0 V
1 | $0.09
Diode_0603 5 mm²

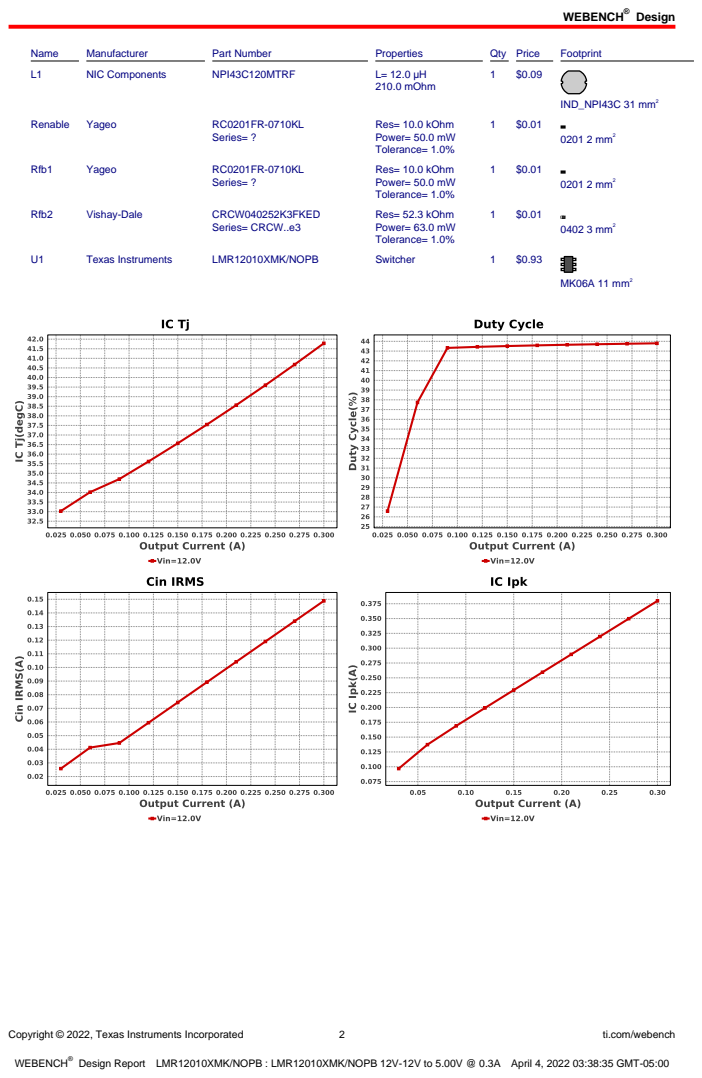
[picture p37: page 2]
Design; Copyright © 2022, Texas Instruments Incorporated; ti.com/webench; Name; Manufacturer; Part Number; Properties; Qty Price; Footprint; NIC Components; NPI43C120MTRF; 210.0 mOhm; IND_NPI43C 31 mm²; Renable; Yageo; Series= ?; Res= 10.0 kOhm Power= 50.0 mW Tolerance= 1.0%; 0201 2 mm²; Rfb1; Rfb2; Vishay-Dale; CRCW040252K3FKED; Series= CRCW..e3; Res= 52.3 kOhm Power= 63.0 mW Tolerance= 1.0%; 0402 3 mm²; Texas Instruments; LMR12010XMK/NOPB; Switcher; MK06A 11 mm²

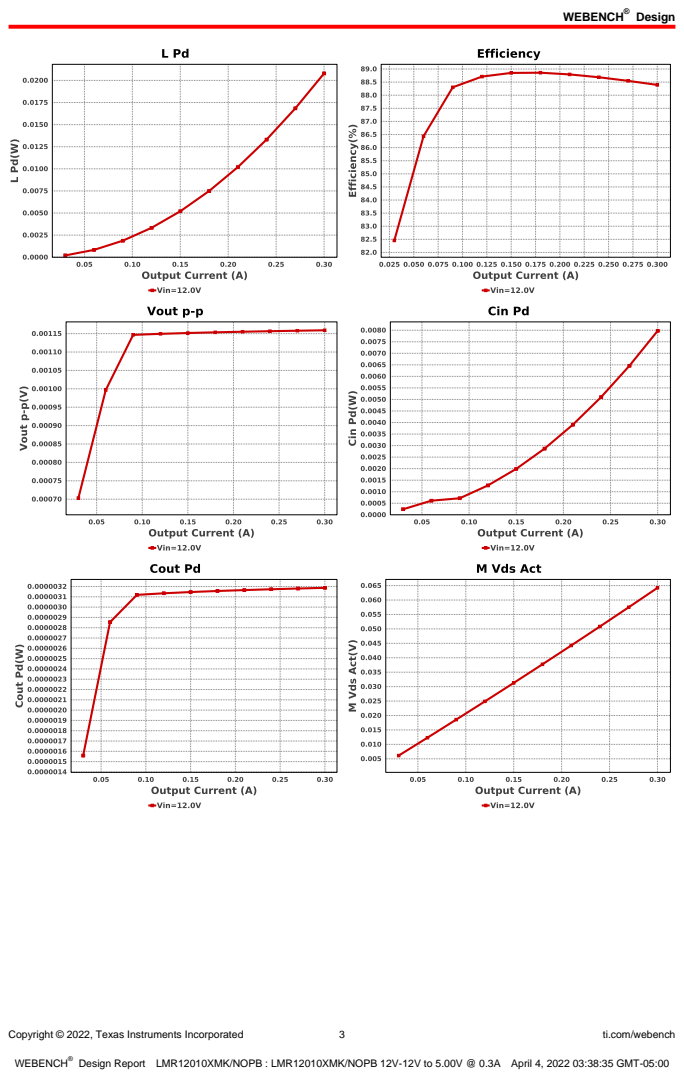
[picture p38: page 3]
Copyright © 2022, Texas Instruments Incorporated; ti.com/webench

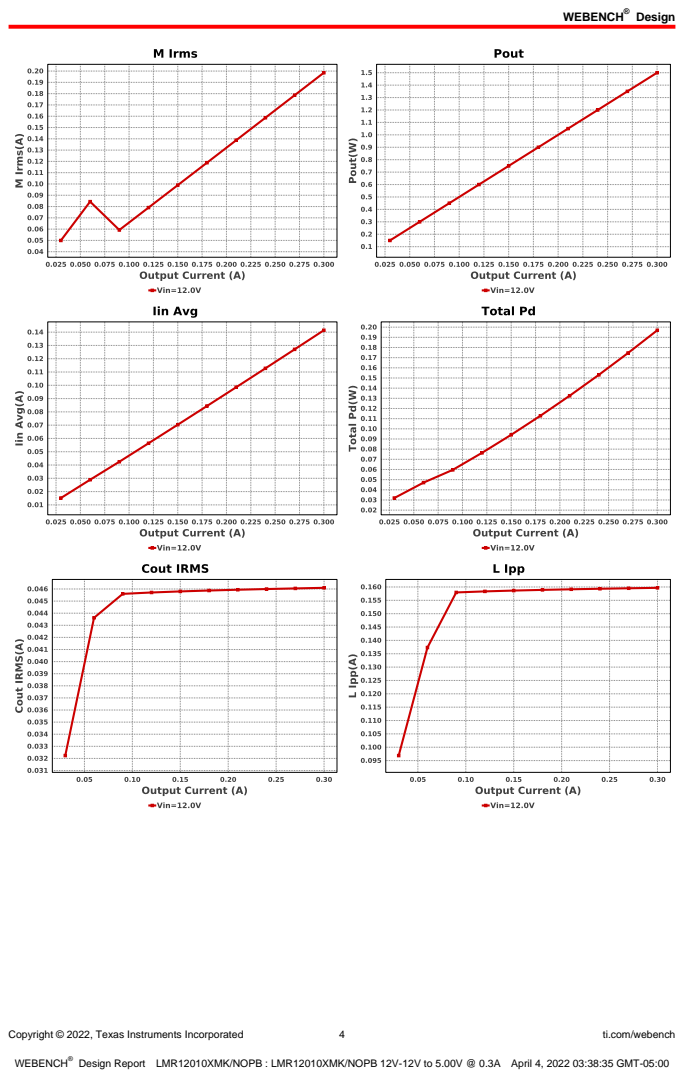
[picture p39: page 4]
Copyright © 2022, Texas Instruments Incorporated; ti.com/webench

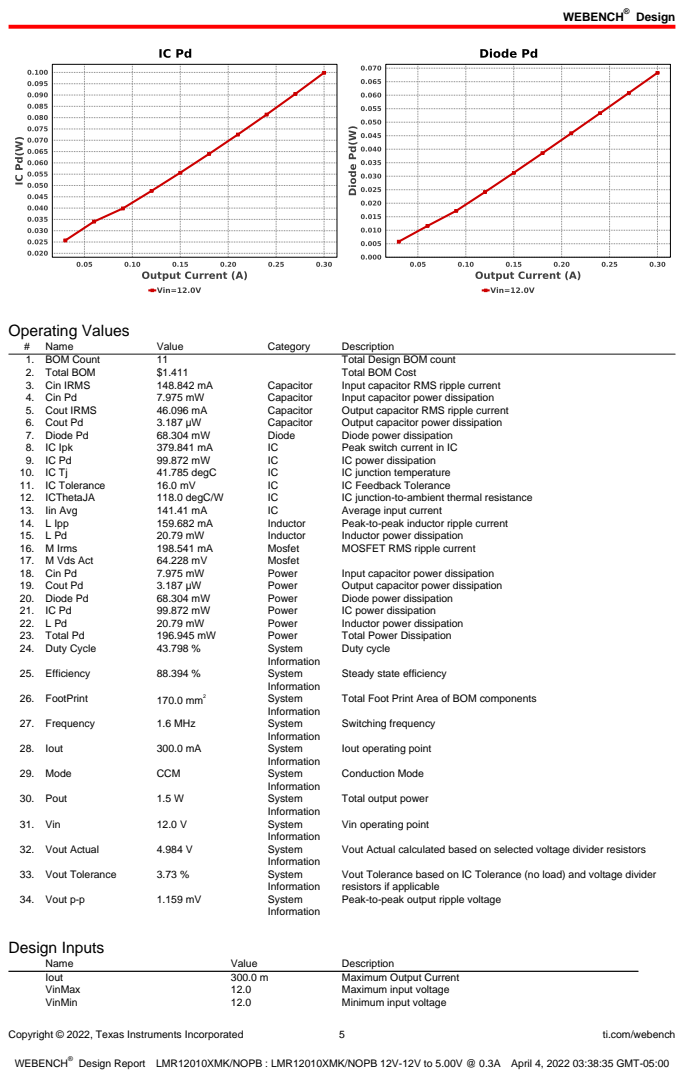
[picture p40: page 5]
Copyright © 2022, Texas Instruments Incorporated; ti.com/webench; Operating Values; Name; Value; Category; Description; 1. BOM Count; Total Design BOM count; 2. Total BOM; Total BOM Cost; 3. Cin IRMS; Capacitor; Input capacitor RMS ripple current; 4. Cin Pd; Input capacitor power dissipation; 5. Cout IRMS; Output capacitor RMS ripple current; 6. Cout Pd; Output capacitor power dissipation; 7. Diode Pd; Diode; Diode power dissipation; 8. IC Ipk; Peak switch current in IC; IC power dissipation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

Steady state efficiency

Total Foot Print Area of BOM components

Iout operating point

Total output power

Vin operating point

Vout Actual calculated based on selected voltage divider resistors

Vout Tolerance based on IC Tolerance (no load) and voltage divider
resistors if applicable
Peak-to-peak output ripple voltage

Copyright © 2022, Texas Instruments Incorporated | 6 | ti.com/webench
Name | Value | Description
Vout | 5.0 | Output Voltage
base_pn | LMR12010X | Base Product Number
source | DC | Input Source Type
Ta | 30.0 | Ambient temperature


Copyright © 2022, Texas Instruments Incorporated | 7 | ti.com/webench

## Assembly

## Component Testing

Some published data on components in datasheets such as Capacitor ESR and Inductor DC resistance is based on conservative values that will guarantee that the components always exceed the specification. For design purposes it is usually better to work with typical values. Since this data is not always available it is a good practice to measure the Capacitance and ESR values of Cin and Cout, and the inductance and DC resistance of L1 before assembly of the board. Any large discrepancies in values should be electrically simulated in WEBENCH to check for instabilities and thermally simulated in WebTHERM to make sure critical temperatures are not exceeded.
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

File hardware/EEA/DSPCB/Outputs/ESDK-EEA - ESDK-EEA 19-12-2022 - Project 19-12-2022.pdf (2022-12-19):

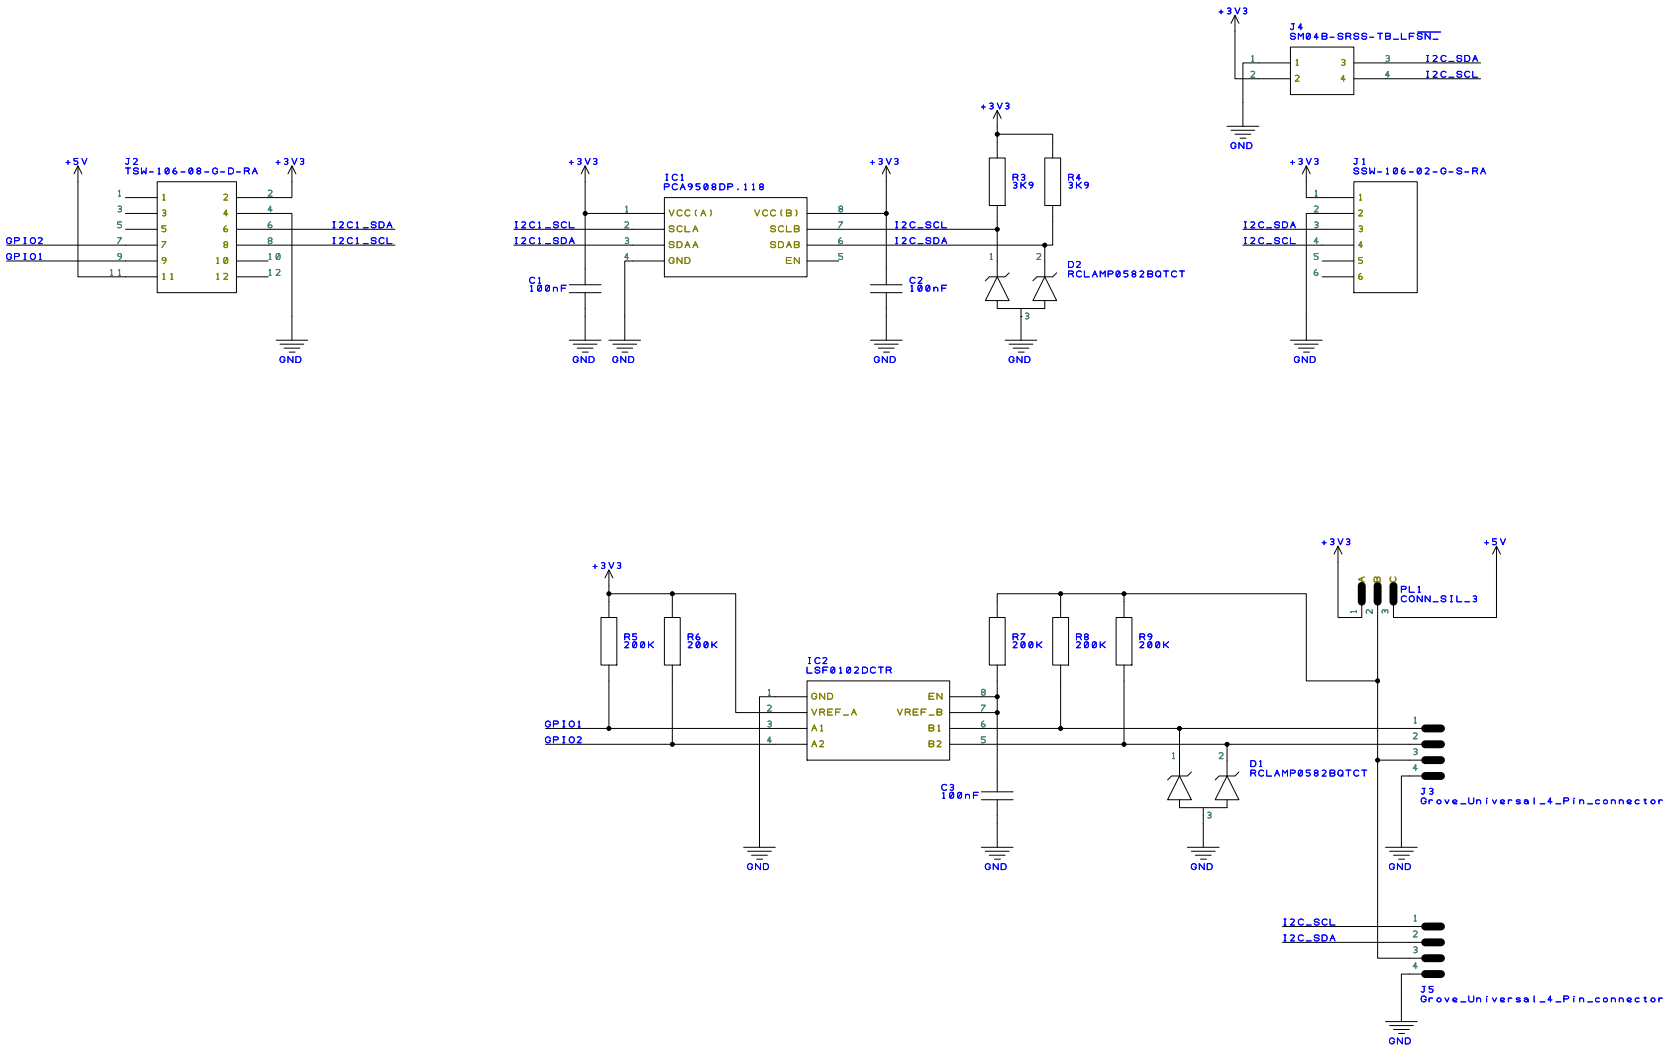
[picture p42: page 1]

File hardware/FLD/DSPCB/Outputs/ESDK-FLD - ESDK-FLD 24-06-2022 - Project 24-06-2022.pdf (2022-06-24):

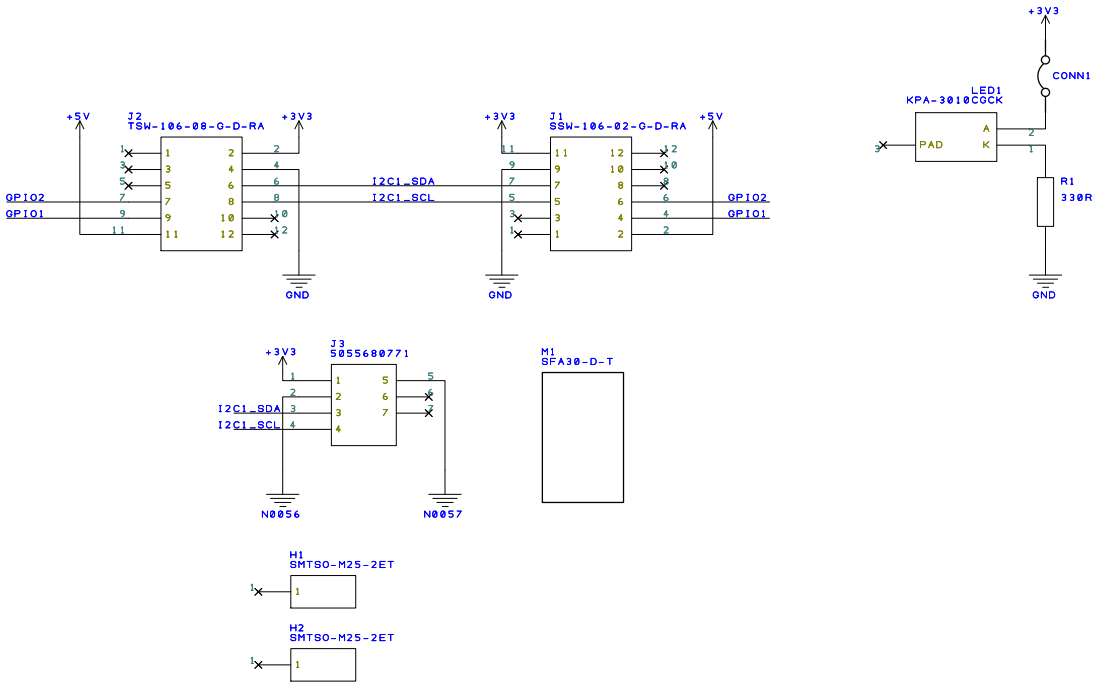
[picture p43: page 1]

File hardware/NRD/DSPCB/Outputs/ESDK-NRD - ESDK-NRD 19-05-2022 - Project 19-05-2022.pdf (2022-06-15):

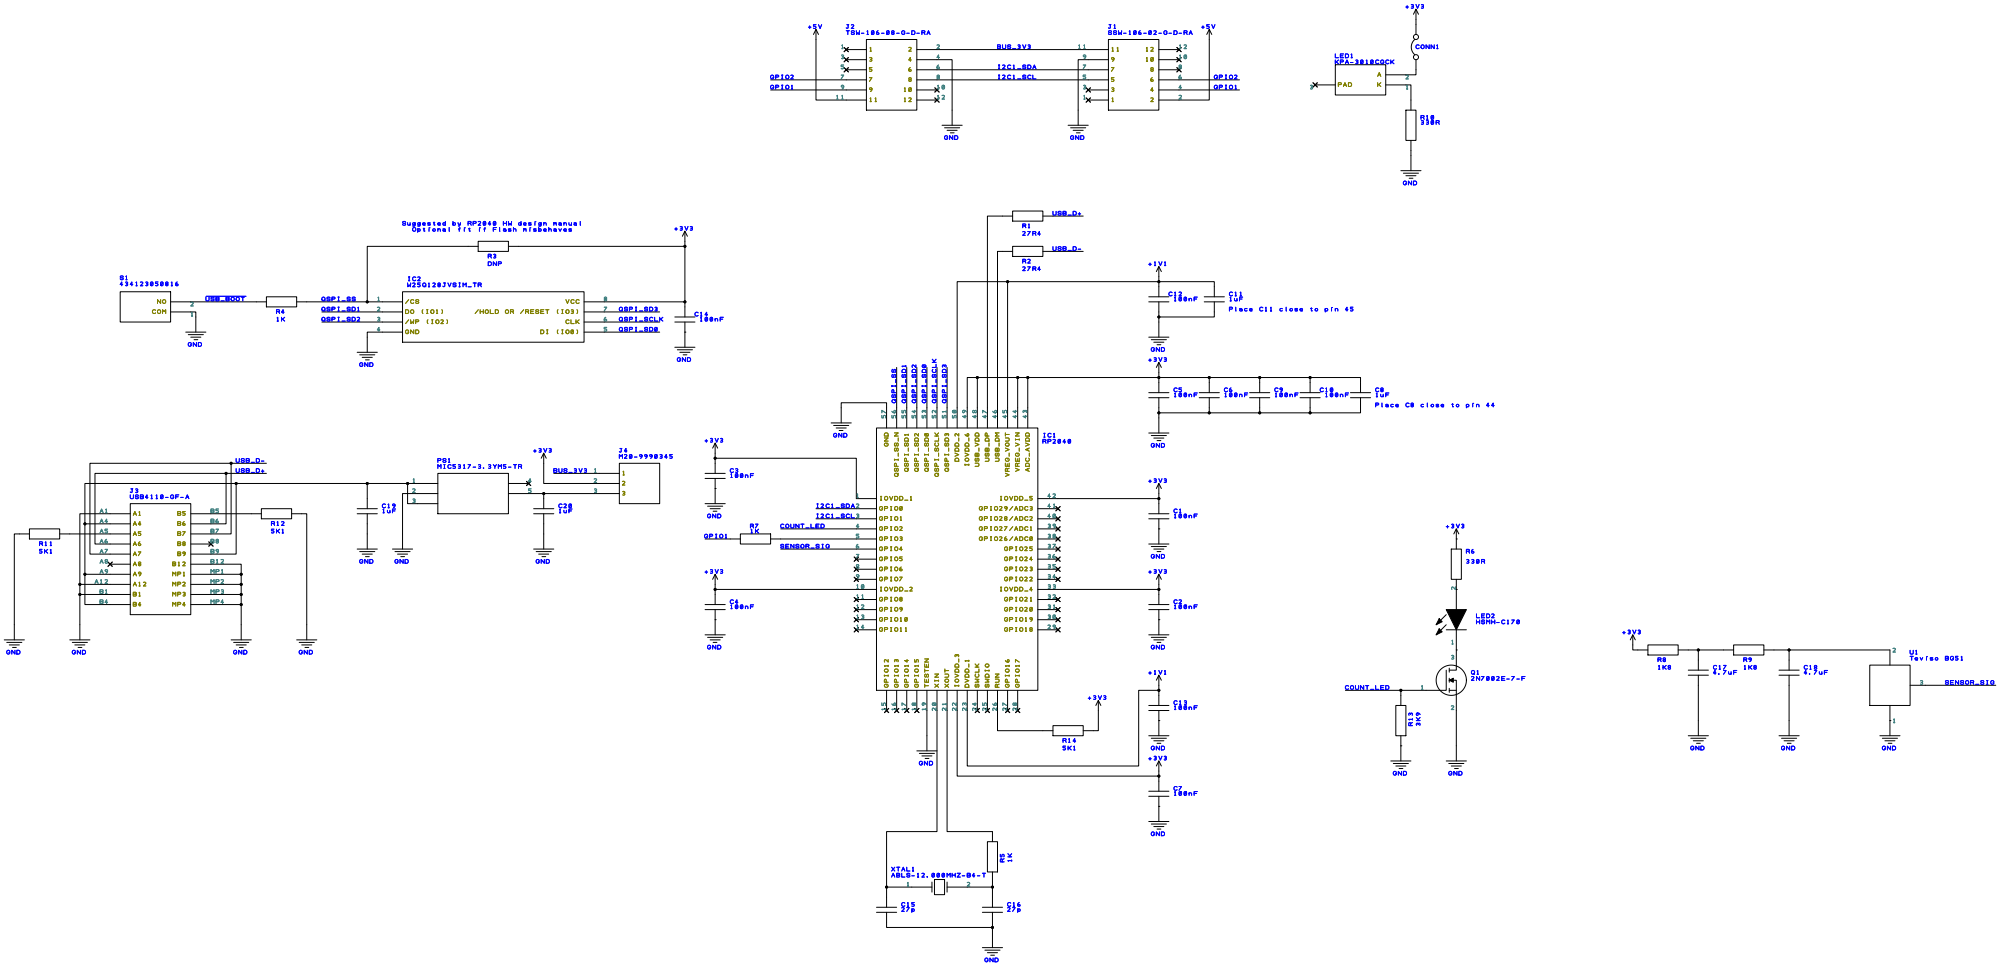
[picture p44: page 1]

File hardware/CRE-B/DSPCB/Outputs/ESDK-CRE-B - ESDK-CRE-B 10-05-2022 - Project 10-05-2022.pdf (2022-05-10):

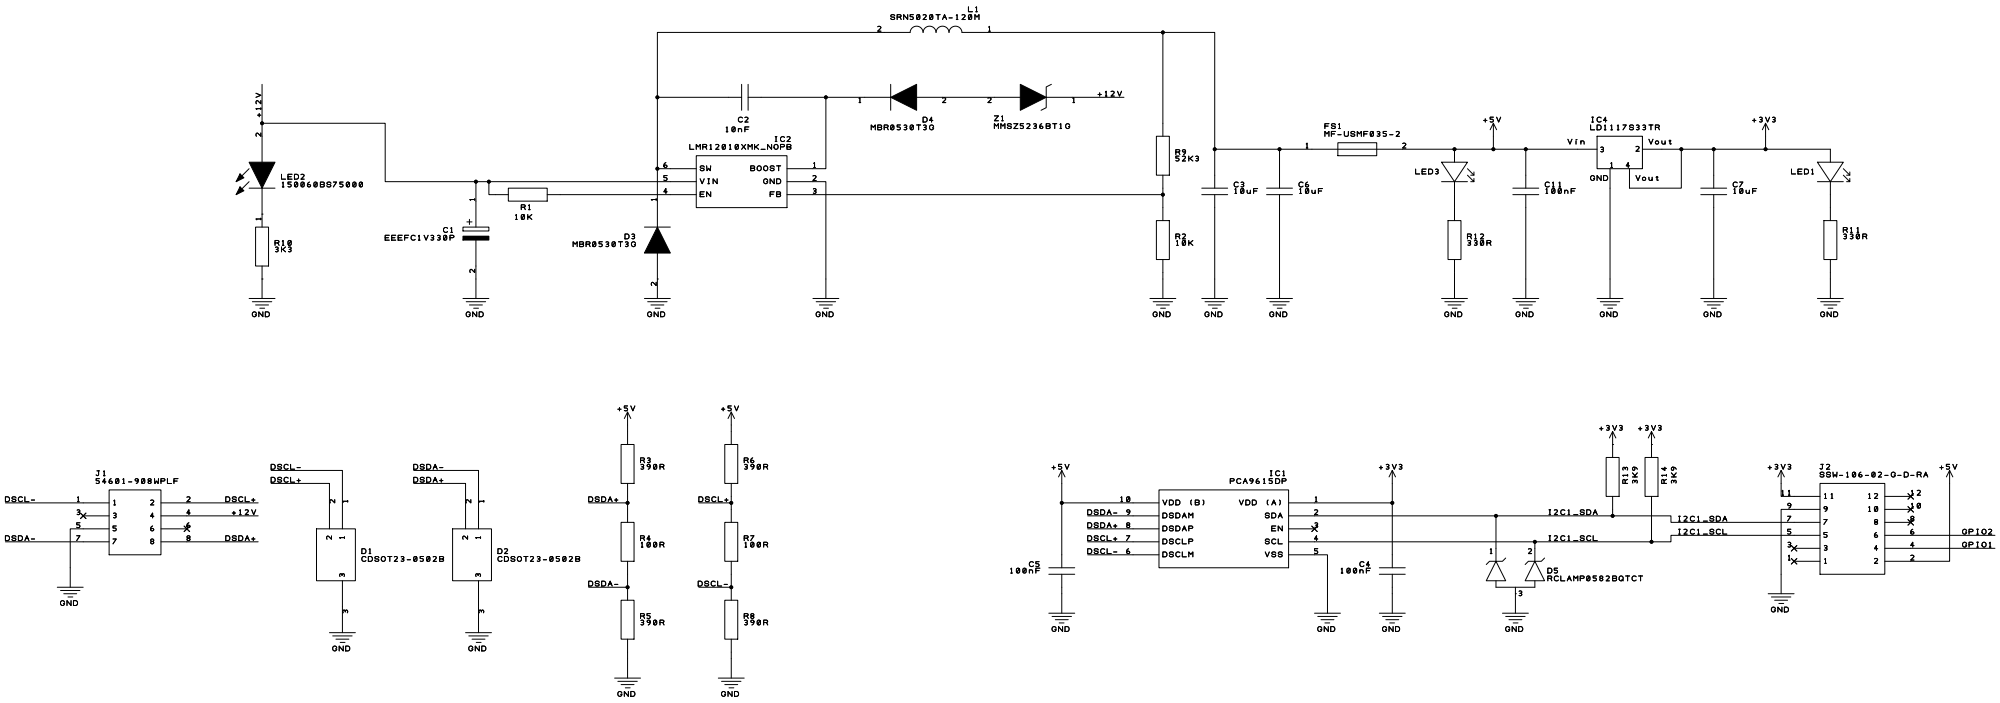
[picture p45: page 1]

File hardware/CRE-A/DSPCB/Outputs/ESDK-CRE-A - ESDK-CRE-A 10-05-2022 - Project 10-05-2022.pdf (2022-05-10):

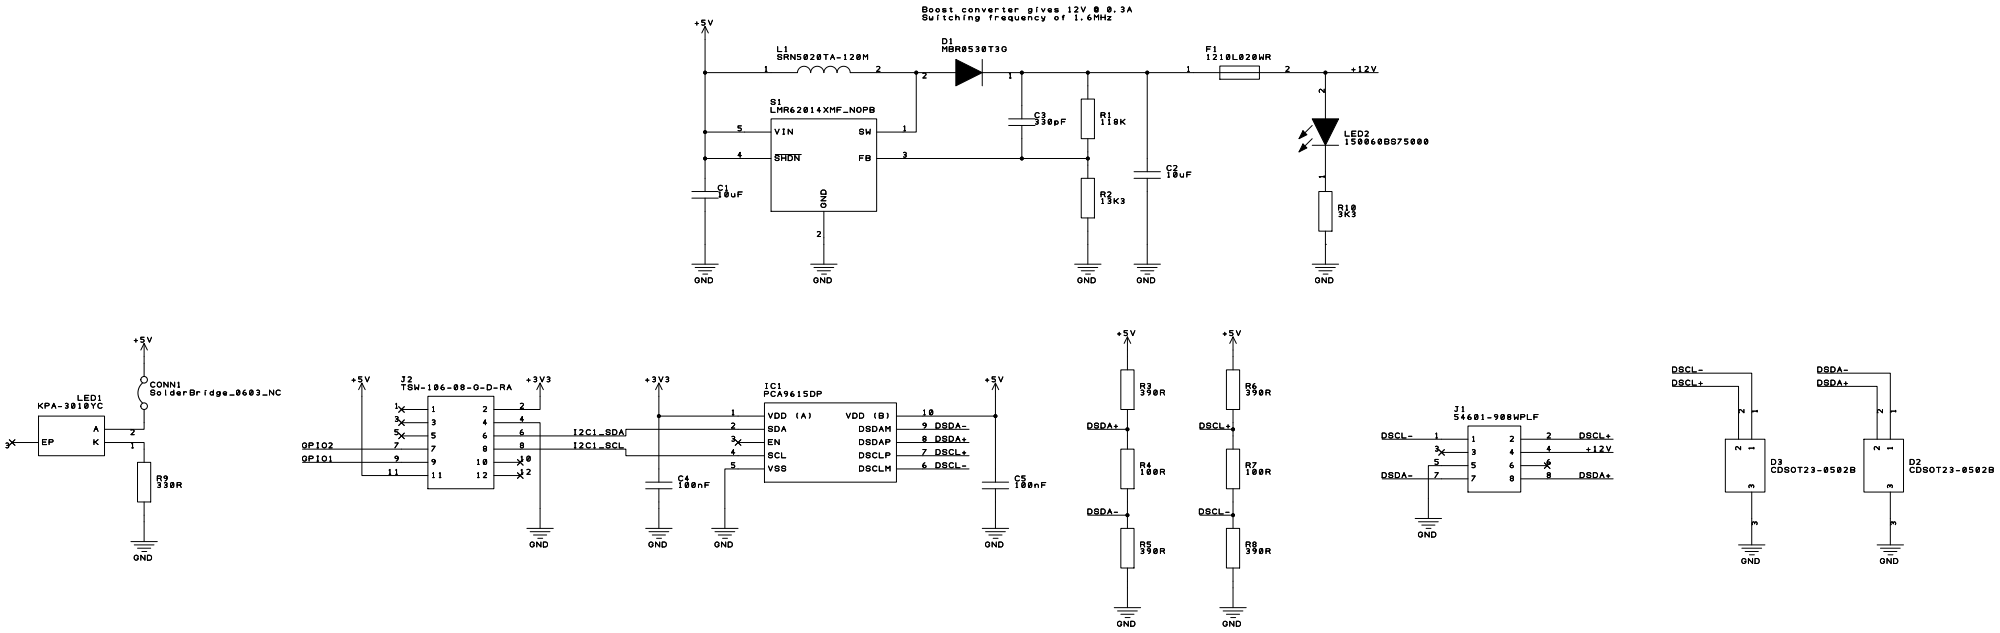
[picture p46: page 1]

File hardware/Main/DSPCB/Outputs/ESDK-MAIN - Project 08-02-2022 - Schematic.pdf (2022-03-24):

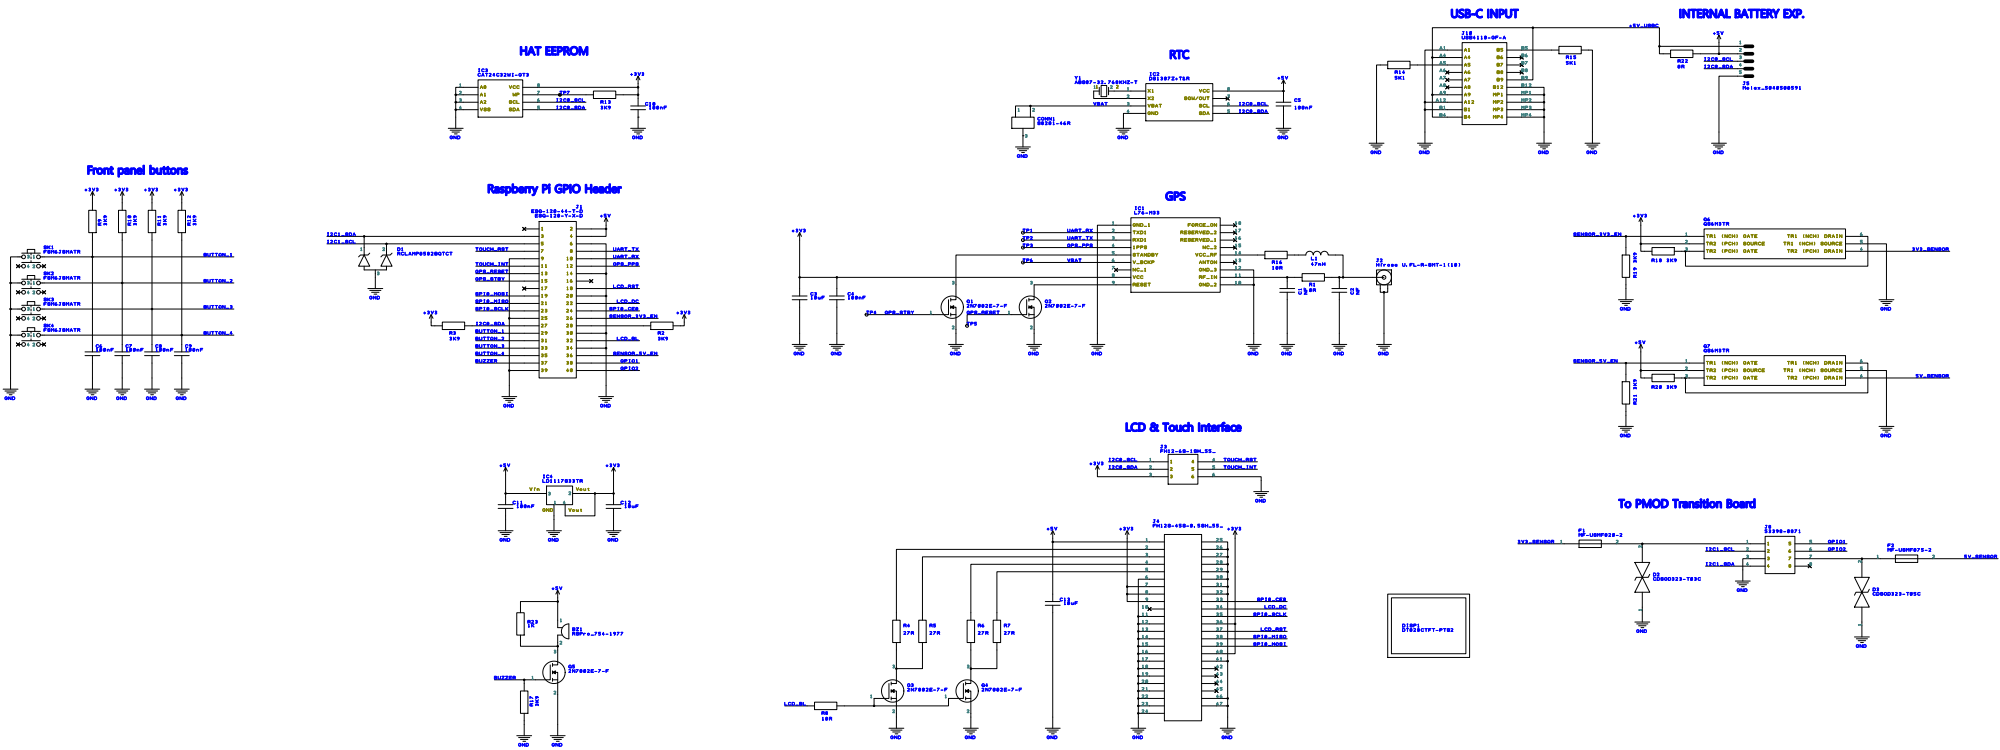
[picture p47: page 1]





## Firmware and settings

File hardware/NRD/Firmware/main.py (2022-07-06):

import gc
import time
import _thread
import math
import machine
from i2c_responder import I2CResponder
from machine import Pin, Timer

sensor = Pin(4, Pin.IN)
led = Pin(2, Pin.OUT)
event_gpio = Pin(3, Pin.OUT)
scl = Pin(1, Pin.IN)

count = 0
event = False

cpm_averaging_time = 10 # CPM averaging time in seconds
current_cpm = 0
last_cpm_count = 0
current_cps = 0
last_cps_count = 0
i2c_data = [0]
led_enabled = True
gpio_output_enabled = False
counter_reset = False

def calculate_moving_average(new_data_point, data_list, average_size):
    # Add fresh data
    data_list.insert(0, new_data_point)
    try:
        # Remove nth item in list
        data_list.pop(average_size)
    except Exception as e:
        pass
    total = 0
    total = sum(data_list)
        
    value = math.ceil(total / len(data_list))
    if(value == None):
        return 0
    else:
        return value

def i2c_thread():
    global current_cps
    global current_cpm
    global led_enabled
    global gpio_output_enabled
    global counter_reset

    i2c = I2CResponder(0, sda_gpio=0, scl_gpio=1, responder_address=0x60)

    i2c_data = [0x0, 0x0]
    i2cTrafficTime = 0
    i2cWdtEnabled = False
    write_data = []
    replyByteCounter = 0

    while True:
        while not i2c.read_is_pending():
            gc.collect()
            
            # Check I2C WDT and reset if necessary
            if(i2cWdtEnabled and time.ticks_diff(time.ticks_ms(), i2cTrafficTime) > 10000):
                print("No I2C traffic with I2C WDT enabled! Resetting")
                machine.reset()
                
            if i2c.write_data_is_available():
                i2cTrafficTime = time.ticks_ms()
                replyByteCounter = 0
                i2c_data = i2c.get_write_data(max_size=2)
                
                if(len(i2c_data) >= 2):
                    # Update LED control variable
                    if(i2c_data[0] == 0x04):
                        if(i2c_data[1] == 0x01):
                            led_enabled = True
                        elif(i2c_data[1] == 0x00):
                            led_enabled = False
                    
                    # Reset all counters
                    if(i2c_data[0] == 0x05 and i2c_data[1] == 0x01):
                        counter_reset = True
                    
                    # Update GPIO event detection output control
                    if(i2c_data[0] == 0x06):
                        if(i2c_data[1] == 0x01):
                            gpio_output_enabled = True
                        elif(i2c_data[1] == 0x00):
                            gpio_output_enabled = False
                    
                    # Update I2C watchdog timeout control
                    if(i2c_data[0] == 0x07):
                        if(i2c_data[1] == 0x01):
                            i2cWdtEnabled = True
                        elif(i2c_data[1] == 0x00):
                            i2cWdtEnabled = False
                        
        i2cTrafficTime = time.ticks_ms()
        # Requested CPS data
        if(i2c_data[0] == 0x01):
            i2c.put_read_data(current_cps)

        # Requested CPM data
        if(i2c_data[0] == 0x02):
            i2c.put_read_data(bytearray(current_cpm.to_bytes(2, 'big'))[replyByteCounter])
            replyByteCounter += 1
        
        # Requested total count
        if(i2c_data[0] == 0x03):
            if(count > 4294967295):
                count_capped = 4294967295
            else:
                count_capped = count
            i2c.put_read_data(bytearray(count_capped.to_bytes(4, 'big'))[replyByteCounter])
            replyByteCounter += 1

        # Return LED enabled status
        if(i2c_data[0] == 0x04):
            i2c.put_read_data(led_enabled)
        
        # Return GPIO output enabled status
        if(i2c_data[0] == 0x06):
            i2c.put_read_data(gpio_output_enabled)
        
        # Return I2C WDT enabled status
        if(i2c_data[0] == 0x07):
            i2c.put_read_data(i2cWdtEnabled)
        
        # Check I2C WDT and reset if necessary
        if(i2cWdtEnabled and time.ticks_diff(time.ticks_ms(), i2cTrafficTime) > 10000):
            print("No I2C traffic with I2C WDT enabled! Resetting")
            machine.reset()

def count_thread():
    global event
    global count
    global cpm_averaging_time
    global current_cpm
    global current_cps
    global led_enabled
    global gpio_output_enabled
    global counter_reset

    ledOnTime = 0
    lastCpsCount = 0
    cpsStartTime = 0
    cpmStartTime = 0
    startOfPulse = False

    cps_sma_list = []
    cpm_sma_list = []
    while True:
        # Check to see if sensor has detected radiation
        if(sensor.value() == True and not startOfPulse):
            startOfPulse = True

        if(sensor.value() == False and startOfPulse):
            startOfPulse = False
            event = True
            count = count + 1

        # Turn on LED if event detected
        if(event and led_enabled and led.value() == False):
            ledOnTime = time.ticks_ms()
            event = False
            led.value(1)
            if(gpio_output_enabled):
                event_gpio.value(1)

        # Turn off LED after 5ms timeout (to make a blink)
        if(led.value() and time.ticks_diff(time.ticks_ms(), ledOnTime) > 5):
            led.value(0)
            if(gpio_output_enabled):
                event_gpio.value(0)

        # Calculate CPS & CPM every second
        if(time.ticks_diff(time.ticks_ms(), cpsStartTime) > 1000):
            current_cps = calculate_moving_average((count - lastCpsCount), cps_sma_list, 5)
            print("CPS: ", current_cps)
            
            # Calculate CPM from CPS * 60, averaged
            current_cpm = calculate_moving_average((current_cps * 60), cpm_sma_list, 5)
            print("CPM: ", current_cpm)
            # Reset tracking variables
            lastCpsCount = count
            cpsStartTime = time.ticks_ms()
        
        # Reset all counters
        if(counter_reset == True):
            current_cps = 0
            lastCpsCount = 0
            count = 0
            cps_sma_list.clear()
            cpm_sma_list.clear()
            counter_reset = False

i2c_thread_handle = _thread.start_new_thread(i2c_thread, ())
count_thread()

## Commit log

2021-08-11 Create SCD4X.py
    Test script for the SCD4x CO2 sensors.
2021-08-12 Create SVM40.py
    Test script for reading the SVM40 eval board (containing the SGP40 VOC sensor and an SHT40 temp/RH sensor).
2021-08-12 Create NO2.py
    Test script for NO2 Click module (LMP91000 AFE and ADC combination)
2021-10-19 First commit of electronics hardware
    Commit of electronics hardware includes:
    - ESDK-MAIN v0.2
    - ESDK-PEA v0.3
    - ESDK-THV v0.2
    - ESDK-CO2 v0.2
    - ESDK-PM2 v0.2
    [ESDK-CO2 (AB_BOM_Template).csv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]
2021-10-20 Reorg and remove desktop.ini files
    [ESDK-CO2 (AB_BOM_Template).csv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]
2021-10-21 Update mainboard BOM
    [ESDK-MAIN (AB_BOM_Template).csv, ESDK-MAIN.sch]
2021-10-26 Update ESDK-MAIN manufacturing BOM
    [ESDK-MAIN (AB_BOM_Template).csv]
2021-11-01 Add device tree overlay sources
    Device tree overlay sources for:
    - ESDK display (including touch screen and backlight)
    - ESDK RTC (on I2C0 therefore custom DT file needed)
2022-03-24 Update gitignore
    [ESDK-MAIN (AB_BOM_Template).csv, ESDK-MAIN (Component Positions CSV).csv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]
2022-03-24 Add ESDK-EEA v0.1
    Files for ESDK-EEA v0.1, including project and manufacturing outputs.
    [ESDK-EEA (AB_BOM_Template).csv, ESDK-EEA (Component Positions CSV).csv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]
2022-03-24 Update ESDK-MAIN to v0.3
    - Fix #4 (U.FL footprint wrong)
    - Add #3 (add power switches to sensor power rails)
    - Add connector for battery expansion
    - Add buzzer support
    [ESDK-MAIN (AB_BOM_Template).csv, ESDK-MAIN (Component Positions CSV).csv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]
2022-04-29 Add CRE boards
    [ESDK-CRE-A (AB_BOM_Template).csv, ESDK-CRE-A (Component Positions CSV).csv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]
2022-05-10 Update CRE-A
    - Swap differential SDA pins
    - Change fuse for one rated to 30Vdc
    [ESDK-CRE-A (AB_BOM_Template).csv, ESDK-CRE-A (Component Positions CSV).csv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]
2022-05-10 Bump CRE-A version number text
    [ESDK-CRE-A.sch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]
2022-05-10 Update CRE-B
    - Bump board version text
    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
    [ESDK-CRE-B - Bottom Copper 04-04-2022.gbr, ESDK-CRE-B - Bottom Copper 10-05-2022.gbr, ESDK-CRE-B - Bottom Resist 04-04-2022.gbr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]
2022-06-15 Add ESDK-NRD board
    - ESDK-NRD v0.1 board design files & manufacturing data
    - ESDK-NRD firmware
    [ESDK-NRD (AB_BOM_Template).csv, ESDK-NRD (Component Positions CSV).csv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]
2022-06-15 Update NRD firmware
    Fix double pulse counting issue
    [main.py]
2022-06-23 Add mechanical files
    - Add DXF of board outlines including through holes
    - Add STEP file of board with major components
    [ESDK-NRD.dxf, ESDK-NRD.step]
2022-06-23 Initial commit of ESDK-FLD
    Initial commit of ESDK-FLD (formaldehyde) sensor module.
    TODO:
    - Add correct power LED
    - Add power LED jumper
    [ESDK-FLD.sch]
2022-06-24 Add ESDK-FLD manufacturing outputs
    [ESDK-FLD (AB_BOM_Template).csv, ESDK-FLD (Component Positions CSV).csv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]
2022-06-27 Add mechanical files
    Added DXF & STEP file of ESDK-CRE-B board.
    [ESDK-CRE-B.dxf, ESDK-CRE-B.step]
2022-06-27 Add mechanical files
    Add DXF & STEP of CRE-A board.
    [CRE-A.step, ESDK-CRE-A.dxf]
2022-06-27 Add mechanical files
    Add DXF & STEP for ESDK-NO2.
    [ESDK-NO2.dxf, ESDK-NO2.step]
2022-07-06 Fix bug with returning maximum count from NRD
    [main.py]
2022-07-06 Fix bug with I2C data being cleared
    [main.py]
2022-07-14 Update ESDK-FLH
    Bum to v0.2
    [ESDK-FLD (AB_BOM_Template).csv, ESDK-FLD (Component Positions CSV).csv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]
2022-12-19 Add ESDK-EEA schematic output
2023-01-09 Update ESDK-MAIN to v1.0
    - Updated RS DesignSpark Logo
    - Added OSHWA certification badge
    - Updated manufacturing outputs
    [ESDK-MAIN - Bottom Copper 09-01-2023.gbr, ESDK-MAIN - Bottom Paste 09-01-2023.gbr, ESDK-MAIN - Bottom Resist 09-01-2023.gbr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]
2023-01-09 Update ESDK-PEA to v1.0
    - Updated version & copyright text
    - Add OSHW certification details as text (logo is too large for PCB)
    - Update manufacturing outputs
    [ESDK-PEA (AB_BOM_Template).csv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]
2023-01-09 Update ESDK-THV to v1.0
    - Add new RS DesignSpark logo
    - Add OSHWA certification logo
    - Update version & copyright text
    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
    [ESDK-THV - Bottom Copper 09-01-2023.gbr, ESDK-THV - Bottom Resist 09-01-2023.gbr, ESDK-THV - Drill Ident Drawing - [Through Hole] 09-01-2023.gbr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]
2023-01-09 Update ESDK-CO2 to v1.0
    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
    [ESDK-CO2 - Bottom Copper 09-01-2023.gbr, ESDK-CO2 - Bottom Resist 09-01-2023.gbr, ESDK-CO2 - Drill Ident Drawing - [Through Hole] 09-01-2023.gbr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]
2023-01-09 Update ESDK-PM2 to v1.0
    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
    [ESDK-PM2 - Bottom Copper 09-01-2023.gbr, ESDK-PM2 - Bottom Resist 09-01-2023.gbr, ESDK-PM2 - Drill Ident Drawing - [Through Hole] 09-01-2023.gbr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]
2023-01-09 Update ESDK-EEA to v1.0
    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
    [ESDK-EEA - Bottom Copper 09-01-2023.gbr, ESDK-EEA - Bottom Copper 14-02-2022.gbr, ESDK-EEA - Bottom Resist 09-01-2023.gbr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]
2023-01-09 Update ESDK-FDH to v1.0
    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
    [ESDK-FLD - Bottom Copper 09-01-2023.gbr, ESDK-FLD - Bottom Resist 09-01-2023.gbr, ESDK-FLD - Drill Ident Drawing - [Through Hole] 09-01-2023.gbr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]
2023-01-09 Update ESDK-NRD to v1.0
    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
    [ESDK-NRD - Bottom Copper 09-01-2023.gbr, ESDK-NRD - Bottom Resist 09-01-2023.gbr, ESDK-NRD - Drill Ident Drawing - [Through Hole] 09-01-2023.gbr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]
2023-01-09 Update ESDK-NO2 to v1.0
    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
    [ESDK-NO2 - Bottom Copper 09-01-2023.gbr, ESDK-NO2 - Bottom Copper 17-02-2022.gbr, ESDK-NO2 - Bottom Resist 09-01-2023.gbr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]
2023-01-09 Update ESDK-CRE-A to v1.0
    - Add OSHWA certification text
    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
    [ESDK-CRE-A - Bottom Copper 09-01-2023.gbr, ESDK-CRE-A - Bottom Resist 09-01-2023.gbr, ESDK-CRE-A - Drill Ident Drawing - [Through Hole] 09-01-2023.gbr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]
2023-01-09 Update ESDK-CRE-B to v1.0
    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
    [ESDK-CRE-B - Bottom Copper 09-01-2023.gbr, ESDK-CRE-B - Bottom Resist 09-01-2023.gbr, ESDK-CRE-B - Drill Ident Drawing - [Through Hole] 09-01-2023.gbr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]
2023-01-09 Update ESDK-NO2 manufacturing data
    Gerbers seemed to have pin numbers plotted in there (default setting had changed in DSPCB?) which caused issues when uploaded to Eurocircuits. Turned off pin number plotting and generated fresh gerbers.
    [ESDK-NO2 - Bottom Copper 09-01-2023.gbr, ESDK-NO2 - Bottom Resist 09-01-2023.gbr, ESDK-NO2 - Drill Ident Drawing - [Through Hole] 09-01-2023.gbr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]
2023-01-10 Update ESDK-NRD BOM
    Some resistors had missing values, updated manufacturer and MPN.
    [ESDK-NRD (AB_BOM_Template).csv, ESDK-NRD.sch]
2023-01-10 Update ESDK-FLD BOM
    Missing manufacturer and MPN on Sensirion module
    [ESDK-FLD (AB_BOM_Template).csv, ESDK-FLD.sch]
2023-01-10 Update ESDK-EEA BOM
    Added missing manufacturer and MPN for 3-pin header
    [ESDK-EEA (AB_BOM_Template).csv, ESDK-EEA.sch]

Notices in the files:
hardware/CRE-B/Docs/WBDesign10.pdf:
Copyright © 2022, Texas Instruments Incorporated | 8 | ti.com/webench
